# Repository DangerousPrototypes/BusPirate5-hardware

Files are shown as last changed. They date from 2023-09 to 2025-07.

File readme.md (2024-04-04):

# Bus Pirate 5

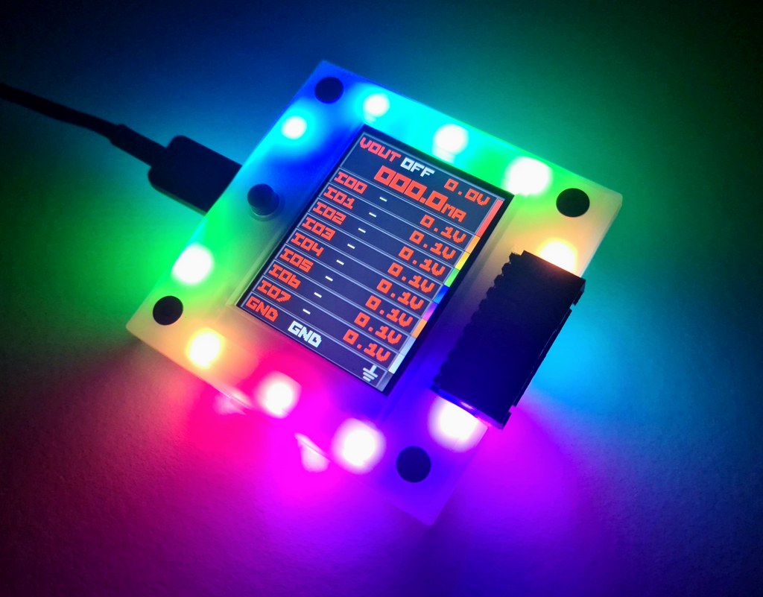
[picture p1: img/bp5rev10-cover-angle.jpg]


Bus Pirate 5 is the latest edition of the universal serial interface trusted by hackers since 2008.

Can't get a chip to work? Is it the circuit, code, bad part or a burned out pin? The Bus Pirate sends commands over common serial protocols (1-Wire, I2C, SPI, UART, MIDI, serial LEDs, etc) so you can get to know a chip before prototyping. Updated with tons of new features, talking to chips and probing interfaces is more fun than ever!

## Resources

- [Download the latest firmware build](https://forum.buspirate.com/t/bus-pirate-5-auto-build-main-branch/20/99999)
- [Get help and chat in the forum](https://forum.buspirate.com/)
- [Firmware documentation](https://firmware.buspirate.com/) ([source](https://github.com/DangerousPrototypes/BusPirate5-docs-firmware))
- [Hardware documentation](https://hardware.buspirate.com/) ([source](https://github.com/DangerousPrototypes/BusPirate5-docs-hardware))
- [Hardware repo](https://github.com/DangerousPrototypes/BusPirate5-hardware)
- [Firmware repo](https://github.com/DangerousPrototypes/BusPirate5-firmware)

## VT100 terminal interface

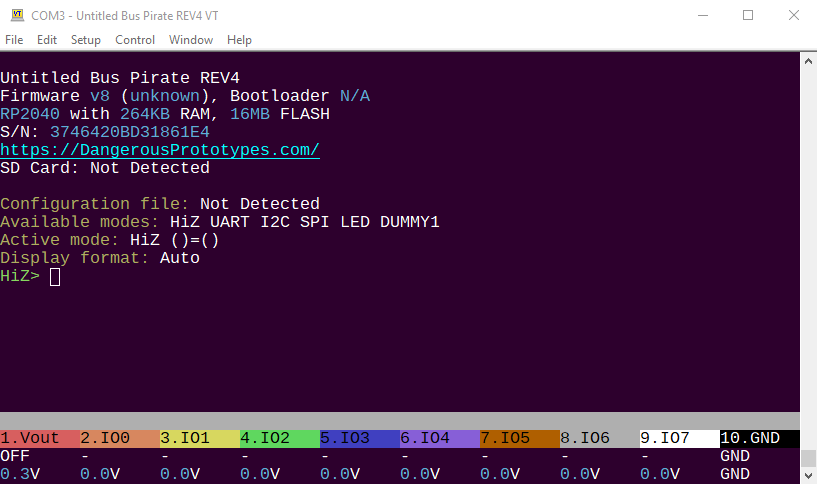
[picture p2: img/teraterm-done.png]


VT100 terminal emulation supports color and a live statusbar view of the voltage and functions on each pin. Type simple commands into the terminal, the Bus Pirate translates them into popular serial protocols and displays the response. Learn how a chip works without touching a line of code.

## Specifications

- Raspberry Pi RP2040 with 128Mbit program flash
- 8 powerful IO pins - Support multiple protocols from 1.2-5volts. Analog voltage measurement and optional 10K pull-ups on all pins
- 1-5volt output power supply - 0-500mA current limit, current sense, resettable fuse and protection circuit
- 1Gbit NAND flash - Store settings and files. Appears as a USB drive.
- LCD - A beautiful 240x320 pixel color IPS (all angle viewing) LCD acts as a pin label, while also showing the voltage on each pin and the current consumption of the programmable power supply unit
- 18 RGB LEDs - It's customary to have an indicator LED, so to check that box we added 16 SK6812 RGB LEDs.
- Just one button - 18 party LEDs but just one button!
- 1-Wire, I2C, SPI, UART, MIDI, serial LEDs supported, more to come!

Bus Pirate 5 is the universal serial interface tool designed by hackers, for hackers. It's crammed full of hardware and firmware features to make probing chips pleasant and easy.

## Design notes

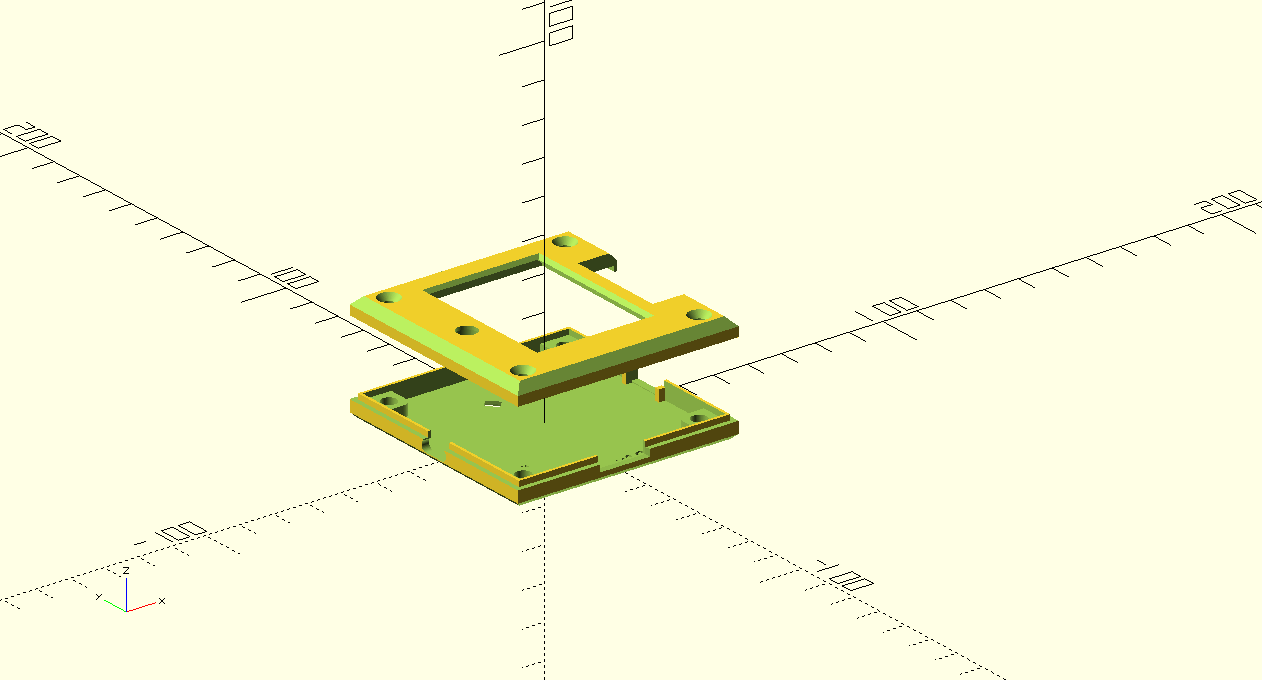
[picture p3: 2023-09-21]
enclosure/BusPirate5REV8-v10-fit.png

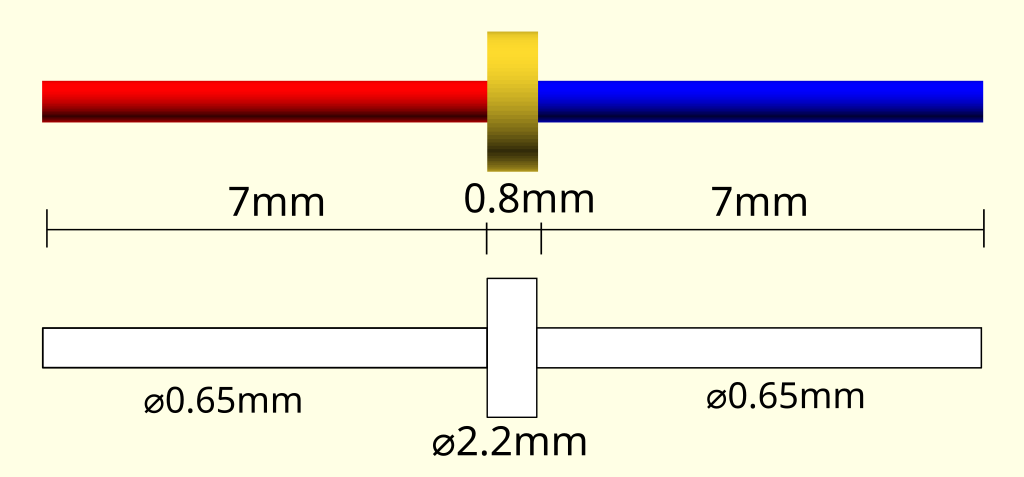
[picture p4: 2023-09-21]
milled-pins/pin-milled-rev2.png

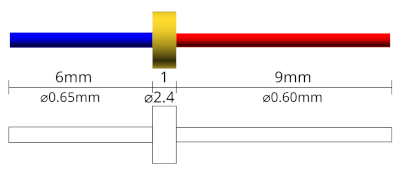
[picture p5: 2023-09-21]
milled-pins/pin-milled-rev1.png

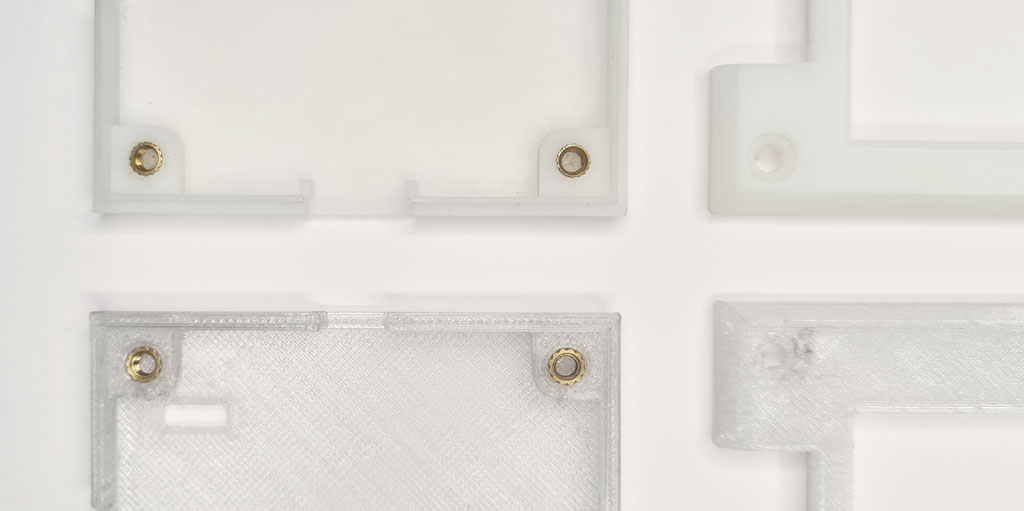
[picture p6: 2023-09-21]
enclosure/heat-set-inserts-bottom.jpg

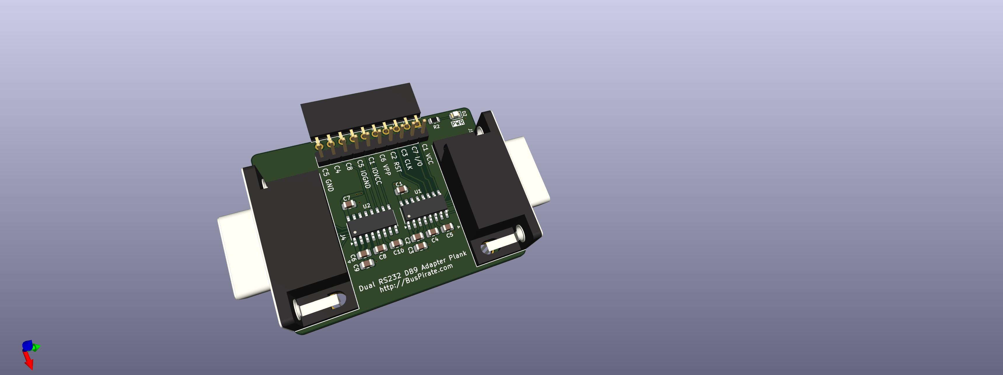
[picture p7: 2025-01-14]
development/adapter-kaybee-plank-1REV0/kaybee-plank.jpg

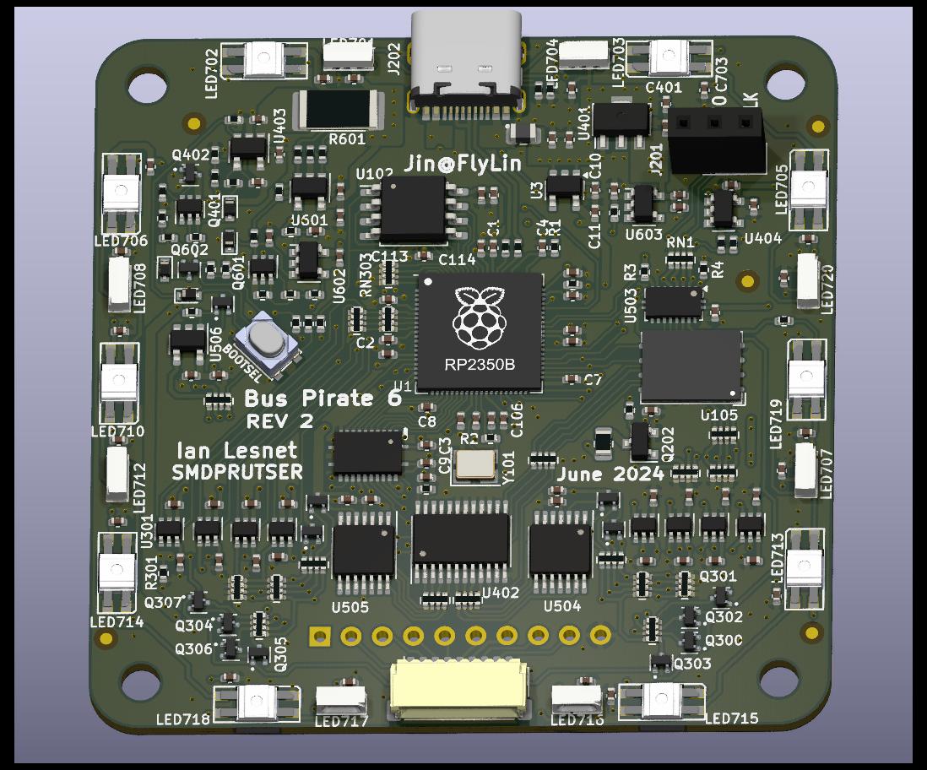
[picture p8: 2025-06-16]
bus_pirate_pcb/6-REV2B/6r2-pcb-top.jpg

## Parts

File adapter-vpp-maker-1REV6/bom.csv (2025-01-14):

Reference | Value | Datasheet | Footprint | Qty | DNP
C13 | 0.1uF | ~ | Capacitor_SMD:C_0805_2012Metric_Pad1.18x1.45mm_HandSolder | 1
C14 | 10uF/16V/CASE-A | ~ | Capacitor_Tantalum_SMD:CP_EIA-3216-18_Kemet-A | 1
C15 | 47uF/25V/CASE-D | ~ | Capacitor_Tantalum_SMD:CP_EIA-7343-31_Kemet-D | 1
D1 | LED | ~ | LED_SMD:LED_0805_2012Metric | 1
D2 | BAT54W | https://assets.nexperia.com/documents/data-sheet/BAT54W_SER.pdf | Package_TO_SOT_SMD:SOT-23 | 1
J1,J2 | Conn_01x10 | ~ | -- mixed values -- | 2
J4 | Conn_01x08 | ~ | Connector_PinHeader_2.54mm:PinHeader_1x08_P2.54mm_Horizontal | 1
L1 | 680uH | ~ | Library:IND-SMD_L5.8-W5.2 | 1
Q1 | MMBT3906 | https://www.onsemi.com/pub/Collateral/2N3906-D.PDF | Package_TO_SOT_SMD:SOT-23 | 1
Q2,Q3,Q4 | MMBT3904 | https://www.onsemi.com/pub/Collateral/2N3903-D.PDF | Package_TO_SOT_SMD:SOT-23 | 3
R1 | 2K | ~ | Resistor_SMD:R_0805_2012Metric | 1
R22 | 4.7K?? | ~ | Resistor_SMD:R_0805_2012Metric | 1
R23 | 100K | ~ | Resistor_SMD:R_0805_2012Metric | 1
R24 | 2.7K | ~ | Resistor_SMD:R_0805_2012Metric | 1
R25,R27,R29 | 10K | ~ | Resistor_SMD:R_0805_2012Metric | 3
R28 | 100R | ~ | Resistor_SMD:R_0805_2012Metric | 1

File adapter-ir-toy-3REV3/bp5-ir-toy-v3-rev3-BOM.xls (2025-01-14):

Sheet: bp5-ir-toy-revC
Source: | C:\buspirate5-hardware\dev\bp5-ir-toy-revC\bp5-ir-toy-revC.kicad_sch
Date: | 6/5/2024 1:26:14 PM
Tool: | Eeschema 7.0.7
Generator: | C:\Program Files\KiCad\7.0\bin\scripting\plugins/bom_csv_grouped_by_value.py
Component Count: | 31
Collated Components:
Item | Qty | Reference(s) | Value | LibPart | Footprint | Datasheet | DNP | Availability | Check_prices | Description | MF | MP | Package | Price | Purchase-URL | Sim.Device | Sim.Pins | Sim.Type | SnapEDA_Link
1 | 3 | C1, C2, C3 | 4.7uF | Device:C | Capacitor_SMD:C_0805_2012Metric | ~
2 | 2 | C4, C5 | 0.22uF | Device:C | Capacitor_SMD:C_0805_2012Metric | ~
3 | 1 | D1 | LED | Device:LED | LED_SMD:LED_0805_2012Metric | ~
4 | 3 | D2, D7, D10 | VSLB3940 | Device:LED | LED_THT:LED_D5.0mm_Horizontal_O1.27mm_Z3.0mm_IRBlack | ~
5 | 6 | D3, D4, D5, D6, D8, D9 | BAS16J/1N4148 | Diode:1N4148W | Diode_SMD:D_SOD-323F | https://www.vishay.com/docs/85748/1n4148w.pdf |  |  |  |  |  |  |  |  |  | D | 1=K 2=A
6 | 1 | J1 | Conn_01x10 | Connector_Generic:Conn_01x10 | Connector_PinSocket_2.54mm:PinSocket_1x10_P2.54mm_Horizontal | ~
7 | 1 | J2 | Conn_01x10 | Connector_Generic:Conn_01x10 | Connector_PinHeader_2.54mm:PinHeader_1x10_P2.54mm_Vertical | ~
8 | 3 | Q1, Q2, Q3 | BC818/S8050 | Simulation_SPICE:NPN | Library:SOT95P237X111-3N | ~ |  |  |  |  |  |  |  |  |  | NPN | 1=C 2=B 3=E | GUMMELPOON
9 | 1 | R1 | 2K | Device:R | Resistor_SMD:R_0805_2012Metric | ~
10 | 3 | R2, R7, R9 | 6R8 | Device:R | Resistor_SMD:R_1206_3216Metric | ~
11 | 3 | R3, R4, R8 | 3K6 | Device:R | Resistor_SMD:R_0805_2012Metric | ~
12 | 2 | R5, R6 | 390R | Device:R | Resistor_SMD:R_0805_2012Metric | ~
13 | 1 | U1 | TSOP4438/ IRM-3638J15 | TSOP4838:TSOP4838 | Library:TSOP18XX |  |  | In Stock | https://www.snapeda.com/parts/TSOP4838/Vishay+Semiconductor+Opto+Division/view-part/?ref=eda | DIODE, IR EMITTING, 38 KHZ, ANGLE OF HALF TRANSMISSION DISTANCE +/-45DEG/C | Vishay / Small Signal & Opto Products (SSP) TSOP4838 | Vishay | TSOP4838 | DIP-3 Vishay | None | https://www.snapeda.com/api/url_track_click_mouser/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 |  |  |  | https://www.snapeda.com/parts/TSOP4838/Vishay+Semiconductor+Opto+Division/view-part/?ref=snap
14 | 1 | U3 | QSE159 | Interface_Optical:QSE159 | OptoDevice:ONSemi_QSE15x | http://www.onsemi.com/pub/Collateral/QSE159-D.pdf
 |  |  | IRM-3638J15 | EVERLIGHT | 单价1.0
 |  |  | VSLB3940 | VISHAY | 单价2.1

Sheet: Sharp-appnote
I (Current) | 100 | 100 | 200 | 200 | 300 | 300 |  | TSAL6100 | 1N4148
VCC | 5 | 4.75 | 5 | 4.75 | 5 | 4.75
Vz | 1.4 | 1.4 | 2 | 2 | 2.2 | 2.2
Vbe | 0.9 | 0.9 | 0.95 | 0.95 | 1 | 1
Vce(sat) | 0.1 | 0.1 | 0.18 | 0.18 | 0.25 | 0.25
Vf | 1.35 | 1.35 | 1.5 | 1.5 | 1.6 | 1.6
N< | 3.259259259 | 3.074074074 | 2.513333333 | 2.346666667 | 2.21875 | 2.0625
 |  |  |  |  |  |  | hFE | Vbe | Vce(sat)

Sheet: sensors
 | Model | Frequency | Typical Application | Note | Everlight | Opti-fake |  |  |  |  | Barrier | C | R | Pullup
Vishay | TSSP4038 (3元) | 38kHz | Barrier | Widely Available | IRM-3638J7(1.6元) |  |  |  |  |  | TSSP4038 (3元) | 0.1uF | 100R | X
Vishay | TSMP58000 | 20 → 60kHz | Learner | Obsolete |  | OS1200MW-A1 (3元) (http://os-opto.com/wap/acp_view.asp?id=235) |  |  |  |  | IRM-3638J7(1.6元) | >2.2uF | 47-200R | >10K
Vishay |  | 20 → 60kHz | Learner | New TSMP58000 |  |  |  |  |  |  | Learner
Vishay | TSOP34436 (8元) | 36kHz | RC5/6 |  |  |  |  |  |  |  | TSMP98000 (7元) | 4.7uF | 100R | 4.7K
Vishay | TSOP34438 (8元) | 38kHz | NEC |  | IRM-3638T (0.78元) | OS-883YM-MS (1.2元) (http://os-opto.com/wap/acp_view.asp?id=195) |  |  |  |  | OS1200MW-A1 (3元) (http://os-opto.com/wap/acp_view.asp?id=235) | 0.1uF + 10-47uF | 47/10 (5V/3V) | ??? 10K?
Vishay | TSOP4840 (5元) | 40kHz | SONY |  |  |  |  |  |  |  | 38kHz
Vishay | TSOP2256 (5元) | 56kHz | RCA | EOL |  |  |  |  |  |  | TSOP34438 (8元) | Unk | Unk | X
 |  |  |  |  |  |  |  |  |  |  | OS-883YM-MS (1.2元) (http://os-opto.com/wap/acp_view.asp?id=195) | >47uF | 100R | >10K
 |  |  |  |  |  |  |  |  |  |  | IRM-3638T (0.78元) | >2.2uF | 47-200R | >10K
 |  |  |  |  |  |  |  |  |  |  | 56kHz
 |  |  |  |  |  |  |  |  |  |  | TSOP2256 (5元) | Unk | Unk | X
 |  |  |  | Sensor | Brand | Part | C | R | Pull-up | Cost
 |  |  |  | Barrier | Everlight | IRM-3638J7 | 4.7uF | 100R | 10K | 1.6
 |  |  |  | Learner | Os-opto | OS1200MW-A1 (http://os-opto.com/wap/acp_view.asp?id=235) | 4.7uF | 100R | 10K | 3
 |  |  |  | 38kHz (36-40kHz effective) | Everlight | IRM-3638T | 4.7uF | 100R | 10K | 0.78 | 9 learner with 10K
 |  |  |  | 56kHz | CHQ | CHQ0038L-56kHz | 4.7uF | 100R | >20K?? | 0.78

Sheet: TX current
 |  |  |  |  |  |  |  |  |  |  |  |  |  | Head room for dissipation, negative is bad :)
IR LED | IR LED Vf | IR LED Ie (mA) | Diode (D2/D3) | D2/D3 Vf | Transistor (T1) | T1 Vfp-n | T1 Dissipation (W) | Vb | Vbe | Ve | R4 (Ohms) | R4 P (Watts) | T1 P (Watts) | T1 P (spare) | R5 (K Ohms)
Generic | 1.35 | 100 | BAS16J | 0.7 | BC818 | 0.7 | 0.31 | 1.4 | 0.7 | 0.7 | 7 | 0.07 | 0.295 | 0.015 | 3.6
VSLB3940 | 1.35 | 100 | BAS16J (actual) | 0.715 | BC818 (actual) | 0.7 | 0.225 | 1.43 | 0.7 | 0.73 | 7.3 | 0.07 | 0.292 | -0.067 | 3.57
VSLB3940 | 2.7 | 300 | 1N4148 | 0.715 | S8050 | 0.7 | 0.3 | 1.43 | 0.7 | 0.73 | 2.433333333 | 0.21 | 0.471 | -0.171 | 3.57
2 * TASL6100 | 3.2 | 300 |  | 1.1 |  | 1 | 0.3 | 2.2 | 1 | 1.2 | 4 | 0.3 | 0.18 | 0.12 | 2.8
 | 3.2 | 200 |  | 1.1 |  | 1 | 0.3 | 2.2 | 1 | 1.2 | 6 | 0.2 | 0.12 | 0.18 | 2.8
Ie is emitter current (typically 100ma)
Vb is the combined Vf of diodes D2 and D3 (see datasheet), typically 0.7V. Vb = Vf_D2 + Vf_D3 = (0.7V + 0.7V) = 1.4V
Vbe is the Vf the transistor p-n union (see datasheet), typically 0.7V
Solving R4 for 100mA current with a BC818 transistor, and BAS16J diode:
R4 = Ve/Ie =(((Vf_D2 + Vf_D3)-Vbe)/Ie) = ((1.4V - 0.7V)/100mA) = 7ohms |  |  |  |  |  |  |  |  |  | 0.1748251748
Resistor power dissipation is well below the 0.125W max of the 1206 resistor used for R4:
P = Ie * Vbe = (100mA*0.7V) = 0.070W
For an IR LED with a forward voltage (Vf) of 1.35 volts the power dissipation is 0.295W, nearly the rated 0.310W of the BC818 transistor in an SOT-23 package. This is probably fine because we’re calculating the worst case scenario of a continues 100mA load, IR transmissions are likely to be short and at a 50% duty cycle.
P =((Vcc-Vf_IRDIODE) - Ve ) * Ie = ((5.0V-1.35V)-0.7V)*100mA = 0.295W
R5 puts the transistor in saturation and limits the current through diodes D2 and D3. For 1mA at 5volts:
R5 = (Vcc - Vb)/I_limit = ((5V-1.4V)/1mA) = 3600ohms

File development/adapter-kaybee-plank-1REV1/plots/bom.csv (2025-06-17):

Item | Qty | Reference(s) | Value | Footprint | szlcsc_partnum
1 | 3 | C1, C2, C3 | 47uF/CL21A226MAYNNNE | Capacitor_SMD:C_0805_2012Metric | C602037
2 | 1 | D2 | LED | LED_SMD:LED_0805_2012Metric
3 | 1 | D401 | 1N4148WT | Diode_SMD:D_SOD-523 | C2828426
4 | 2 | J1, J4 | Mini-DIN-6 | connector-mini-din-6:Connector_Mini-DIN_Female_6Pin_2rows | C77848
5 | 1 | J2 | Conn_01x10 | Connector_PinSocket_2.54mm:PinSocket_1x10_P2.54mm_Horizontal
6 | 1 | J5 | USB_A | Connector_USB:USB_A_CONNFLY_DS1095-WNR0 | C456018
7 | 1 | J7 | TYPE-C-31-M-12 | TYPE-C-31-M-12:HRO_TYPE-C-31-M-12 | C2858270
8 | 2 | J8, J9 | Conn_01x02_Pin | Connector_PinHeader_2.54mm:PinHeader_1x02_P2.54mm_Vertical | C2905434
9 | 4 | L1, L2, L4, L5 | CBW201209U300T | Inductor_SMD:L_0805_2012Metric | C139190
10 | 1 | Q401 | BCM857BS-7-F | Package_TO_SOT_SMD:SOT-363_SC-70-6 | C105896
11 | 1 | Q402 | BC2301T 2.8A | Package_TO_SOT_SMD:SOT-523 | C21714127
12 | 2 | R1, R5 | 5.1K | Resistor_SMD:R_0805_2012Metric | C27834
13 | 2 | R2, R3 | 2K | Resistor_SMD:R_0805_2012Metric | C2907315
14 | 1 | R408 | 68K | Resistor_SMD:R_0805_2012Metric | C17801
15 | 1 | R410 | 10K | Resistor_SMD:R_0805_2012Metric | C17414
16 | 1 | R412 | 100K | Resistor_SMD:R_0805_2012Metric | C149504
17 | 1 | SW1 | SW_SPDT | Button_Switch_SMD:SW_SPDT_PCM12 | C431540

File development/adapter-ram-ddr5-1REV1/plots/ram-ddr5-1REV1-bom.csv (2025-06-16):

Item | Qty | Reference(s) | Value | Footprint | szlcsc_partnum
1 | 2 | C4, C5 | 10uF/6.3V | Capacitor_SMD:C_0805_2012Metric | C307525
2 | 2 | D2, D3 | LED | LED_SMD:LED_0805_2012Metric
3 | 1 | J1 | DDR504111002KQ | footprints:AMPHENOL_DDR504111002KQ
4 | 1 | J2 | Conn_01x10 | Connector_PinSocket_2.54mm:PinSocket_1x10_P2.54mm_Horizontal
6 | 1 | J4 | 10160554-001SHLF | footprints:AMPHENOL_10160554-001SHLF
7 | 2 | Q1, Q2 | BSS138 | Package_TO_SOT_SMD:SOT-23 | C65189
8 | 1 | Q5 | BC807 | Package_TO_SOT_SMD:SOT-23 | C21714130
9 | 1 | Q6 | BC817 | Package_TO_SOT_SMD:SOT-23 | C39828
10 | 3 | R2, R12, R13 | 6.8K | Resistor_SMD:R_0805_2012Metric | C17772
11 | 4 | R3, R4, R6, R7 | 10K | Resistor_SMD:R_0805_2012Metric | C17604
12 | 1 | R8 | 1K | Resistor_SMD:R_0805_2012Metric | C17513
13 | 1 | R10 | 680R | Resistor_SMD:R_0805_2012Metric | C17798
14 | 1 | R11 | 330R | Resistor_SMD:R_0805_2012Metric | C17630
15 | 1 | U2 | ME6206A33XG | Package_TO_SOT_SMD:SOT-23 | C161345

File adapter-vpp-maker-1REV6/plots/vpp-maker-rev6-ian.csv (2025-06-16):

Source: | C:\buspirate5-hardware\vpp-maker-rev6-ian\vpp-maker-rev6-ian.kicad_sch
Date: | 2024-08-13T17:15:38+0200
Tool: | Eeschema 8.0.3
Generator: | C:\Program Files\KiCad\8.0\bin\scripting\plugins/bom_csv_grouped_by_value.py
Component Count: | 22
Collated Components:
Item | Qty | Reference(s) | Value | LibPart | Footprint | Datasheet | DNP | Datasheet | Description | Footprint | MPN
1 | 1 | C13 | 0.1uF | Device:C_Small | Capacitor_SMD:C_0805_2012Metric_Pad1.18x1.45mm_HandSolder | ~ |  | ~ | Unpolarized capacitor, small symbol | Capacitor_SMD:C_0805_2012Metric_Pad1.18x1.45mm_HandSolder
2 | 1 | C14 | 10uF/16V/CASE-A | Device:C_Polarized | Capacitor_Tantalum_SMD:CP_EIA-3216-18_Kemet-A | ~ |  | ~ | Polarized capacitor | Capacitor_Tantalum_SMD:CP_EIA-3216-18_Kemet-A
3 | 1 | C15 | 47uF/25V/CASE-D | Device:C_Polarized | Capacitor_Tantalum_SMD:CP_EIA-7343-31_Kemet-D | ~ |  | ~ | Polarized capacitor | Capacitor_Tantalum_SMD:CP_EIA-7343-31_Kemet-D
4 | 1 | D1 | LED | Device:LED | LED_SMD:LED_0805_2012Metric | ~ |  | ~ | Light emitting diode | LED_SMD:LED_0805_2012Metric
5 | 1 | D2 | BAT54W | Diode:BAT54W | Package_TO_SOT_SMD:SOT-23 | https://assets.nexperia.com/documents/data-sheet/BAT54W_SER.pdf |  | https://assets.nexperia.com/documents/data-sheet/BAT54W_SER.pdf | Schottky barrier diode, SOT-323 | Package_TO_SOT_SMD:SOT-23
6 | 1 | D3 | BZT52C18W (18V) | Device:D_Zener_Small | Diode_SMD:D_SOD-123 | ~ |  | ~ | Zener diode, small symbol | Diode_SMD:D_SOD-123
7 | 1 | D4 | BZT52C4V7W (4.7V) | Device:D_Zener_Small | Diode_SMD:D_SOD-123 | ~ |  | ~ | Zener diode, small symbol | Diode_SMD:D_SOD-123
8 | 1 | J1 | Conn_01x10 | Connector_Generic:Conn_01x10 | Connector_PinSocket_2.54mm:PinSocket_1x10_P2.54mm_Horizontal | ~ |  | ~ | Generic connector, single row, 01x10, script generated (kicad-library-utils/schlib/autogen/connector/) | Connector_PinSocket_2.54mm:PinSocket_1x10_P2.54mm_Horizontal
9 | 1 | J4 | Conn_01x08 | Connector_Generic:Conn_01x08 | Connector_PinHeader_2.54mm:PinHeader_1x08_P2.54mm_Horizontal | ~ |  | ~ | Generic connector, single row, 01x08, script generated (kicad-library-utils/schlib/autogen/connector/) | Connector_PinHeader_2.54mm:PinHeader_1x08_P2.54mm_Horizontal
10 | 1 | L1 | 680uH | Device:L | Library:L_YP0504 | ~ |  | ~ | Inductor | Library:L_YP0504 | YP0504-681M
11 | 1 | Q1 | MMBT3906 | :MMBT3906_1 | Package_TO_SOT_SMD:SOT-23 | https://www.onsemi.com/pub/Collateral/2N3906-D.PDF |  | https://www.onsemi.com/pub/Collateral/2N3906-D.PDF | -0.2A Ic, -40V Vce, Small Signal PNP Transistor, SOT-23 | Package_TO_SOT_SMD:SOT-23
12 | 3 | Q2, Q3, Q4 | MMBT3904 | :MMBT3904_1 | Package_TO_SOT_SMD:SOT-23 | https://www.onsemi.com/pub/Collateral/2N3903-D.PDF |  | https://www.onsemi.com/pub/Collateral/2N3903-D.PDF | 0.2A Ic, 40V Vce, Small Signal NPN Transistor, SOT-23 | Package_TO_SOT_SMD:SOT-23
13 | 1 | R1 | 2K | Device:R | Resistor_SMD:R_0805_2012Metric | ~ |  | ~ | Resistor | Resistor_SMD:R_0805_2012Metric
14 | 1 | R22 | 9K1 | Device:R | Resistor_SMD:R_0805_2012Metric | ~ |  | ~ | Resistor | Resistor_SMD:R_0805_2012Metric
15 | 1 | R23 | 100K | Device:R | Resistor_SMD:R_0805_2012Metric | ~ |  | ~ | Resistor | Resistor_SMD:R_0805_2012Metric
16 | 1 | R24 | 3K3 | Device:R | Resistor_SMD:R_0805_2012Metric | ~ |  | ~ | Resistor | Resistor_SMD:R_0805_2012Metric
17 | 3 | R25, R27, R29 | 10K | Device:R | Resistor_SMD:R_0805_2012Metric | ~ |  | ~ | Resistor | Resistor_SMD:R_0805_2012Metric
18 | 1 | R28 | 100R | Device:R | Resistor_SMD:R_0805_2012Metric | ~ |  | ~ | Resistor | Resistor_SMD:R_0805_2012Metric

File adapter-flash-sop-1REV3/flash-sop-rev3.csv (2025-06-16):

Source: | C:\buspirate5-hardware\adapters_wip\flash-tht-sockets\flash-sop.kicad_sch
Date: | 4/2/2024 5:03:58 PM
Tool: | Eeschema 7.0.7
Generator: | C:\Program Files\KiCad\7.0\bin\scripting\plugins/bom_csv_grouped_by_value.py
Component Count: | 10
Collated Components:
Item | Qty | Reference(s) | Value | LibPart | Footprint | Datasheet | DNP
1 | 2 | C1, C2 | 0.1uF | Device:C_Small | Capacitor_SMD:C_0805_2012Metric | ~
2 | 1 | D1 | LED | Device:LED | LED_SMD:LED_0805_2012Metric | ~
3 | 1 | J1 | Conn_01x10 | Connector_Generic:Conn_01x10 | Connector_PinSocket_2.54mm:PinSocket_1x10_P2.54mm_Horizontal | ~
4 | 1 | J2 | Conn_01x10 | Connector_Generic:Conn_01x10 | Connector_PinHeader_2.54mm:PinHeader_1x10_P2.54mm_Vertical | ~
5 | 1 | J3 | 16PIN | Connector_Generic:Conn_02x08_Counter_Clockwise | TEST_SOCKETS:16PIN_SCOKET | ~
6 | 1 | J5 | 20PIN | Connector_Generic:Conn_02x10_Counter_Clockwise | TEST_SOCKETS:20PIN_SCOKET | ~
7 | 1 | R1 | 2K | Device:R | Resistor_SMD:R_0805_2012Metric | ~
8 | 2 | SW1, SW2 | SW_SPDT | Switch:SW_SPDT | Button_Switch_SMD:SW_SPDT_PCM12 | ~

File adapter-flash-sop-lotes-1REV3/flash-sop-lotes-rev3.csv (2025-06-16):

Source: | C:\buspirate5-hardware\flash-sop-lotes-rev3\flash-sop-lotes-rev3.kicad_sch
Date: | 6/18/2024 2:34:58 PM
Tool: | Eeschema 7.0.7
Generator: | C:\Program Files\KiCad\7.0\bin\scripting\plugins/bom_csv_grouped_by_value.py
Component Count: | 10
Collated Components:
Item | Qty | Reference(s) | Value | LibPart | Footprint | Datasheet | DNP
1 | 2 | C1, C2 | 0.1uF | Device:C | Capacitor_SMD:C_0805_2012Metric | ~
2 | 1 | D1 | LED | Device:LED | LED_SMD:LED_0805_2012Metric | ~
3 | 1 | J1 | Conn_01x10 | Connector_Generic:Conn_01x10 | Connector_PinSocket_2.54mm:PinSocket_1x10_P2.54mm_Horizontal | ~
4 | 1 | J2 | Conn_01x10 | Connector_Generic:Conn_01x10 | Connector_PinHeader_2.54mm:PinHeader_1x10_P2.54mm_Vertical | ~
5 | 1 | R1 | 2K | Device:R | Resistor_SMD:R_0805_2012Metric | ~
6 | 2 | SW1, SW2 | SW_SPDT | Switch:SW_SPDT | Button_Switch_SMD:SW_SPDT_PCM12 | ~
7 | 1 | U1 | 25LCxxx | Memory_EEPROM:25LCxxx | TEST_SOCKETS:ASPI0001-P001A | http://ww1.microchip.com/downloads/en/DeviceDoc/21832H.pdf
8 | 1 | U2 | 25LCxxx | Memory_EEPROM:25LCxxx | TEST_SOCKETS:ACA-SPI-004-K01 | http://ww1.microchip.com/downloads/en/DeviceDoc/21832H.pdf

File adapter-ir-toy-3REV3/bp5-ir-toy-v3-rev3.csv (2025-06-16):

Source: | C:\buspirate5-hardware\bp5-ir-toy-v3-rev3\bp5-ir-toy-v3-rev3.kicad_sch
Date: | 2024-08-13T16:58:07+0200
Tool: | Eeschema 8.0.3
Generator: | C:\Program Files\KiCad\8.0\bin\scripting\plugins/bom_csv_grouped_by_value.py
Component Count: | 34
Collated Components:
Item | Qty | Reference(s) | Value | Footprint
1 | 5 | C1, C2, C3, C4, C5 | 4.7uF | Capacitor_SMD:C_0805_2012Metric
2 | 1 | C6 | 100uF | Capacitor_Tantalum_SMD:CP_EIA-3528-21_Kemet-B_Pad1.50x2.35mm_HandSolder
3 | 2 | C7, C8 | 0.1uF | Capacitor_SMD:C_0805_2012Metric
4 | 1 | D1 | LED | LED_SMD:LED_0805_2012Metric
5 | 1 | D3 | TSAL6100 | LED_THT:LED_D5.0mm_Horizontal_O1.27mm_Z3.0mm_IRGrey
6 | 1 | D4 | TSAL6200 | LED_THT:LED_D5.0mm_Horizontal_O1.27mm_Z3.0mm_IRGrey
7 | 2 | D9, D10 | 1N4148WS | Diode_SMD:D_SOD-323F
8 | 1 | J1 | Conn_01x10 | Connector_PinSocket_2.54mm:PinSocket_1x10_P2.54mm_Horizontal
9 | 1 | J3 | Conn_02x03_1.27mm | Connector_PinHeader_1.27mm:PinHeader_2x03_P1.27mm_Vertical
10 | 1 | Q3 | MMBT4401LT1G | Package_TO_SOT_SMD:SOT-23
11 | 4 | R1, R4, R7, R8 | 100R | Resistor_SMD:R_0805_2012Metric
12 | 3 | R2, R5, R9 | 10K | Resistor_SMD:R_0805_2012Metric
13 | 1 | R3 | 330R | Resistor_SMD:R_0805_2012Metric
14 | 1 | R6 | 1R2 | Resistor_SMD:R_1206_3216Metric
15 | 1 | R10 | 2K | Resistor_SMD:R_0805_2012Metric
16 | 1 | R11 | 3R0 | Resistor_SMD:R_1206_3216Metric
17 | 1 | R12 | 20K | Resistor_SMD:R_0805_2012Metric
18 | 1 | R13 | 6R8 | Resistor_SMD:R_1206_3216Metric
19 | 1 | U1 | OS1200MW-A1 | Library:TSOP18XX
20 | 1 | U2 | IRM-3638J7 | Library:TSOP18XX
21 | 1 | U3 | IRM-3638T | Library:TSOP18XX
22 | 1 | U4 | CHQ0038L-56kHz | Library:TSOP18XX
23 | 1 | U5 | AiP74LVC1T45GC363.TR | Package_TO_SOT_SMD:SOT-363_SC-70-6

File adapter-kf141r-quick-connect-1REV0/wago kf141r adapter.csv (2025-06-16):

Source: | C:\buspirate5-hardware\kf141r-adapter\wago kf141r adapter.kicad_sch
Date: | 12/27/2023 11:54:16 AM
Tool: | Eeschema 7.0.7
Generator: | C:\Program Files\KiCad\7.0\bin\scripting\plugins/bom_csv_grouped_by_value.py
Component Count: | 2
Collated Components:
Item | Qty | Reference(s) | Value | LibPart | Footprint | Datasheet | DNP
1 | 1 | J1 | Conn_01x10 | Connector_Generic:Conn_01x10 | Connector_PinSocket_2.54mm:PinSocket_1x10_P2.54mm_Horizontal | ~
2 | 1 | J2 | Conn_01x10 | Connector_Generic:Conn_01x10 | dp_connector:wago_kf141r_2.54 | ~

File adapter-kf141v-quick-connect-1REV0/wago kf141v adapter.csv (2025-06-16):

Source: | C:\buspirate5-hardware\kf141v-adapter\wago kf141v adapter.kicad_sch
Date: | 12/27/2023 4:02:54 PM
Tool: | Eeschema 7.0.7
Generator: | C:\Program Files\KiCad\7.0\bin\scripting\plugins/bom_csv_grouped_by_value.py
Component Count: | 2
Collated Components:
Item | Qty | Reference(s) | Value | LibPart | Footprint | Datasheet | DNP
1 | 1 | J1 | Conn_01x10 | Connector_Generic:Conn_01x10 | Connector_PinSocket_2.54mm:PinSocket_1x10_P2.54mm_Horizontal | ~
2 | 1 | J2 | Conn_01x10 | Connector_Generic:Conn_01x10 | dp_connector:wago_kf141v_2.54 | ~

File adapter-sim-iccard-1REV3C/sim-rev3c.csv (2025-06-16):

Source: | C:\buspirate5-hardware\adapters_wip\rev3\sim-rev3c\sim-rev3c.kicad_sch
Date: | 4/19/2024 4:16:38 PM
Tool: | Eeschema 7.0.7
Generator: | C:\Program Files\KiCad\7.0\bin\scripting\plugins/bom_csv_grouped_by_value.py
Component Count: | 12
Collated Components:
Item | Qty | Reference(s) | Value | LibPart | Footprint | Datasheet | DNP | Availability | Check_prices | Comment | Description | EU_RoHS_Compliance | MANUFACTURER | MF | MP | PARTREV | Package | Price | Purchase-URL | STANDARD | SnapEDA_Link
1 | 2 | D1, D2 | LED | Device:LED | LED_SMD:LED_0805_2012Metric | ~
2 | 1 | J1 | 5145300-3 | 5145300-3:5145300-3 | footprints:TE_5145300-3 |  |  | In Stock | https://www.snapeda.com/parts/5145300-3/TE+Connectivity+AMP+Connectors/view-part/?ref=eda | 5145300-3 | Conn Smart Card RCP 8 POS 2.54mm Solder ST SMD Tray | Compliant | TE Connectivity | TE Connectivity | 5145300-3 | C3 | None | None | https://www.snapeda.com/api/url_track_click_mouser/?unipart_id=543619&manufacturer=TE Connectivity&part_name=5145300-3&search_term=smart card connector | Manufacturer recommendations | https://www.snapeda.com/parts/5145300-3/TE+Connectivity+AMP+Connectors/view-part/?ref=snap
3 | 1 | J2 | Conn_01x10 | Connector_Generic:Conn_01x10 | Connector_PinSocket_2.54mm:PinSocket_1x10_P2.54mm_Horizontal | ~
4 | 1 | J3 | Conn_01x10 | Connector_Generic:Conn_01x10 | Connector_PinHeader_2.54mm:PinHeader_1x10_P2.54mm_Vertical | ~
5 | 2 | R1, R2 | 2K | Device:R | Resistor_SMD:R_0805_2012Metric | ~
6 | 2 | SW1, SW2 | SW_SPDT | Switch:SW_SPDT | Button_Switch_SMD:SW_SPDT_PCM12 | ~
7 | 1 | U1 | SIM 6P | sim card:SIM 6P | footprints2:DGLZ-SIM-0004
8 | 1 | U2 | SIM 8P | sim card:SIM 8P | SIM_CARDS:SIM-0030
9 | 1 | U3 | SIM 6P | sim card:SIM 6P | SIM_CARDS:SIM-0036

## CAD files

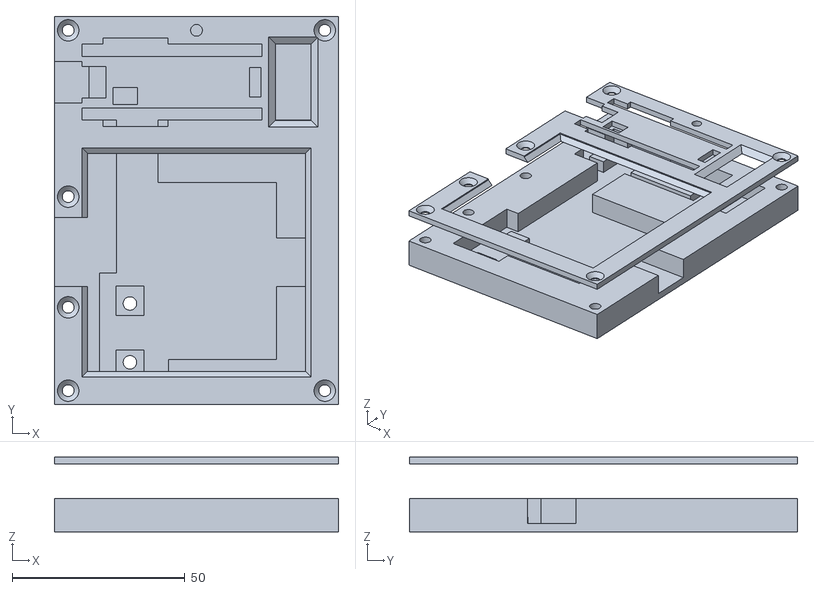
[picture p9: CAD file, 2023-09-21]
debug-station/debug-station-v3.stl
82.2 x 112.2 x 21.6

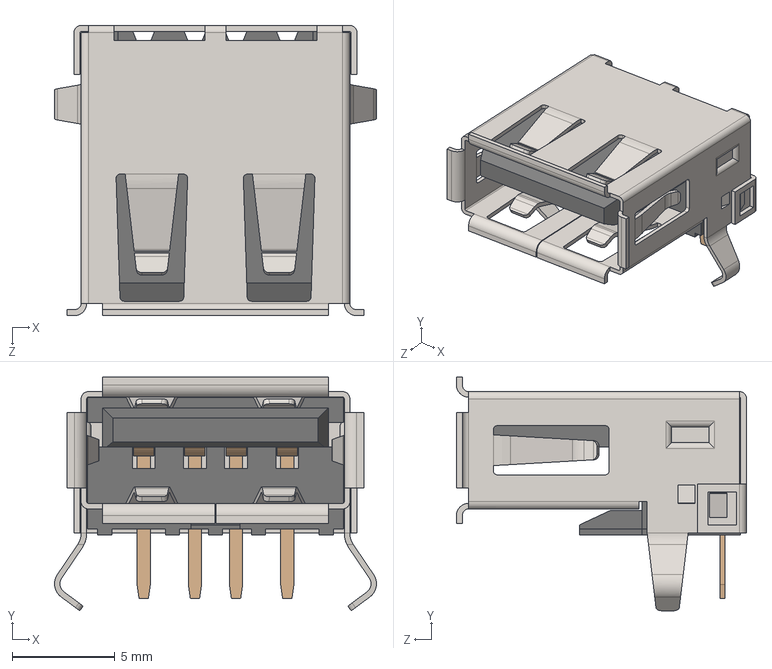
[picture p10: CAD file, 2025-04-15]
development/adapter-kaybee-plank-1REV0/footprints/USB Connector Type A female.STEP
15.7 x 11.4 x 14.1 mm

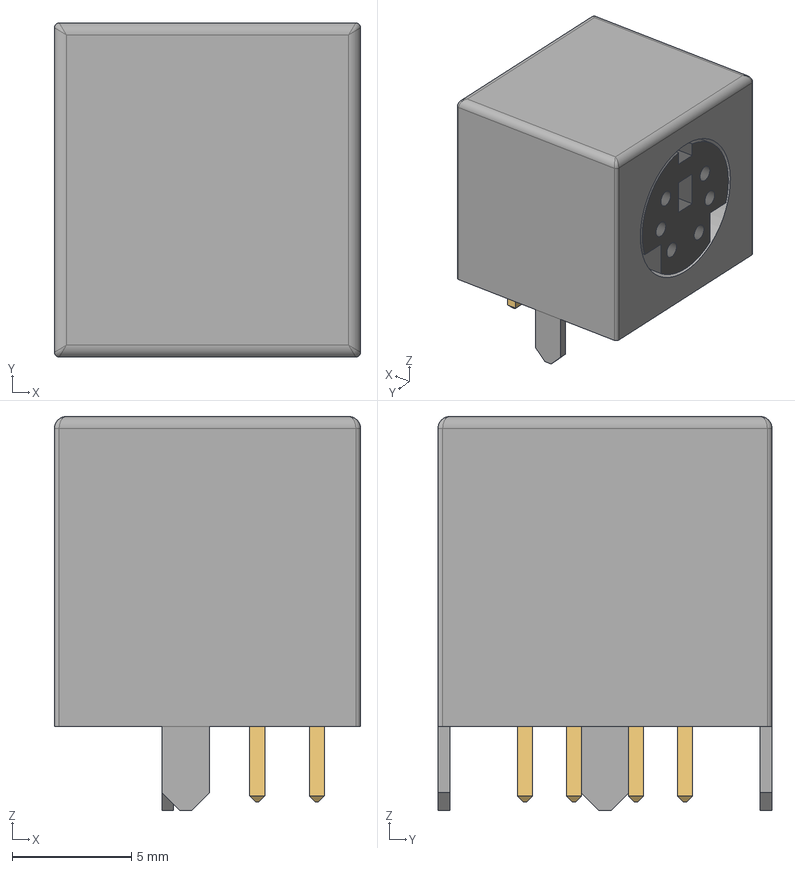
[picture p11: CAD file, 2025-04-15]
development/adapter-kaybee-plank-1REV1/footprints/Mini-DIN-6P.step
12.8 x 14.0 x 16.5 mm

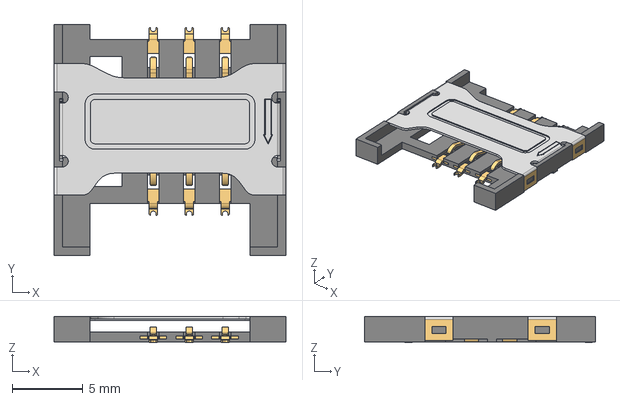
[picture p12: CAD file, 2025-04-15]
development/adapter-sim-iccard-1REV4/footprints/DGLZ-SIM-0004.step
16.4 x 16.3 x 1.85 mm

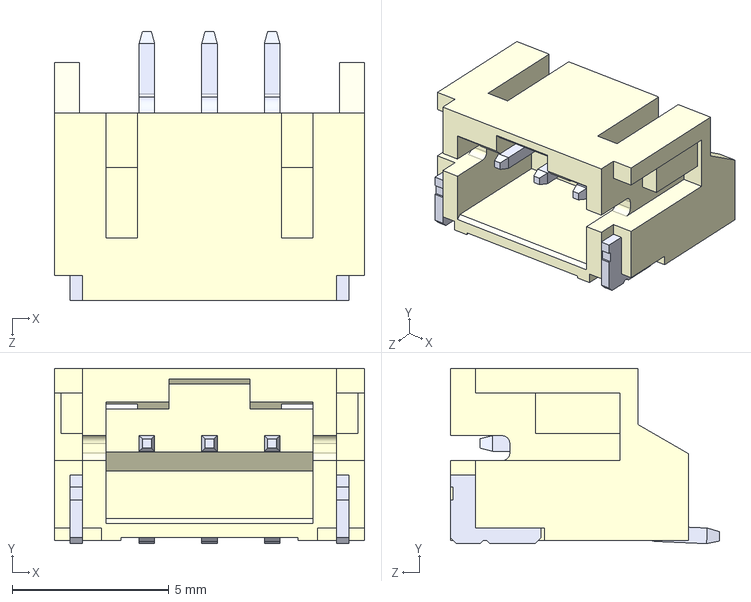
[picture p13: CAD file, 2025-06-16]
development/adapter-stemma-qwiic-grove-gravity-bog-plank-1REV1/footprints/S3B-PH-SM4-TB(LF)(SN)--3DModel-STEP-56544.STEP
9.90 x 5.60 x 8.60 mm

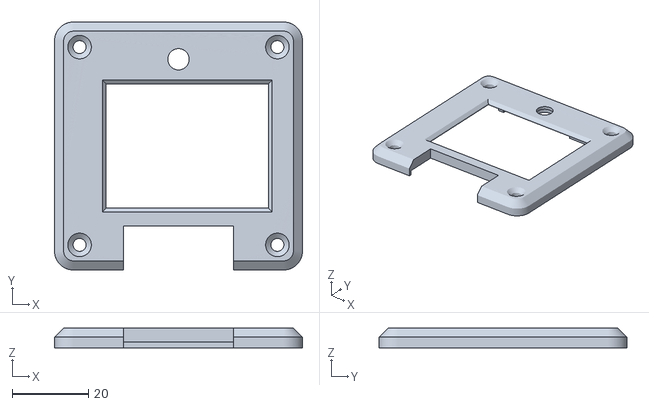
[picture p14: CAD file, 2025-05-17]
enclosure/BusPirate-enclosure-v2-a.stl
65.2 x 65.2 x 5.20

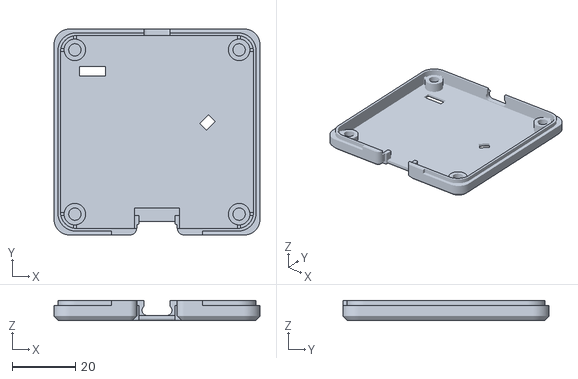
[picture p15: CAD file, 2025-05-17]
enclosure/BusPirate-enclosure-v2-b.stl
65.2 x 65.2 x 6.40

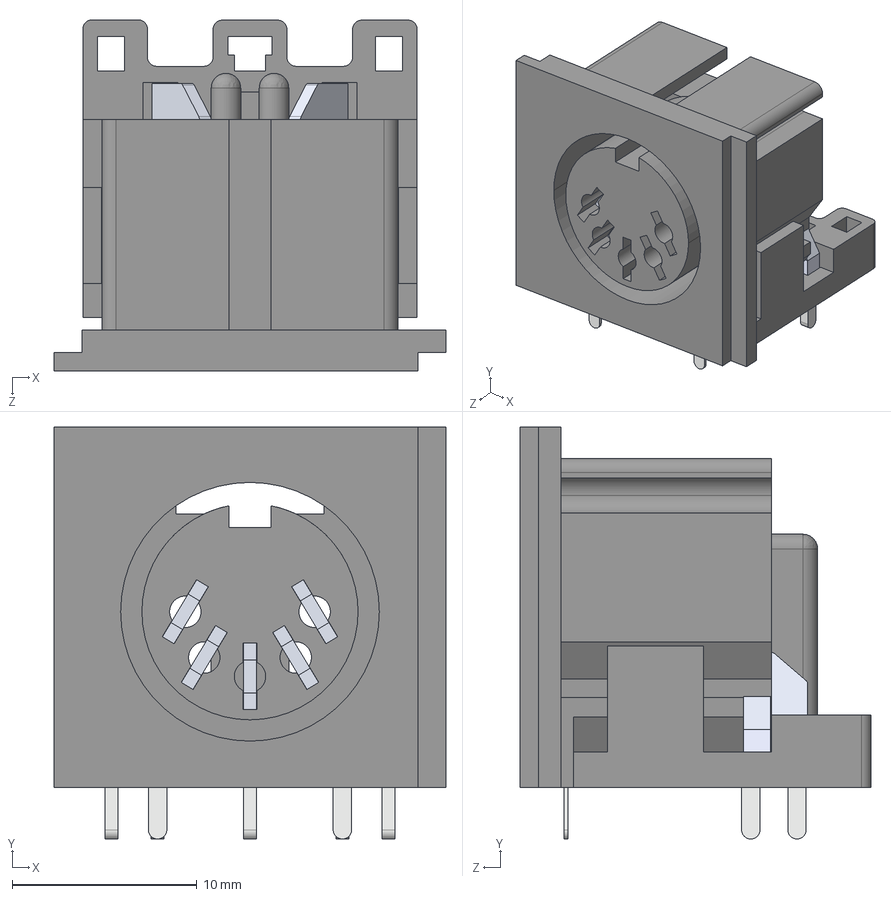
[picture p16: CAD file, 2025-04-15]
development/adapter-kaybee-plank-1REV0/footprints/User Library-DIN-5.STEP
21.2 x 22.3 x 19.0 mm
DIN5 A
DIN5 B
DIN5 C
DIN D x 2
DIN E x 2
DIN EE x 2
DIN G
DIN DD x 2

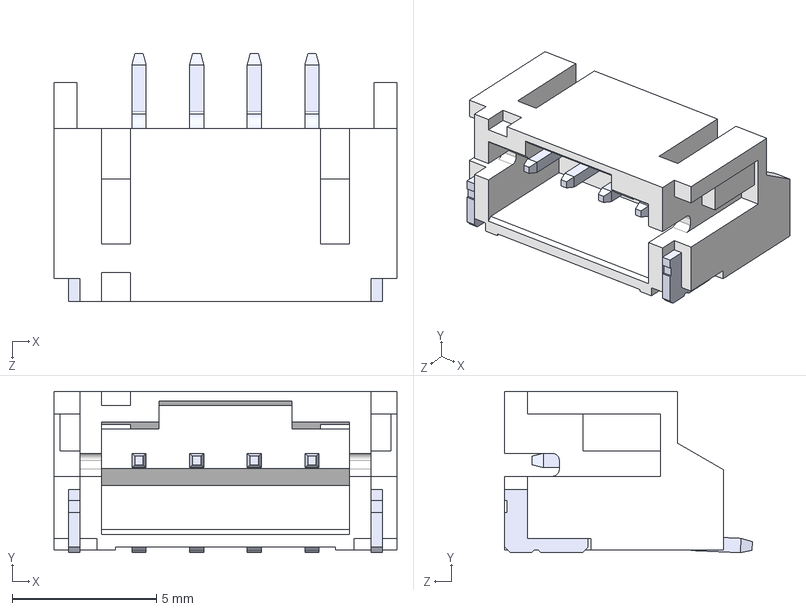
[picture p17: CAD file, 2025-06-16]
development/adapter-stemma-qwiic-grove-gravity-bog-1REV0/footprints/S4B-PH-SM4-TB(LF)(SN)--3DModel-STEP-56544.STEP
11.9 x 5.60 x 8.60 mm

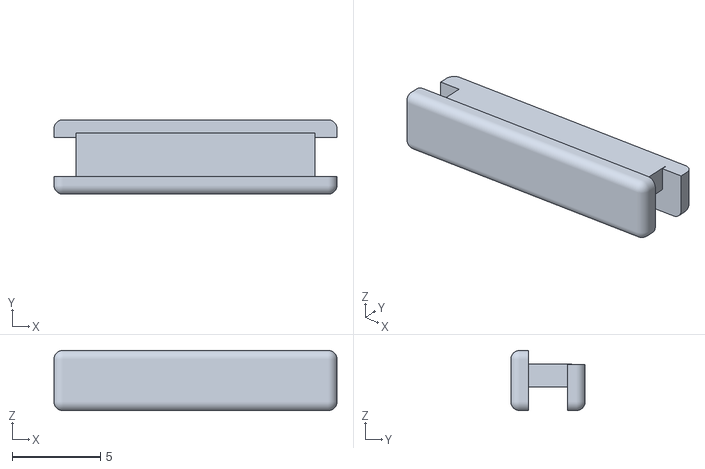
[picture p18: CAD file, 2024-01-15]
enclosure/BusPirate5REV8-v10-plug.stl
16.0 x 4.20 x 3.40

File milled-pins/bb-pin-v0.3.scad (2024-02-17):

include <BOSL2/std.scad>
include <BOSL2/rounding.scad>

//epsilon value
eps=0.01;
center_d=2.2;
center_l=0.8;
pin_d=0.65;
pin_l=7;
dupontp_d=0.65;
dupontp_l=7;
dupontp_square_w=0.6;
  
module bbpin(dupont_pin_square){
    union(){
        translate([0,0,0]) cyl(l=center_l,d=center_d, chamfer1=0.2, chamfang1=30, from_end=true, $fn=100, anchor=CENTER);
        translate([0,0,-center_l/2]) color("Red") cylinder(l=pin_l,d=pin_d, $fn=100, anchor=TOP);
        if(dupont_pin_square==true){
            translate([0,0,center_l/2]) color("Blue") cube(size=[dupontp_square_w,dupontp_square_w,dupontp_l], $fn=100, anchor=BOTTOM);
        }else{
            translate([0,0,center_l/2]) color("Blue") cylinder(l=dupontp_l,d=dupontp_d, $fn=100, anchor=BOTTOM);
        }
    }
}

 translate([0,0,5]){
    //rotate([0,-90,0]) bbpin(true);
}

 translate([0,0,0]){
    rotate([0,-90,0]) bbpin(false);
}

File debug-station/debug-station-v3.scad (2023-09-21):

include <BOSL2/std.scad>
eps=0.01;

bp_xy=65.2;
cradle_gap=1;
cradle_xy=bp_xy+cradle_gap;
cradle_h=7.2;

side_xy=8;

pico_x=52;
pico_y=22;

body_x=(side_xy*2)+cradle_xy;
body_y=(side_xy*3)+pico_y+cradle_xy;
body_h=9.6;

top_h=2;

bp_chamfer_bottom_h=1.6;

screw_d=3.4;
screw_offset_xy=4;
screw_head_h=1.7;
screw_head_d1=screw_d;
screw_head_d2=6.2;
heatset_nut_d=3.9;

echo(body_x=body_x, body_y=body_y);

dish_x=body_x-((side_xy*2)+pico_x+4); //4 is the gap between pico and dish...
dish_y=pico_y;

//quick repetitive cube cuts
module qc(x,y,size_x, size_y){
    translate([x,y,-eps]){
        cube(size=[size_x,size_y,top_h+eps+eps], anchor=BOTTOM+FRONT+LEFT);
    }
}

module top(){

    difference(){

        cube(size=[body_x, body_y, top_h], anchor=BOTTOM);

        translate([-(body_x/2)-eps,-12,-(eps*2)]) cube(size=[11,20,top_h+eps+eps+eps], anchor=BOTTOM+LEFT);

        //pico cut
        translate([-((body_x/2)-side_xy),((body_y/2)-side_xy),(body_h-cradle_h)-eps]){
            difference(){
                union(){
                    //pico
                    cube(size=[pico_x, pico_y, cradle_h+eps+eps], anchor=BOTTOM+BACK+LEFT);
                    //usb cut
                    translate([-side_xy-eps,-5,0])
                    cube(size=[side_xy+eps+eps,12,cradle_h+eps+eps], anchor=BOTTOM+BACK+LEFT);
                }
                //support 1
                translate([2, -6,-eps])
                    cube(size=[6,10,4.2+eps], anchor=BOTTOM+BACK+LEFT);
                
                //support 2
                translate([20, -6,-eps])
                    cube(size=[26,10,4.2+eps], anchor=BOTTOM+BACK+LEFT);            
            }
        } 

        //bus pirate
        bp_eps_h=bp_chamfer_bottom_h+eps+eps;
        translate([0,-(((body_y/2)-side_xy)-(cradle_xy/2)),-eps]){
            union(){
            prismoid(size1=[cradle_xy-(bp_eps_h*2), cradle_xy-(bp_eps_h*2)], size2=[cradle_xy, cradle_xy], h=bp_eps_h, anchor=BOTTOM);
            translate([0, 0, bp_chamfer_bottom_h]) {
                cube(size=[cradle_xy, cradle_xy, top_h+eps+eps], anchor=BOTTOM);
            }
            }
            
        }   

        //dish
        translate([((body_x/2)-side_xy),((body_y/2)-side_xy),-eps]){
            //cube(size=[dish_x, dish_y, top_h+eps+eps], anchor=BOTTOM+BACK+RIGHT);
            prismoid(size1=[dish_x, dish_y], size2=[dish_x+((top_h+eps+eps)*2), dish_y+((top_h+eps+eps)*2)], h=(top_h+eps+eps), anchor=BOTTOM+BACK+RIGHT);

        }

        //screw holes
        for(a=[1:-2:-1]){
            for(b=[1:-2:-1]){
                translate([a*((body_x/2)-screw_offset_xy),b*((body_y/2)-screw_offset_xy),0]){
                    union(){
                        //shaft
                        translate([0,0,-eps]){
                            cylinder(h=(top_h-screw_head_h)+eps, d=screw_d, anchor=BOTTOM, $fn=100);
                        }
                        //countersink
                        translate([0,0,top_h-screw_head_h-eps]){
                            cylinder(h = screw_head_h+eps+eps, d1 = screw_head_d1, d2 = screw_head_d2, anchor=BOTTOM, $fn=100);
                        }
                    }
                }
            }
        }

        #translate([-((body_x/2)-screw_offset_xy),4,0]){
            union(){
                //shaft
                translate([0,0,-eps]){
                    cylinder(h=(top_h-screw_head_h)+eps, d=screw_d, anchor=BOTTOM, $fn=100);
                }
                //countersink
                translate([0,0,top_h-screw_head_h-eps]){
                    cylinder(h = screw_head_h+eps+eps, d1 = screw_head_d1, d2 = screw_head_d2, anchor=BOTTOM, $fn=100);
                }
            }
        }    

        #translate([-((body_x/2)-screw_offset_xy),-28,0]){
            union(){
                //shaft
                translate([0,0,-eps]){
                    cylinder(h=(top_h-screw_head_h)+eps, d=screw_d, anchor=BOTTOM, $fn=100);
                }
                //countersink
                translate([0,0,top_h-screw_head_h-eps]){
                    cylinder(h = screw_head_h+eps+eps, d1 = screw_head_d1, d2 = screw_head_d2, anchor=BOTTOM, $fn=100);
                }
            }
        }               

        translate([-body_x/2,(body_y/2)-31.75,0]){
            //usb
            qc(0-eps,6.75,8+eps+eps,12);
            //usb2 
            qc(8,8.25,7,9);
            //button
            qc(17,6.25,7,5);
            //end pins
            qc(56.46,8.45,3.35,8.6);
            //bottom pins
            qc(14,0,18.8,1.75+eps);
            qc(8,1.75,52,3.54);
            //top pins
            qc(14,20.21+3.54-eps,18.8,1.75);
            qc(8,20.21,52,3.54);
        }
    
        //tool hole
        translate([0,(body_y/2)-screw_offset_xy,-eps]){
            cylinder(h=(top_h)+eps+eps, d=screw_d, anchor=BOTTOM, $fn=100);
        }

    }
}

module bottom(){
        
    difference(){
        cube(size=[body_x, body_y, body_h], anchor=BOTTOM);




        /*bp_eps_h=bp_chamfer_bottom_h+eps+eps;
        translate([0,-(((body_y/2)-side_xy)-(cradle_xy/2)),-eps]){
            union(){
            prismoid(size1=[cradle_xy-(bp_eps_h*2), cradle_xy-(bp_eps_h*2)], size2=[cradle_xy, cradle_xy], h=bp_eps_h, anchor=BOTTOM);
            translate([0, 0, bp_chamfer_bottom_h]) {
                cube(size=[cradle_xy, cradle_xy, top_h+eps+eps], anchor=BOTTOM);
            }
            }
            
        } */  




        //pico cut
        translate([-((body_x/2)-side_xy),((body_y/2)-side_xy),(body_h-cradle_h)-eps]){
            difference(){
                union(){
                    //pico
                    cube(size=[pico_x, pico_y, cradle_h+eps+eps], anchor=BOTTOM+BACK+LEFT);
                    //usb cut
                    translate([-side_xy-eps,-5,0]){
                        cube(size=[side_xy+eps+eps,12,cradle_h+eps+eps], anchor=BOTTOM+BACK+LEFT);
                    }
                    //wire bend cut
                    translate([6, 2.5, 0]){
                        cube(size=[18.8, 2.5+eps, cradle_h+eps+eps], anchor=BOTTOM+BACK+LEFT);
                    }

                }
                //support 1
                translate([2, -6,-eps])
                    cube(size=[6,10,4.2+eps], anchor=BOTTOM+BACK+LEFT);
                
                //support 2
                translate([20, -6,-eps])
                    cube(size=[26,10,4.2+eps], anchor=BOTTOM+BACK+LEFT);            
            }
        } 

        //dish
        translate([((body_x/2)-side_xy),((body_y/2)-side_xy),(body_h-cradle_h)-eps]){
            cube(size=[dish_x, dish_y, cradle_h+eps+eps], anchor=BOTTOM+BACK+RIGHT);
        }

        //work area polygon
        shape = [[-5,-10], [-5, 20], [0,20], [0,64.2+eps], [12,64.2+eps], [12,64.2-18],[12+34.2,64.2-18], [12+34.2,64.2-18-16.1], [12+34.2+18+eps,64.2-18-16.1],
                [12+34.2+18+eps,64.2-18-16.1-14], [12+34.2,64.2-18-16.1-14], [12+34.2,64.2-18-16.1-14-16.1-5], [15,-5],[15, -10], [0,-10]]; 
        translate([-((body_x/2)-side_xy-10),-((body_y/2)-18),(body_h-cradle_h)-eps]){
            linear_extrude(height=cradle_h+eps+eps){
                polygon(shape);
            }
        }
        
        //screw holes
        screw_offset_xy=4;
        heatset_nut_d=3.9;
        for(a=[1:-2:-1]){
            for(b=[1:-2:-1]){
                translate([a*((body_x/2)-screw_offset_xy),b*((body_y/2)-screw_offset_xy),-eps]){
                    cylinder(h=body_h+eps+eps, d=heatset_nut_d, anchor=BOTTOM, $fn=100);
                }
            }
        }  

        translate([-((body_x/2)-screw_offset_xy),4,-eps]){
            cylinder(h=body_h+eps+eps, d=heatset_nut_d, anchor=BOTTOM, $fn=100);
        }
        translate([-((body_x/2)-screw_offset_xy),-28,-eps]){
            cylinder(h=body_h+eps+eps, d=heatset_nut_d, anchor=BOTTOM, $fn=100);
        }        


        //guide pins
        /*guidepin_d=2;
        translate([((body_x/2)-side_xy-7.1),-((body_y/2)-side_xy-7.1),-eps]){
            cylinder(h=body_h+eps+eps, d=guidepin_d, anchor=BOTTOM, $fn=100);
        }
        translate([-((body_x/2)-side_xy-7.1),-((body_y/2)-side_xy-7.1),-eps]){
            cylinder(h=body_h+eps+eps, d=guidepin_d, anchor=BOTTOM, $fn=100);
        }   
        translate([((body_x/2)-side_xy-7.1),-((body_y/2)-side_xy-7.1-52),-eps]){
            cylinder(h=body_h+eps+eps, d=guidepin_d, anchor=BOTTOM, $fn=100);
        }
        translate([-((body_x/2)-side_xy-7.1),-((body_y/2)-side_xy-7.1-52),-eps]){
            cylinder(h=body_h+eps+eps, d=guidepin_d, anchor=BOTTOM, $fn=100);
        }   */    

        //tool cup
        translate([0,(body_y/2)-screw_offset_xy,1.4]){
            cylinder(h=(body_h)+eps+eps, d=screw_d, anchor=BOTTOM, $fn=100);
        } 


    }



}

translate([0,0,body_h+10]){
    top();
}
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

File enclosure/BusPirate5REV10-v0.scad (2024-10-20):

include <BOSL2/std.scad>
include <BOSL2/rounding.scad>
include <BOSL2/screws.scad>


vf=360;
//version number
version="10"; //version number
version_h=1; //depth of version number pocket

//epsilon value
eps=0.01;

//CASE BODY
//case stackup
echo("----------CASE----------");
face_h = 1.4;
lcd_h = 2.2;
pcb_h = 1.6;
standoff_h = 3.4;
floor_h = 1.4; //was 1.6... //was 2.4

top_h = face_h+lcd_h+pcb_h;
bottom_h = pcb_h+standoff_h+floor_h;
case_h=face_h+lcd_h+pcb_h+standoff_h+floor_h;
echo(top_h=top_h, bottom_h=bottom_h, case_h=case_h);

standoff_cut = 8.4; //length of the standoff arm excluding the rounded bit
standoff_d = 3; //diameter of standoff rounded bit

//mating walls
wall_inner_xy = 0.8; //inner wall thickness EACH side
wall_gap_xy=0.6; //was 0.6, but changed to one extruder width //gap between walls EACH side
wall_outer_xy=0.8; //outer wall thickness
wall_width=wall_inner_xy+wall_gap_xy+wall_outer_xy;
echo(wall_width=wall_width);

//pcb dimentions and tolerance
pcb_xy = 60;
pcb_tolerance_xy = 0.4; //spacing on EACH side
pcb_cavity_xy=(pcb_tolerance_xy*2)+pcb_xy; //bottom half PCB cavity
top_cavity_xy=pcb_cavity_xy+(wall_gap_xy*2)+(wall_inner_xy*2); //pcb+innerwall cavity in top
echo(pcb_cavity_xy=pcb_cavity_xy, top_cavity_xy=top_cavity_xy);

//full outer case dimentions
body_xy=(wall_outer_xy*2)+(wall_gap_xy*2)+(wall_inner_xy*2)+pcb_cavity_xy;
echo(body_xy=body_xy);

//edge chamfers, top and bottom
chamfer_top_h=2.4;
chamfer_bottom_h=1.4;

//TOP CASE FEATURES
//LCD body
lcd_x=34.6 + 2; //36.8;
lcd_y=47.8 + 2; //52.2;
//LCD viewable area
lcd_va_x=33.6 - 1; //32.4; 
lcd_va_y=43.6 - 1; //42.8;
lcd_va_base_h = 0.4; //two layers of material without chamfer on top of lcd
lcd_va_chamfer_h = face_h - lcd_va_base_h; //the chamfered "view port"
lcd_va_offset_y = 1.8 + (1/2); //from top of LCD body to top of viewable area

//10P header
head_10p_x = 11.6;
head_10p_y = 29.00;
head_10p_offset=4;

echo("------PROGRAMMING HEADER-------");
//cut in bottom of top half to accomidate the ends/solder of the programming header on the bottom layer
head_prog_x = 2.54+.4;
head_prog_y=(2.54*3)+0.55;
head_prog_bottom_h=lcd_h;  //bottom of header (top of PCB, top of case)
head_prog_top_h=floor_h;
head_prog_offset_x=10.75;
head_prog_offset_y=9.6;//9.6
head_prog_connector_max_h=floor_h+standoff_h;
echo(head_prog_connector_max_h=head_prog_connector_max_h);

//from datasheet for milled, low profile pin header
head_prog_connector_total_h=7.43;
head_prog_connector_pin_h=2.7;
head_prog_connector_body_h= head_prog_connector_total_h-head_prog_connector_pin_h;
head_prog_connector_clearance_h=head_prog_connector_max_h-head_prog_connector_body_h;
echo(head_prog_connector_body_h=head_prog_connector_body_h, head_prog_connector_clearance_h=head_prog_connector_clearance_h );

//mounting screws
echo("----------SCREWS----------");
screw_d=3.4;
screw_offset_xy=4;
screw_head_h=1.7;
screw_head_d1=screw_d;
screw_head_d2=6.2;
heatset_nut_d=4.4; //4.3/3.9;
heatset_nut_max_h=floor_h+standoff_h;
screw_distance_to_nut_h=top_h;
echo(screw_distance_to_nut_h=screw_distance_to_nut_h);

screw_h=8;
screw_depth_nut_h=screw_h-screw_distance_to_nut_h;
echo(screw_h=screw_h, screw_depth_nut_h=screw_depth_nut_h);

echo("----------NUTS----------");
heatset_nut_h=3;
heatset_nut_bottom_clearance_h=.8; //how much deeper should the hole be than the nut? effects minimum floor thickness
heatset_nut_unused_h=heatset_nut_h-screw_depth_nut_h;
echo(heatset_nut_max_h=heatset_nut_max_h);
echo(heatset_nut_h=heatset_nut_h,heatset_nut_unused_h=heatset_nut_unused_h);

//push buttons (with countersink)  
//assumes center button is at Y=0 (centered)  
echo("--------USER BUTTONS--------");
button_distance_to_top=face_h+lcd_h;
echo(button_distance_to_top=button_distance_to_top);

//button body cutout
butt_body_x=9.2;
butt_body_y=28; 
butt_body_h=1.5;
butt_body_cavity_h=0.8; 
echo(butt_body_cavity_h=butt_body_cavity_h);

//This is stack up for short buttons with button caps
butt_cap_h=4;
butt_cap_d=5+.4;
butt_cap_rim_h=1; 
butt_cap_rim_d=6.8+.4;
butt_cap_center_extra_space_d=0.2; //for some reason our printer makes the center hole slightly too tight, so we add some space
//This is the 1mm cap rim + 0.7 of the button body height +0.1 (even layer height)
//(to keep cap rim being stuck under the case)
butt_cap_rim_cavity_h=butt_cap_rim_h+(butt_body_h-butt_body_cavity_h)+.1;
echo(butt_cap_rim_cavity_h=butt_cap_rim_cavity_h);
butt_cap_shaft_h=button_distance_to_top-butt_body_cavity_h-butt_cap_rim_cavity_h;
echo(butt_cap_shaft_h=butt_cap_shaft_h);

//This is stack up with long shaft button
//counter sink 
butt_sink_h=1.7; 
butt_sink_d1=3.2;
butt_sink_d2=6.2;
//button hole
butt_offset_x=7.2; //edge of pcb to center of button
butt_spread_y=10; //center of center button to center of top and bottom buttons
butt_hole_d=3.2;
butt_hole_h=top_h-(pcb_h+butt_body_h+butt_sink_h);





//BOTTOM CASE FEATURES
//retaining lip for the case
bottom_lip_width=wall_gap_xy+wall_outer_xy;
bottom_lip_h=pcb_h;

//sd card hole
sd_x=14;
sd_y=wall_width;
sd_offset_x=22;
sd_h=3.4;

//9p aux la header hole
head_aux_x=wall_width;
head_aux_y=12.8;
head_aux_h=4.8;

//USB C hole (currently blown out)
usb_x=wall_width;
usb_y=14; //blow out
usb_h=5.6; //blow out, 3.2;
print_layer_h=0.2;
usb_cut_layers=2;

//bootloader button hole
bootload_x=3;
bootload_y=4;
bootload_h=floor_h;
bootload_offset_x=27; //from top of flipped PCB
bootload_offset_y=14;    //from right of flipped PCB
bootload_spin=45;
echo("----------END----------");

//
// CASE TOP MODULES
//
module body_top(){
    //case body
    diff(){
        cube(size=[body_xy, body_xy,top_h], anchor=BOTTOM){
            //top chamfer
            chamfer_list=[RIGHT, LEFT, BACK, FRONT];
            for( i = chamfer_list){
            edge_mask(TOP+i)
                chamfer_edge_mask(l=body_xy, chamfer=chamfer_top_h);
            }                        
        }    
    }
}

module cavity_top(){    
    //PCB area in top
    translate([0,0,-eps]){
        cube(size=[top_cavity_xy, top_cavity_xy, pcb_h+eps], anchor=BOTTOM);
    }
}

module lcd(){
    //LCD
    lcd_va_chamfer_eps_h=lcd_va_chamfer_h+eps+eps;
    translate([0,0,pcb_h]){
        union(){
            //body
            translate([0,0,-eps]){
                cube(size=[lcd_x, lcd_y, lcd_h+eps], anchor=BOTTOM);
            }
            //view area base (0.4=2 layers)
             translate([0, lcd_va_offset_y, lcd_h-eps]){
                 cube(size=[lcd_va_x, lcd_va_y, lcd_va_base_h+eps], anchor=BOTTOM);
            }           
            //view area chamfer, 45 degrees
            translate([0, lcd_va_offset_y, (lcd_h+lcd_va_base_h)-eps]){
                prismoid(size1=[lcd_va_x, lcd_va_y], size2=[lcd_va_x+(lcd_va_chamfer_eps_h*2), lcd_va_y+(lcd_va_chamfer_eps_h*2)], h=lcd_va_chamfer_eps_h);
            }
        }
    }
}

module screws(){
    //screw holes
    for(a=[1:-2:-1]){
        for(b=[1:-2:-1]){
             translate([a*((pcb_xy/2)-screw_offset_xy),b*((pcb_xy/2)-screw_offset_xy),0]){
                union(){
                    //shaft
                    translate([0,0,-eps]){
                        cylinder(h=(top_h-screw_head_h)+eps, d=screw_d, anchor=BOTTOM, $fn=100);
                    }
                    //countersink
                    translate([0,0,top_h-screw_head_h-eps]){
                        cylinder(h = screw_head_h+eps+eps, d1 = screw_head_d1, d2 = screw_head_d2, anchor=BOTTOM, $fn=100);
                    }
                }
            }
        }
    }
}

module buttons(){
     //buttons
    translate([-((pcb_xy/2)-butt_offset_x), 0,pcb_h]){
        union(){
            //button body
            translate([0,0,-eps]){
                cube(size=[butt_body_x, butt_body_y, butt_body_cavity_h+eps], anchor=BOTTOM);
            }
            //button holes
            if(0){
            //for(a=[-1:1:1]){
                translate([ 0, butt_spread_y*a, butt_body_cavity_h]){
                    union(){
                        translate([0,0,-eps]){
                            cylinder(h=butt_hole_h+eps , d=butt_hole_d, anchor=BOTTOM, $fn=100);  
                        }
                        translate([0,0,butt_hole_h-eps]){
                            cylinder(h = butt_sink_h+eps+eps, d1 = butt_sink_d1, d2 = butt_sink_d2, anchor=BOTTOM, $fn=100);
                        }                         
                    }
                }
            //}
            }
        }
    }
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

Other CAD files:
milled-pins/tp-pin-rev0.scad
development/adapter-kaybee-plank-1REV0/footprints/5145300-3.step
development/adapter-kaybee-plank-1REV0/footprints/HRO_TYPE-C-31-M-12.step
development/adapter-kaybee-plank-1REV1/footprints/5145300-3.step
development/adapter-kaybee-plank-1REV1/footprints/HRO_TYPE-C-31-M-12.step
development/adapter-ram-ddr5-1REV0/footprints/5145300-3.step
development/adapter-ram-ddr5-1REV0/footprints/DDR504111002KQ.STEP
development/adapter-ram-ddr5-1REV0/footprints/HRO_TYPE-C-31-M-12.step
development/adapter-ram-ddr5-1REV1/footprints/5145300-3.step
development/adapter-ram-ddr5-1REV1/footprints/DDR504111002KQ.STEP
development/adapter-ram-ddr5-1REV1/footprints/HRO_TYPE-C-31-M-12.step
development/adapter-sim-iccard-1REV4/footprints/5145300-3.step
development/adapter-stemma-qwiic-grove-gravity-bog-1REV0/footprints/3D_PCB1_2025-05-14(1).STEP
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

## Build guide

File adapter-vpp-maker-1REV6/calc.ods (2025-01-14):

 | Output | Zener | Feedback | Output | Zener
 | 16V | 18V (16.8...19.1) | 5.6/2 | 4.211 | 4V7 (4.4...5)
 | 5.5V |  |  | 1.447
 | 7V |  |  | 1.842
 | 16V |  | 6.2/2.2 | 4.19 |  | 16 | 9.1 | 3.3 | 4.25806451612903 | 0.266129032258065 | 3.75757575757576 | 2.64258064516129
 |  |  | 9.1/3.3 | 4.258 |  | 15 | 9.1 | 3.3 | 3.99193548387097 | 0.266129032258065 | 3.75757575757576 | 2.47741935483871
 |  |  | 2.75757575757576 | 4.25806451612903 |  | 14 | 9.1 | 3.3 | 3.7258064516129 | 0.266129032258065 | 3.75757575757576 | 2.31225806451613
 |  |  |  |  |  | 13 | 9.1 | 3.3 | 3.45967741935484 | 0.266129032258065 | 3.75757575757576 | 2.14709677419355
 |  |  |  |  |  | 12 | 9.1 | 3.3 | 3.19354838709677 | 0.266129032258064 | 3.75757575757576 | 1.98193548387097
 |  |  |  |  |  | 11 | 9.1 | 3.3 | 2.92741935483871 | 0.266129032258065 | 3.75757575757576 | 1.81677419354839
 |  |  |  |  |  | 10 | 9.1 | 3.3 | 2.66129032258065 | 0.266129032258065 | 3.75757575757576 | 1.65161290322581
 |  |  |  |  |  | 9 | 9.1 | 3.3 | 2.39516129032258 | 0.266129032258065 | 3.75757575757576 | 1.48645161290323
 |  |  |  |  |  | 8 | 9.1 | 3.3 | 2.12903225806452 | 0.266129032258065 | 3.75757575757576 | 1.32129032258065
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

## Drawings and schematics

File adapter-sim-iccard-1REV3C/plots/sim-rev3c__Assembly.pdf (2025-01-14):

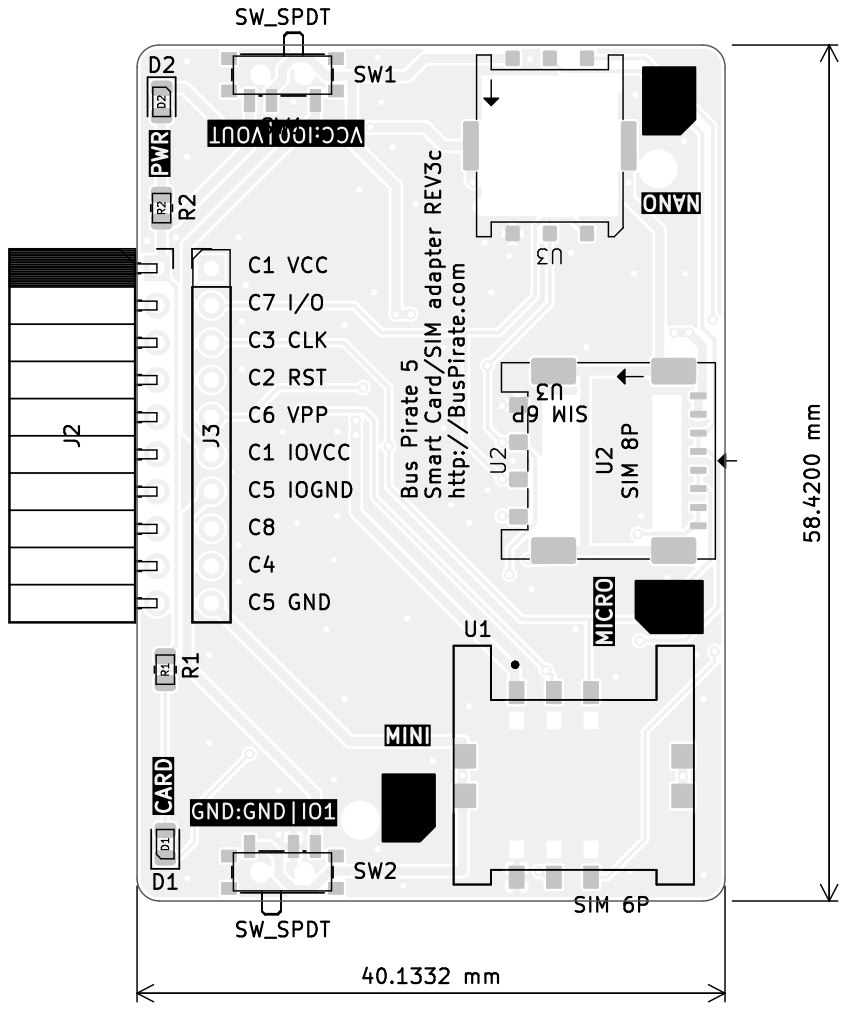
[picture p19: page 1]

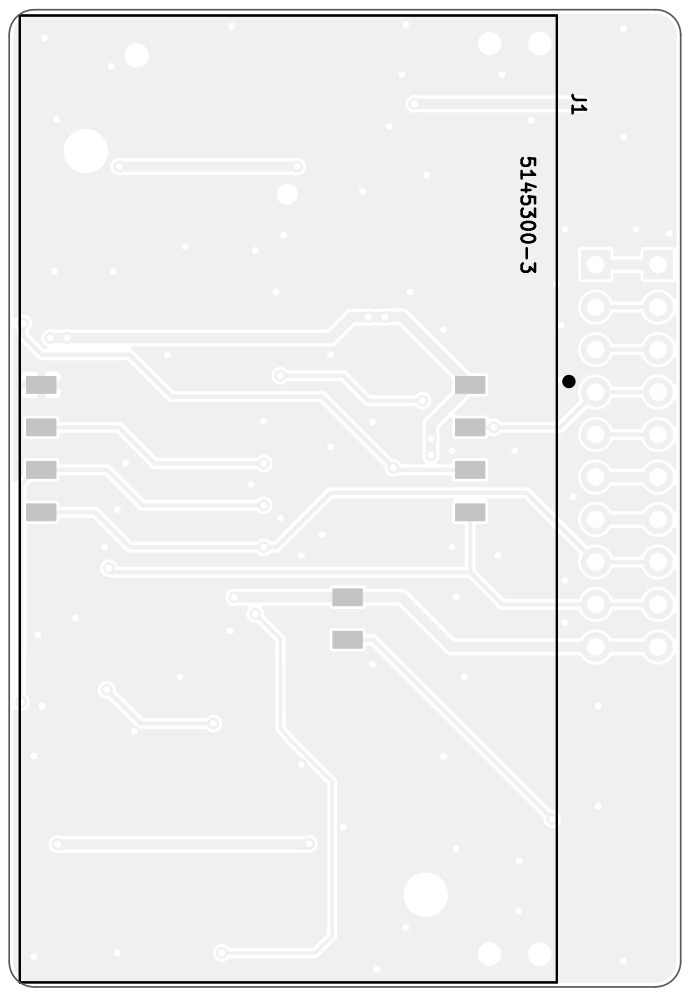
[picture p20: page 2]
D Date: KiCad; kicad; 7.0.7 Size: A4; Rev:

Id: 1/1 Title: File: sim-rev3c.kicad_pcb Sheet: 5145300⁻3

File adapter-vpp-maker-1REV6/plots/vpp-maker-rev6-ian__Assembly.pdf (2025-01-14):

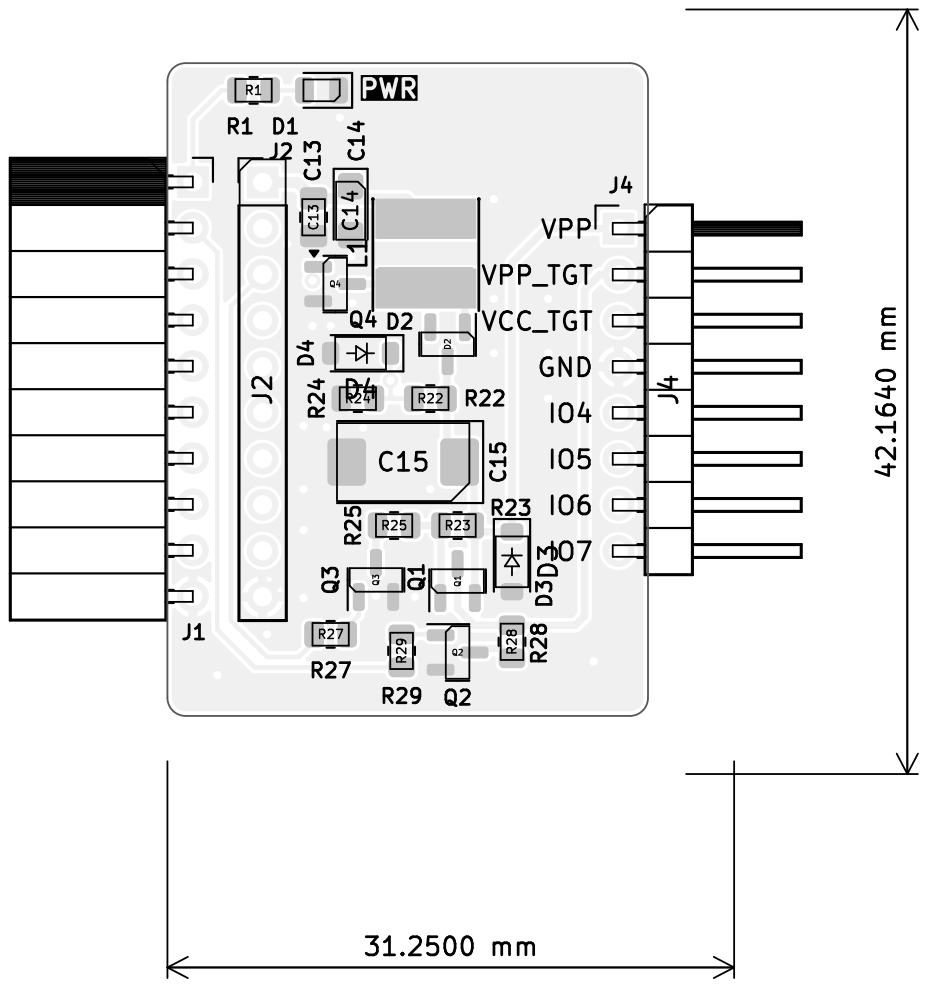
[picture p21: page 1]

Id: 1/1 Title: File: vpp-maker-rev6-ian.kicad_pcb Sheet:

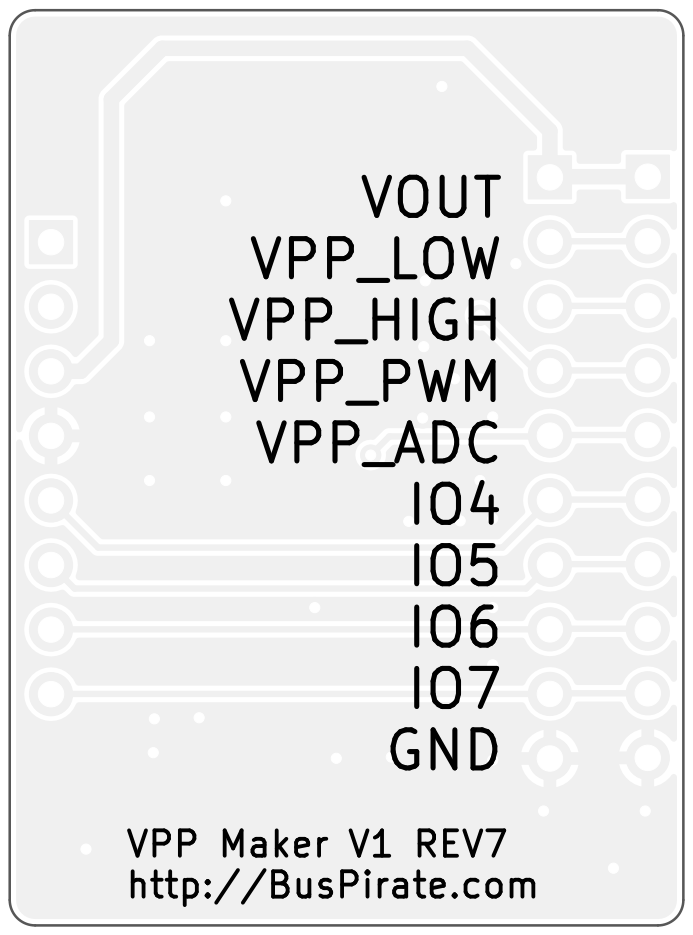
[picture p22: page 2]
VPP Maker V1 REV7; VPP_HIGH VPP_PWM VPP_ADC IO4 IO5 IO6 IO7 GND; D Date: KiCad; E.D.A. 8.0.3 Size: A4; Rev:

http://BusPirate.com VOUT VPP_LOW

Id: 1/1 Title: File: vpp-maker-rev6-ian.kicad_pcb Sheet:

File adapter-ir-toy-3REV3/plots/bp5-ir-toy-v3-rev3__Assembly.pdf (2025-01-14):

J3 U5 | D1 R11 | C2 C1 | U² D4 R6 | C5 D¹⁰ | Q³ D⁹ | U³ C⁶ | D3 R7R² C8 | R⁵ R13 | U¹ U⁴ R⁹ C3 C7 | R4 R³ R¹⁰ | R12R⁸ | R1 1 | 2 | 3 | 4 | 5 | 6 1 | 2 | 3 | 4 | 5 | 6 ABCD | ABCD Date: KiCad | E.D.A. 8.0.3 Size: A4 | Rev:

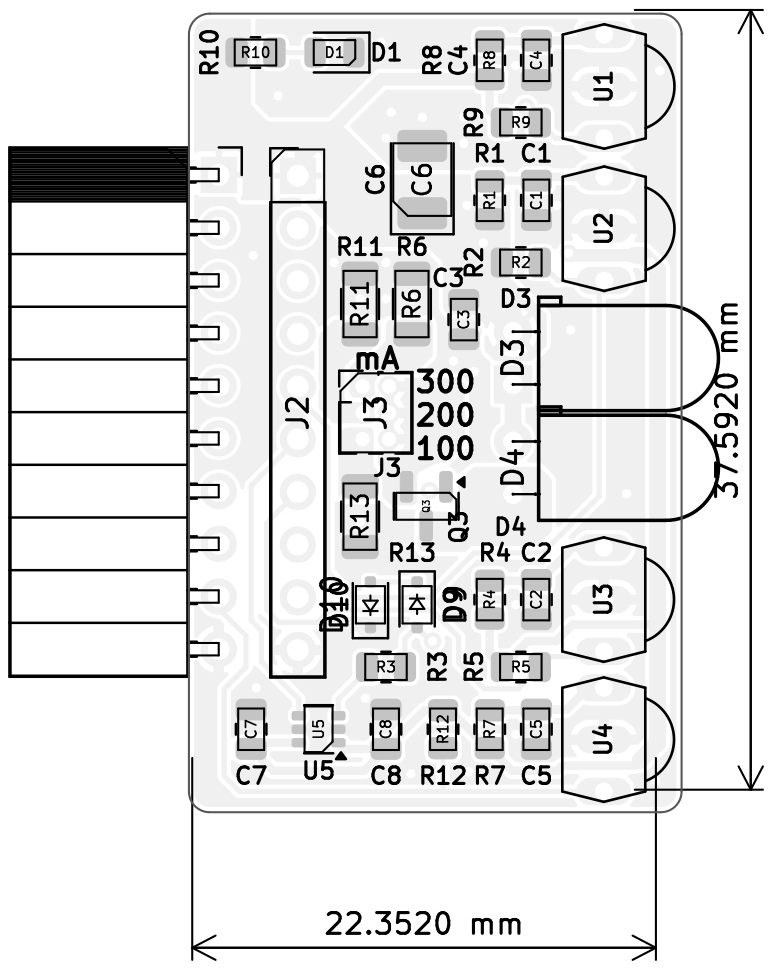
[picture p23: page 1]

Id: 1/1 Title: File: bp5-ir-toy-v3-rev3.kicad_pcb Sheet:

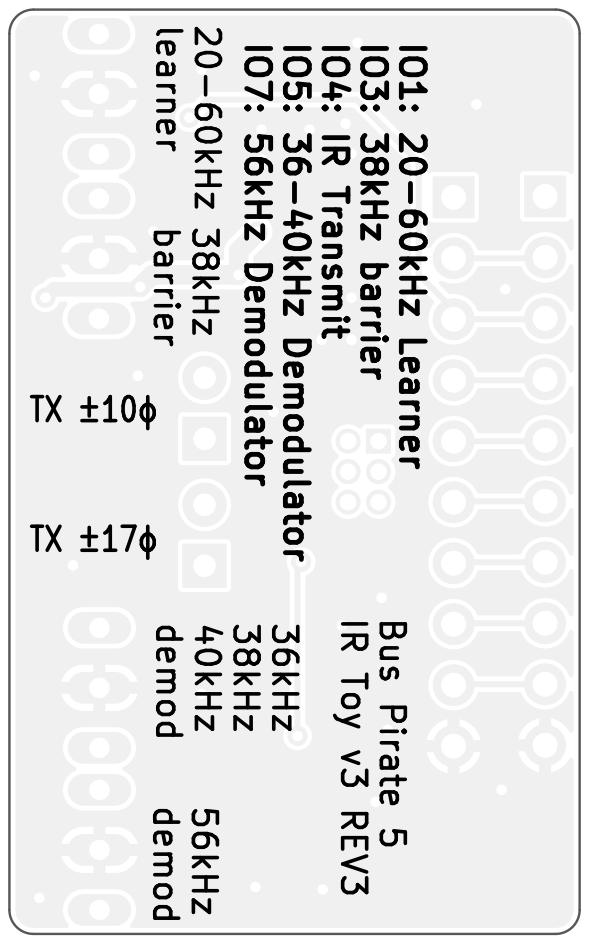
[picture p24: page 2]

demod 56kHz barrier 38kHz Bus Pirate 5 IR Toy v3 REV3 learner 20-60kHz TX þÿ±17Õ IO1: 20-60kHz Learner IO3: 38kHz barrier IO4: IR Transmit IO5: 36-40kHz Demodulator IO7: 56kHz Demodulator TX þÿ±10Õ demod 40kHz 38kHz 36kHz 1 2 3 4 5 6 1 2 3 4 5 6 ABCD ABCD Date: KiCad E.D.A. 8.0.3 Size: A4 Rev:

Id: 1/1 Title: File: bp5-ir-toy-v3-rev3.kicad_pcb Sheet:

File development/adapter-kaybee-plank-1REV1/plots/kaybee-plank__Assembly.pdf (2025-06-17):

A

A

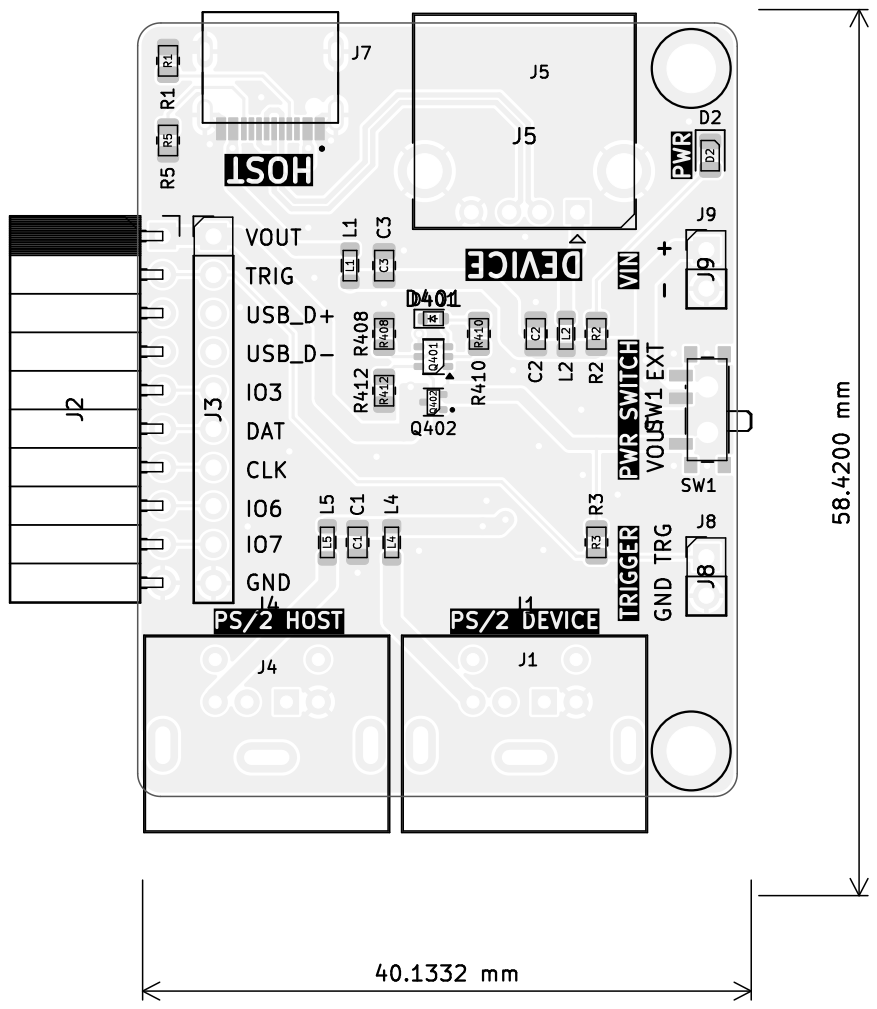
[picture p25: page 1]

Id: /1 Title: File: kaybee-plank.kicad_pcb Sheet: Black-And-White-TOP

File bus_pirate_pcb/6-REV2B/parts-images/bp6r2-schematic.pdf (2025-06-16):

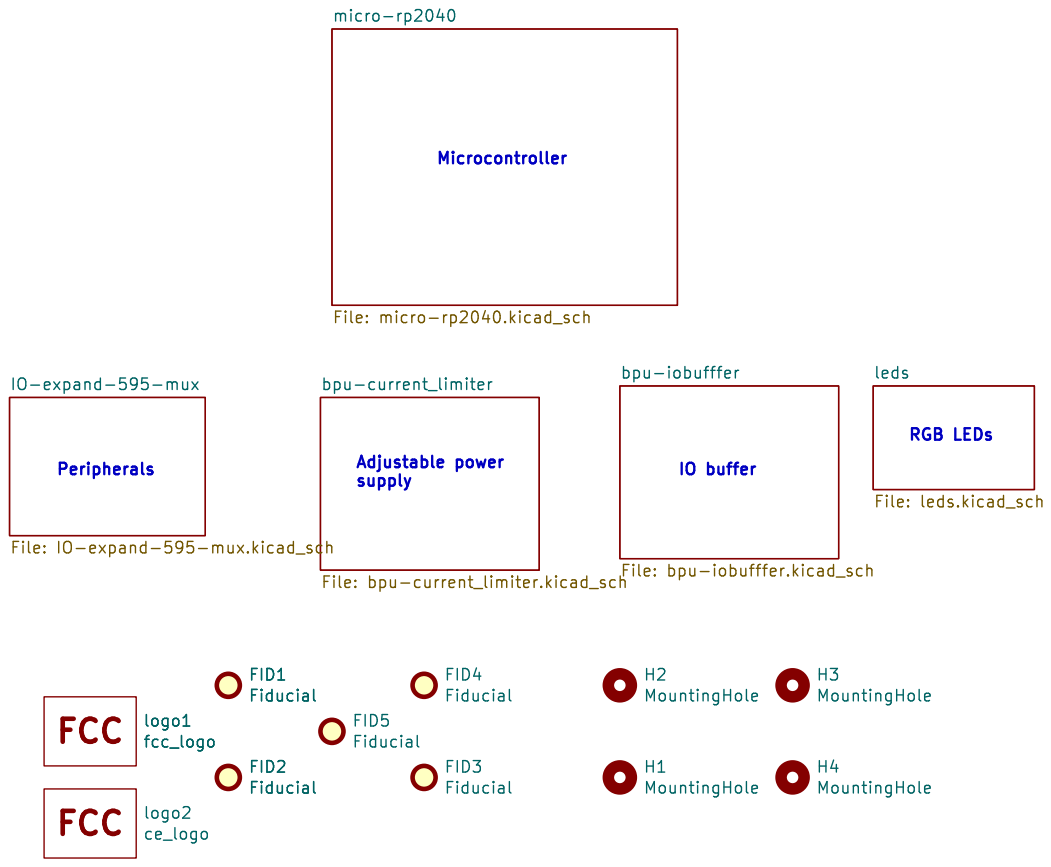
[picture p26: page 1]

IO-expand-595-mux File: IO-expand-595-mux.kicad_sch

Id: 1/6 Title: File: 6-REV2b.kicad_sch Sheet: /

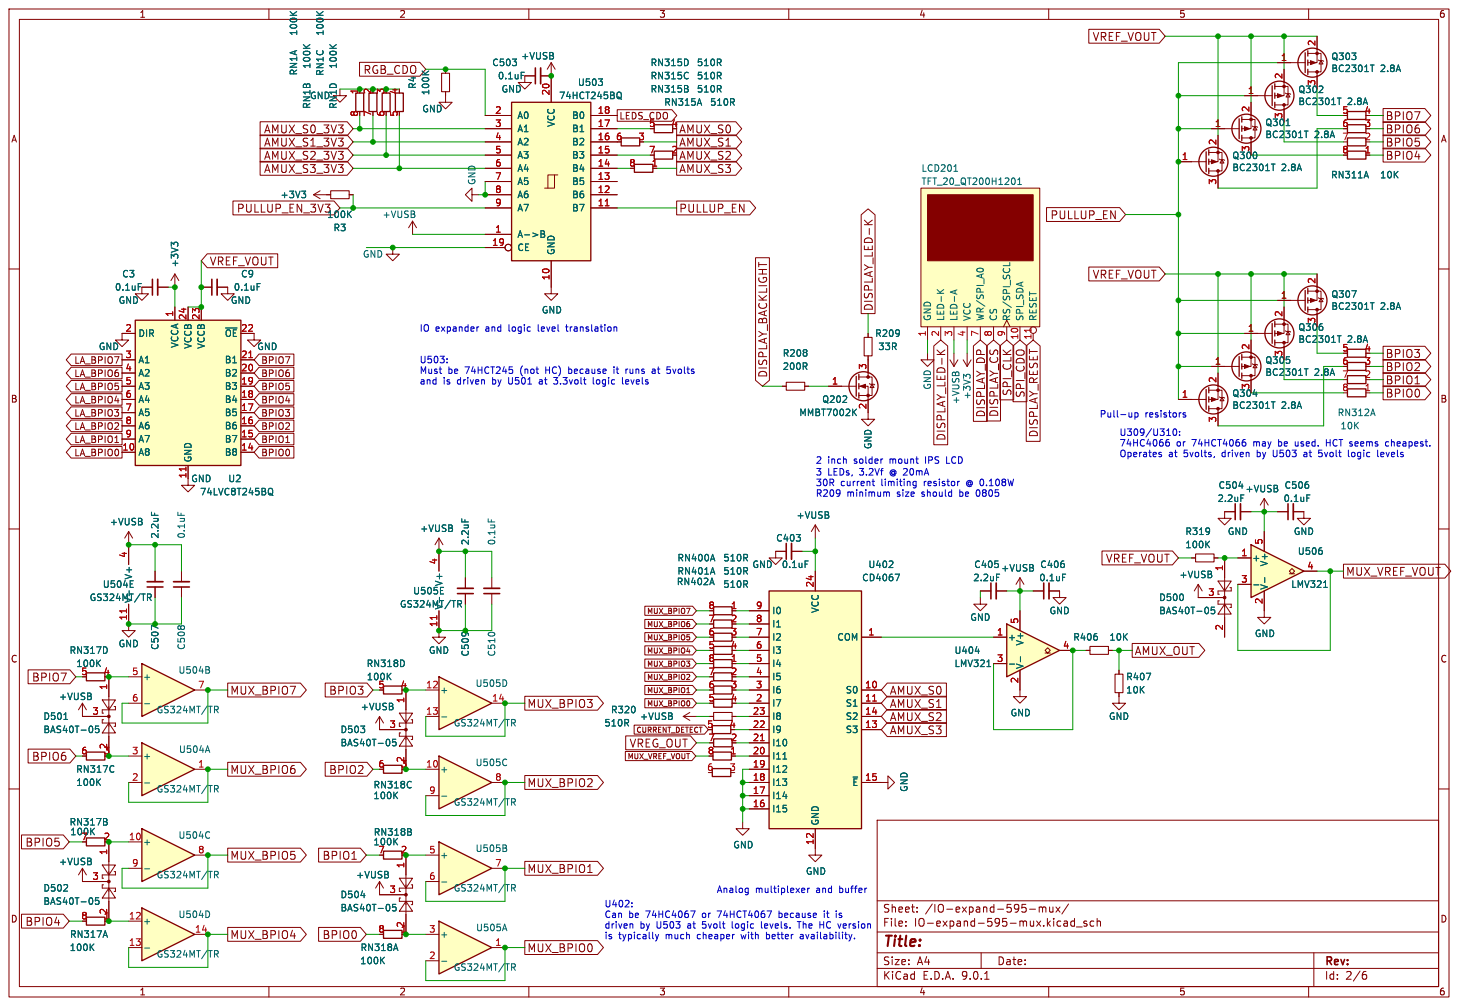
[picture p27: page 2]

2 inch solder mount IPS LCD
3 LEDs, 3.2Vf @ 20mA

GND GND

Id: 2/6 Title: File: IO-expand-595-mux.kicad_sch Sheet: /IO-expand-595-mux/

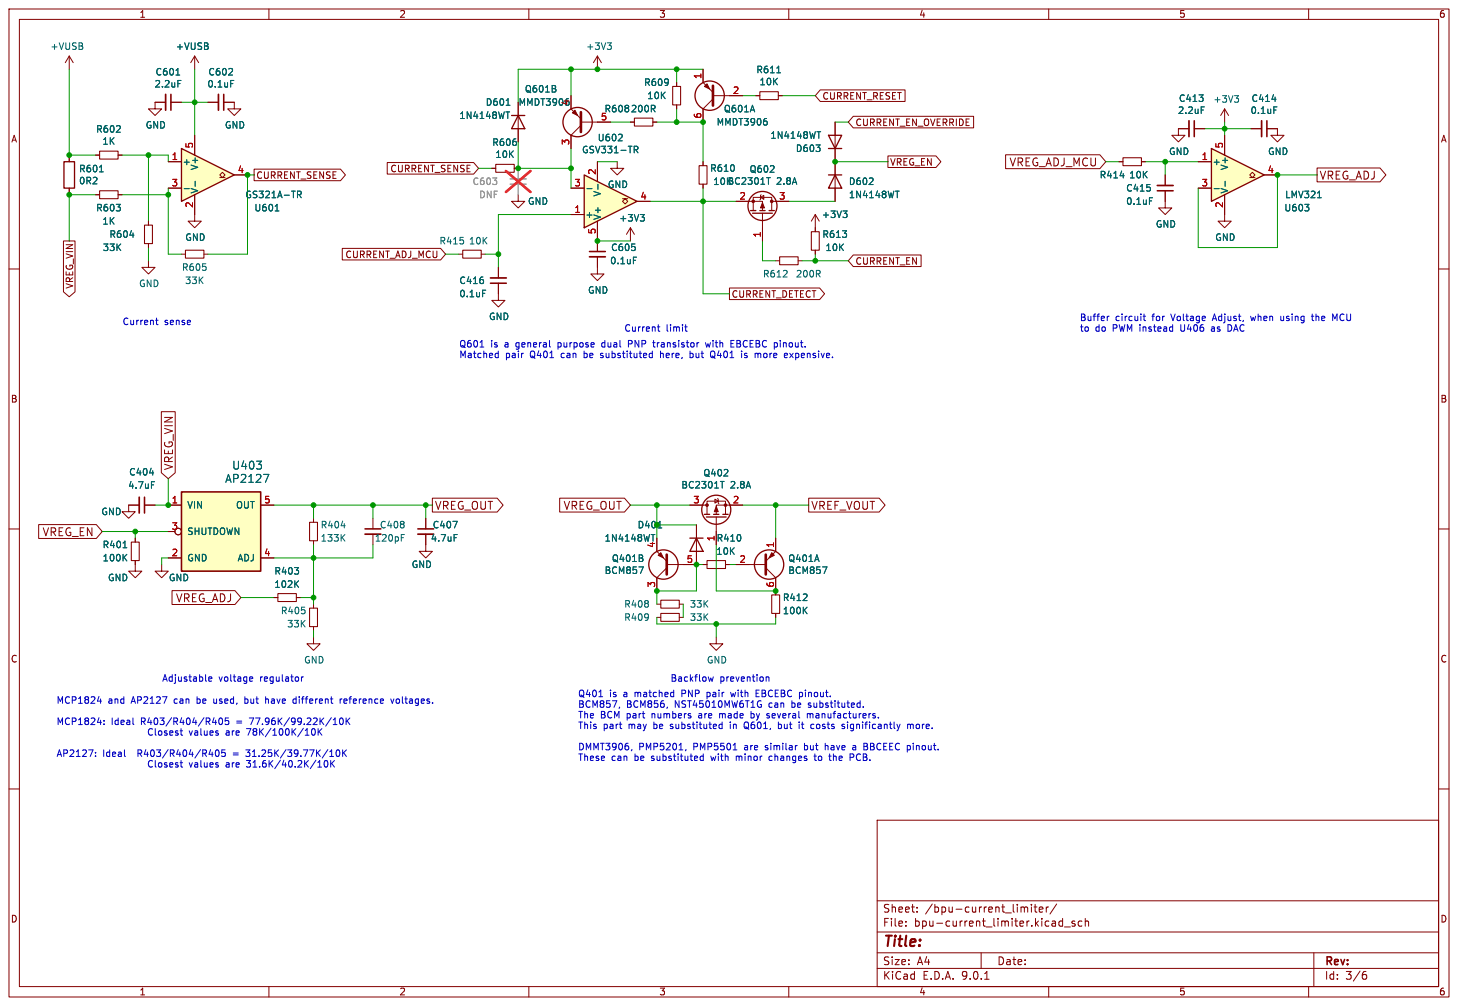
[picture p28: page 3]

3 4 Q601B MMDT3906 +3V3 GND VIN 1 SHUTDOWN 3 GND 2 OUT 5 ADJ 4 U403 AP2127 R403

to do PWM instead U406 as DAC

BCM857 R410
Id: 3/6 Title: File: bpu-current_limiter.kicad_sch Sheet: /bpu-current_limiter/ 2

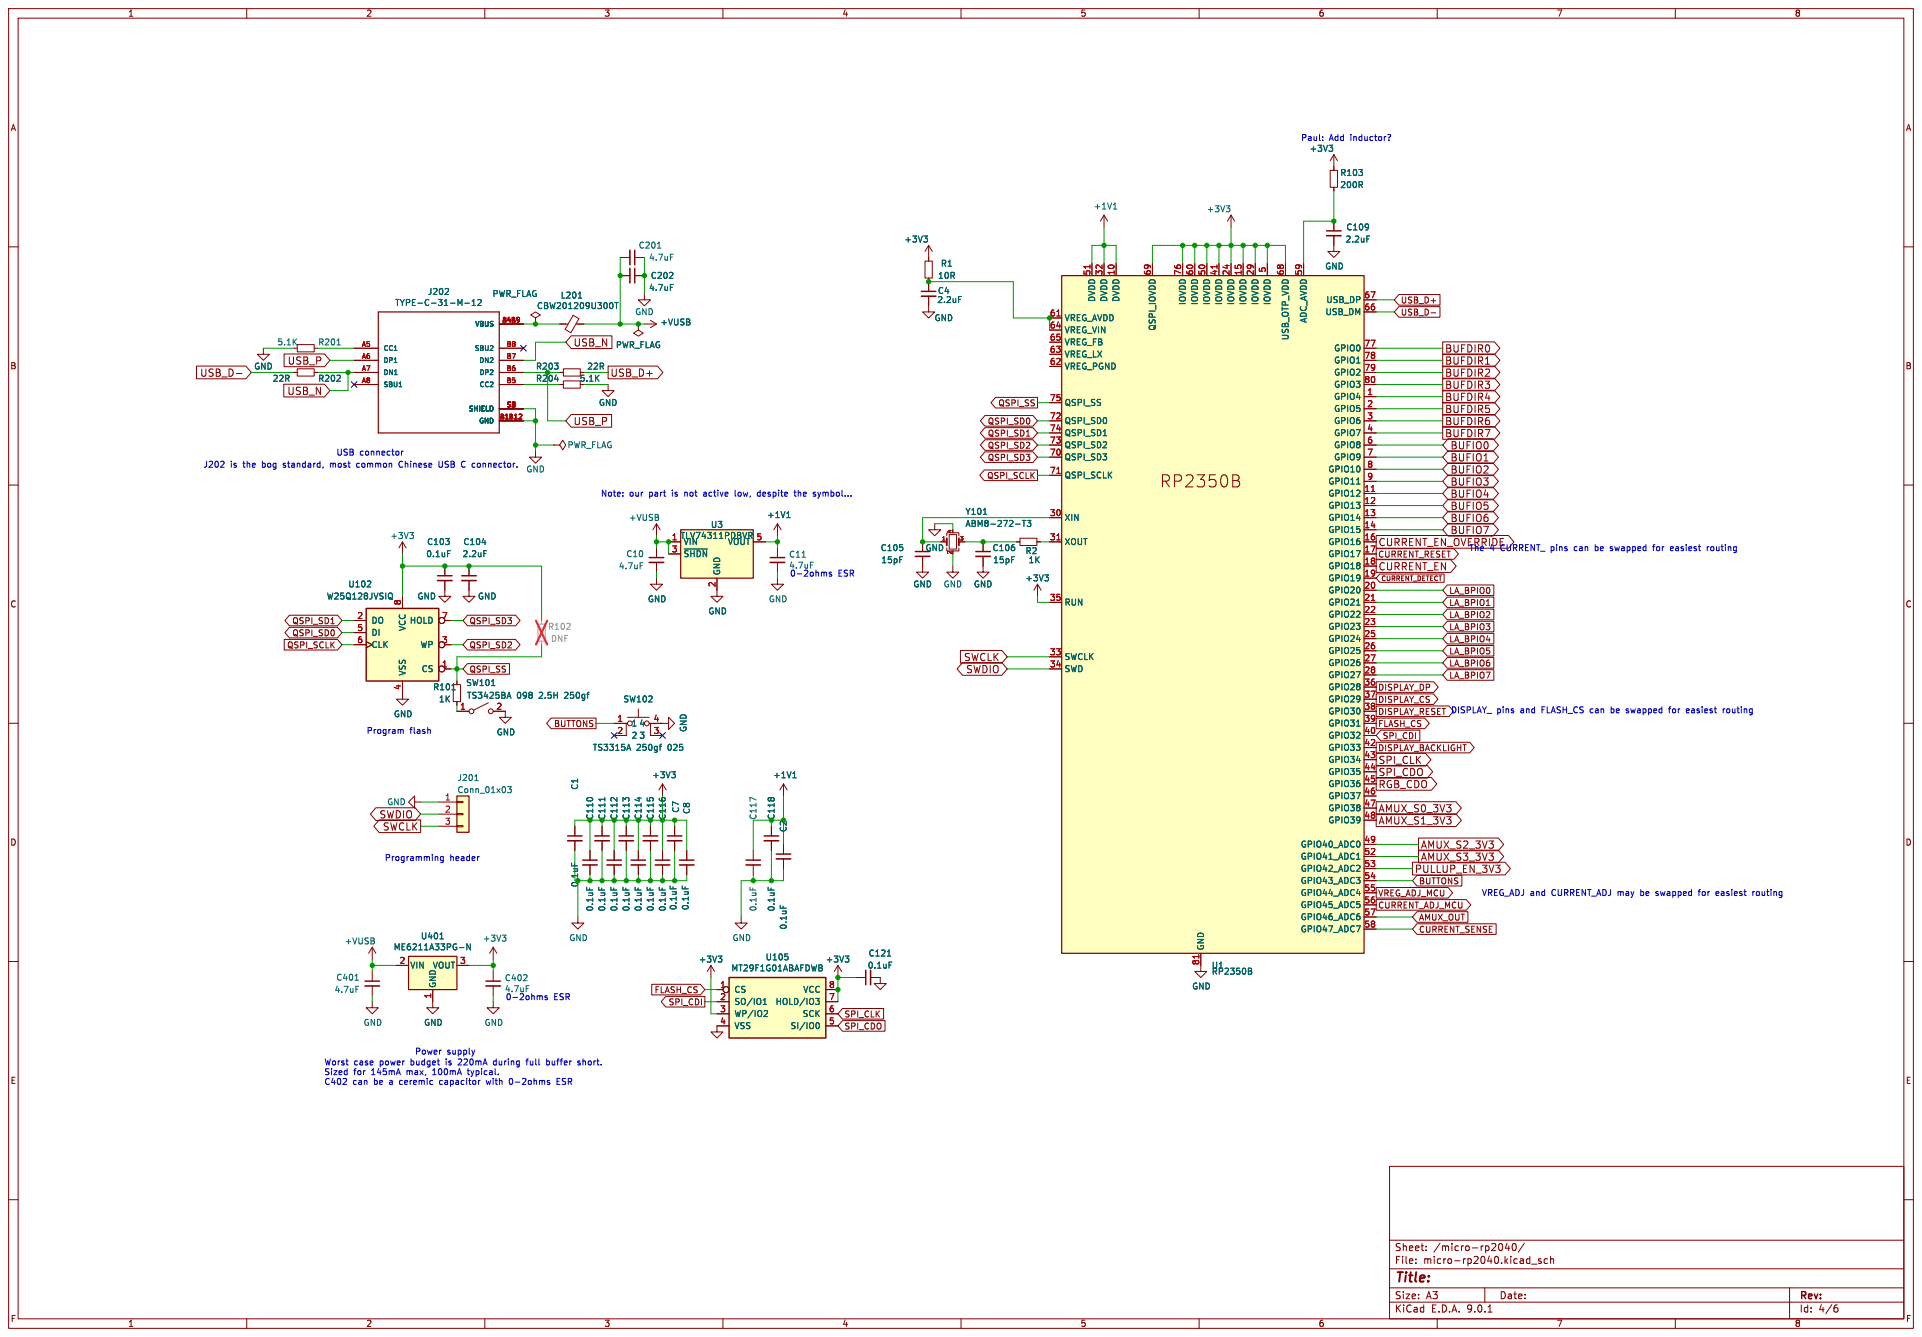
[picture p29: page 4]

Id: 4/6 Title: File: micro-rp2040.kicad_sch Sheet: /micro-rp2040/

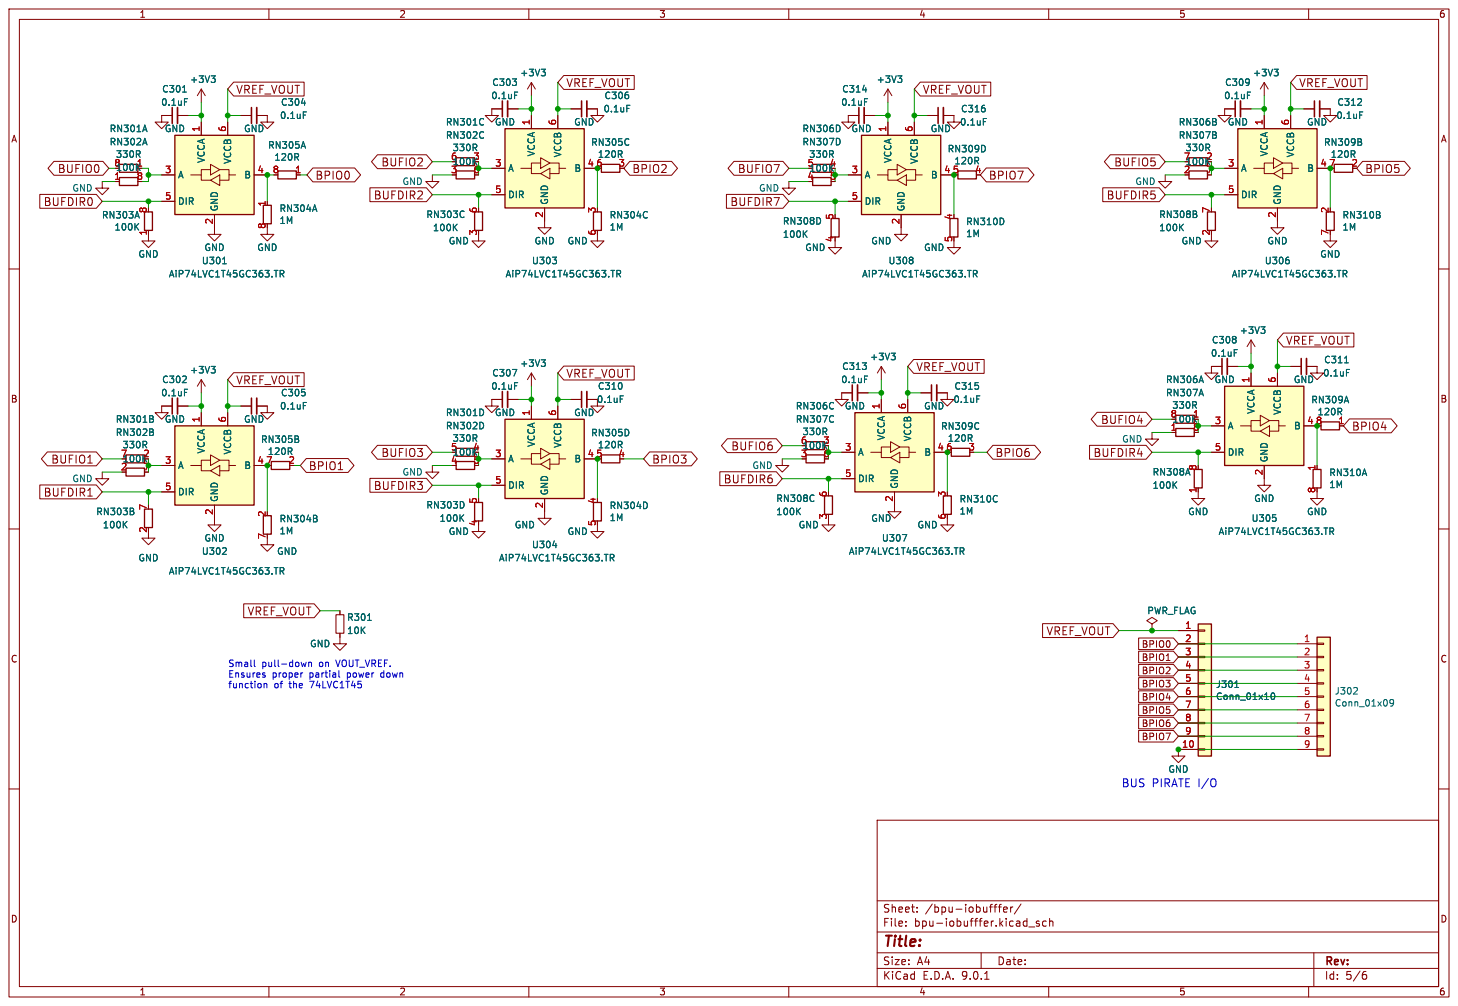
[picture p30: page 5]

Id: 5/6 Title: File: bpu-iobufffer.kicad_sch Sheet: /bpu-iobufffer/


Id: 6/6 Title: File: leds.kicad_sch Sheet: /leds/

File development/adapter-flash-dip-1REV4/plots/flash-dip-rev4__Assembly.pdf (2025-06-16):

DIP8 IC; HLD WP; VCC PIN MISO MOSI; DIP⁸ IC; CLK; VOUT GND; PIN; 1 GND; D1 SW¹; C¹ SW²; D Date: KiCad; E.D.A. 9.0.1 Size: A4; Rev:; Board2Pdf:; Black-And-White-TOP; Page; LED; D1 SW_SPDT SW1; ZIF SOCKET J3; 0.1uF C¹ J2J2 SW_SPDT SW2

Id: /1 Title: File: flash-dip-rev4.kicad_pcb Sheet: Black-And-White-TOP

D Date: KiCad; E.D.A. 9.0.1 Size: A4; Rev:; Id: /1 Title: File: flash-dip-rev4.kicad_pcb Sheet: Black-And-White-BOT Board2Pdf:; Black-And-White-BOT; Page 2/2

Bus Pirate SPI Flash Adapter REV4 U1: DIP8 http://BusPirate.com

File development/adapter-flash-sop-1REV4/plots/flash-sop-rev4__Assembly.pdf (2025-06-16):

HLD WP; VCC_PIN MISO MOSI1 CLK; VOUT GND_PIN GND; C² SW¹; C¹ SW²; D Date: KiCad; E.D.A. 9.0.1 Size: A4; Rev:; Board2Pdf:; Black-And-White-TOP; Page; mm LEDD¹; C² SW_SPDT SW1; 16PIN J3; 20PIN; 0.1uF C¹ J2J2 SW_SPDT SW2

Id: /1 Title: File: flash-sop-rev4.kicad_pcb Sheet: Black-And-White-TOP

D Date: KiCad; E.D.A. 9.0.1 Size: A4; Rev:; Id: /1 Title: File: flash-sop-rev4.kicad_pcb Sheet: Black-And-White-BOT Board2Pdf:; Black-And-White-BOT; Page 2/2

Bus Pirate SPI Serial Flash Adapter REV4 U1: SOP8 208mil U2: SOP8 150mil http://BusPirate.com

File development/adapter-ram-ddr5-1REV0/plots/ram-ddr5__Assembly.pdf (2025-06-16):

# IO7 PGOOD

### SCL GND


Id: /1 Title: File: ram-ddr5.kicad_pcb Sheet: Black-And-White-TOP

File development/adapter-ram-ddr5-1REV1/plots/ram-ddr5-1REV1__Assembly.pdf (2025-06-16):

# IO7 PGOOD

### SCL GND


Id: /1 Title: File: ram-ddr5-1REV1.kicad_pcb Sheet: Black-And-White-TOP

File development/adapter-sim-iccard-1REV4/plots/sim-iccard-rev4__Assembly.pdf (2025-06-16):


Id: /1 Title: File: sim-iccard-rev4.kicad_pcb Sheet: Black-And-White-TOP

D Date: KiCad; E.D.A. 9.0.1 Size: A4; Rev:; Id: /1 Title: File: sim-iccard-rev4.kicad_pcb Sheet: Black-And-White-BOT Board2Pdf:; Black-And-White-BOT; Page 2/2 ⁵¹⁴⁵³⁰⁰⁻³


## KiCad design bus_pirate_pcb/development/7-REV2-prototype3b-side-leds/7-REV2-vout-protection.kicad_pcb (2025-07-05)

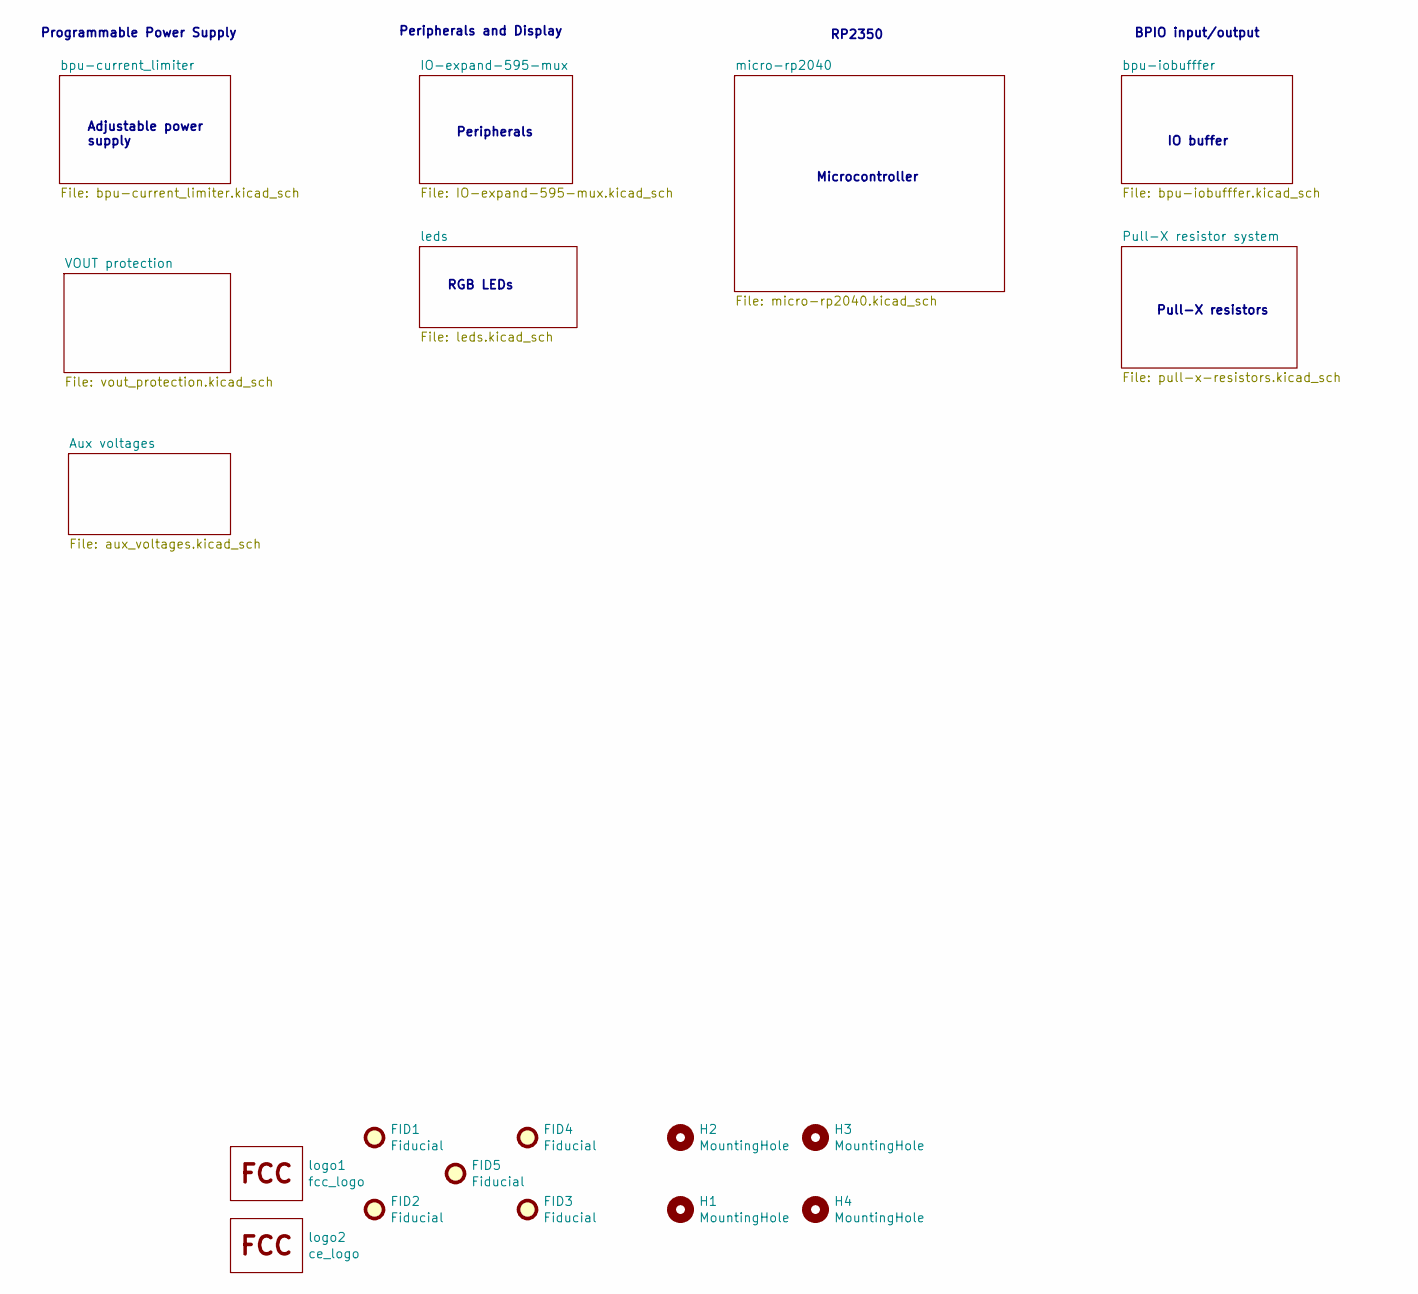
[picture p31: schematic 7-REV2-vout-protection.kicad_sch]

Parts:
FID1, FID2, FID3, FID4, FID5: Fiducial; Fiducial_1mm_Mask2mm
H1, H2, H3, H4: MountingHole; MountingHole_3.2mm_M3
logo1: fcc_logo; logo_fcc
logo2: ce_logo; CE-Logo_11.2x8mm_SilkScreen

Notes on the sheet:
Microcontroller
Programmable Power Supply
BPIO input/output
Adjustable power supply
Peripherals and Display
IO buffer
Peripherals
RGB LEDs
Pull-X resistors
RP2350

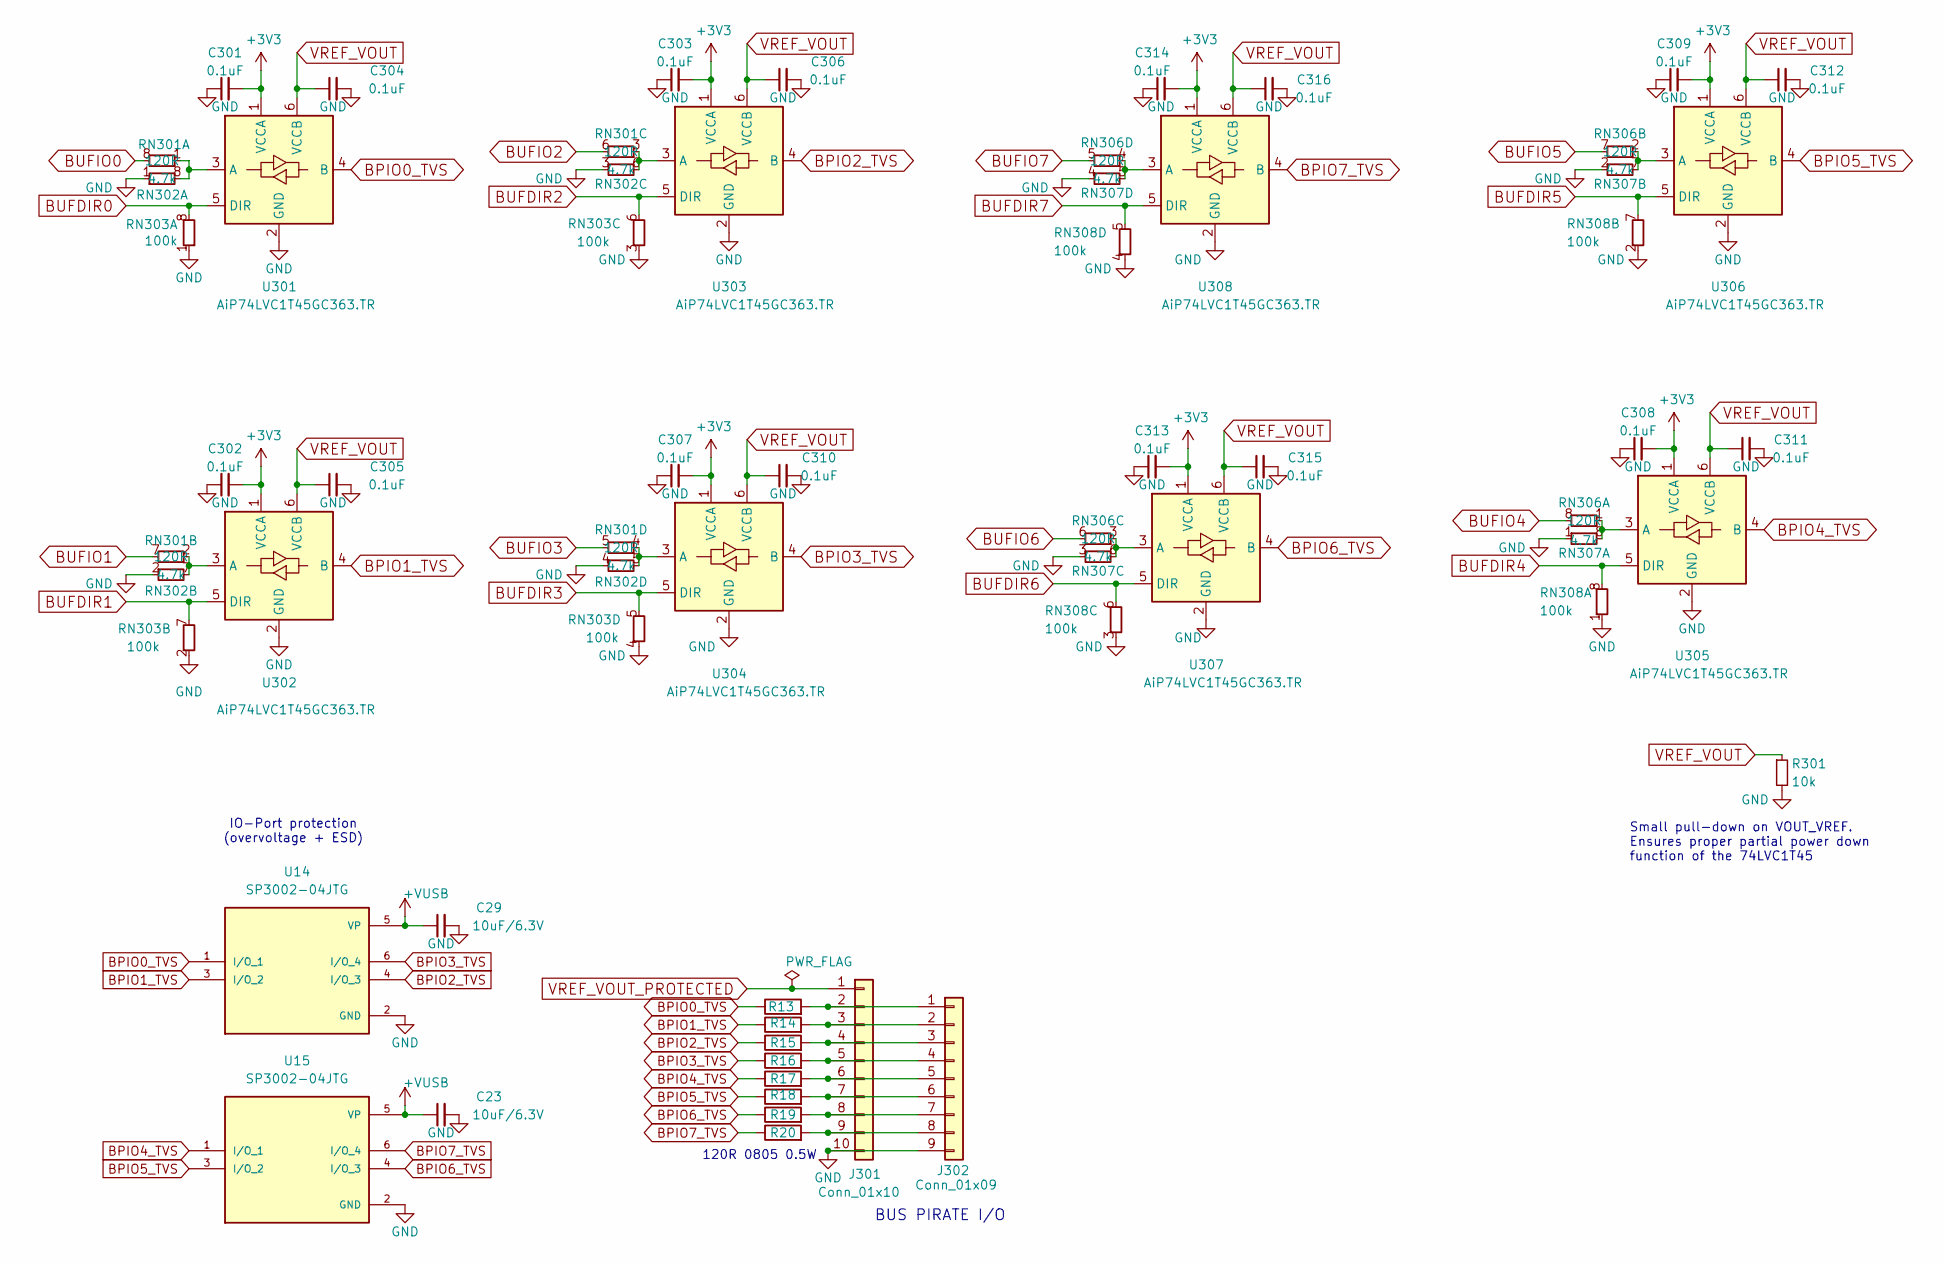
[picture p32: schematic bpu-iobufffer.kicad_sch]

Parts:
C23, C29: 10uF/6.3V; C_0402_1005Metric
C301, C302, C303, C304, C305, C306, C307, C308, C309, C310, C311, C312, C313, C314, C315, C316: 0.1uF; C_0402_1005Metric
J301: Conn_01x10; PinHeader_1x10_P2.54mm_Vertical
J302: Conn_01x09; JST_SH_SM09B-SRSS-TB_1x09-1MP_P1.00mm_Horizontal
R13, R14, R15, R16, R17, R18, R19, R20: 120R 0.5W; R_0805_2012Metric_Pad1.20x1.40mm_HandSolder
R301: 10k; R_0402_1005Metric
RN301, RN306: 120R; R_Array_Convex_4x0402
RN302, RN307: 4.7k; R_Array_Convex_4x0402
RN303, RN308: 100k; R_Array_Convex_4x0402
U14, U15: SP3002-04JTG; SOT-363_SC-70-6
U301, U302, U303, U304, U305, U306, U307, U308: AiP74LVC1T45GC363.TR; SOT-363_SC-70-6

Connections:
+3V3: C301.2, C302.2, C303.2, C307.2, C308.2, C309.2, C313.2, C314.2, U301.1 (VCCA), U302.1 (VCCA), U303.1 (VCCA), U304.1 (VCCA), U305.1 (VCCA), U306.1 (VCCA), U307.1 (VCCA), U308.1 (VCCA); also elsewhere on the board
+VUSB: C23.1, C29.1, U14.5 (VP), U15.5 (VP); also elsewhere on the board
BPIO0_TVS: R13.1, U14.1 (I/O_1), U301.4 (B); also elsewhere on the board
BPIO1_TVS: R14.1, U14.3 (I/O_2), U302.4 (B); also elsewhere on the board
BPIO2_TVS: R15.1, U14.4 (I/O_3), U303.4 (B); also elsewhere on the board
BPIO3_TVS: R16.1, U14.6 (I/O_4), U304.4 (B); also elsewhere on the board
BPIO4_TVS: R17.1, U15.1 (I/O_1), U305.4 (B); also elsewhere on the board
BPIO5_TVS: R18.1, U15.3 (I/O_2), U306.4 (B); also elsewhere on the board
BPIO6_TVS: R19.1, U15.4 (I/O_3), U307.4 (B); also elsewhere on the board
BPIO7_TVS: R20.1, U15.6 (I/O_4), U308.4 (B); also elsewhere on the board
BUFDIR0: RN303.8 (R1.8), U301.5 (DIR); also elsewhere on the board
BUFDIR1: RN303.7 (R1.8), U302.5 (DIR); also elsewhere on the board
BUFDIR2: RN303.6 (R1.8), U303.5 (DIR); also elsewhere on the board
BUFDIR3: RN303.5 (R1.8), U304.5 (DIR); also elsewhere on the board
BUFDIR4: RN308.8 (R1.8), U305.5 (DIR); also elsewhere on the board
BUFDIR5: RN308.7 (R1.8), U306.5 (DIR); also elsewhere on the board
BUFDIR6: RN308.6 (R1.8), U307.5 (DIR); also elsewhere on the board
BUFDIR7: RN308.5 (R1.8), U308.5 (DIR); also elsewhere on the board
BUFIO0: RN301.8 (R1.8); also elsewhere on the board
BUFIO1: RN301.7 (R1.8); also elsewhere on the board
BUFIO2: RN301.6 (R1.8); also elsewhere on the board
BUFIO3: RN301.5 (R1.8); also elsewhere on the board
BUFIO4: RN306.8 (R1.8); also elsewhere on the board
BUFIO5: RN306.7 (R1.8); also elsewhere on the board
BUFIO6: RN306.6 (R1.8); also elsewhere on the board
BUFIO7: RN306.5 (R1.8); also elsewhere on the board
GND: C23.2, C29.2, C301.1, C302.1, C303.1, C304.2, C305.2, C306.2, C307.1, C308.1, C309.1, C310.2, C311.2, C312.2, C313.1, C314.1, C315.2, C316.2, J301.10, J302.9, R301.2, RN302.1 (R1.1), RN302.2 (R1.1), RN302.3 (R1.1), RN302.4 (R1.1), RN303.1 (R1.1), RN303.2 (R1.1), RN303.3 (R1.1), RN303.4 (R1.1), RN307.1 (R1.1), RN307.2 (R1.1), RN307.3 (R1.1), RN307.4 (R1.1), RN308.1 (R1.1), RN308.2 (R1.1), RN308.3 (R1.1), RN308.4 (R1.1), U14.2 (GND), U15.2 (GND), U301.2 (GND), U302.2 (GND), U303.2 (GND), U304.2 (GND), U305.2 (GND), U306.2 (GND), U307.2 (GND), U308.2 (GND); also elsewhere on the board
unnamed: J301.2, J302.1, R13.2
unnamed: J301.3, J302.2, R14.2
unnamed: J301.4, J302.3, R15.2
unnamed: J301.5, J302.4, R16.2
unnamed: J301.6, J302.5, R17.2
unnamed: J301.7, J302.6, R18.2
unnamed: J301.8, J302.7, R19.2
unnamed: J301.9, J302.8, R20.2
unnamed: RN301.1 (R1.1), RN302.8 (R1.8), U301.3 (A)
unnamed: RN301.2 (R1.1), RN302.7 (R1.8), U302.3 (A)
unnamed: RN301.3 (R1.1), RN302.6 (R1.8), U303.3 (A)
unnamed: RN301.4 (R1.1), RN302.5 (R1.8), U304.3 (A)
unnamed: RN306.1 (R1.1), RN307.8 (R1.8), U305.3 (A)
unnamed: RN306.2 (R1.1), RN307.7 (R1.8), U306.3 (A)
unnamed: RN306.3 (R1.1), RN307.6 (R1.8), U307.3 (A)
unnamed: RN306.4 (R1.1), RN307.5 (R1.8), U308.3 (A)
VREF_VOUT: C304.1, C305.1, C306.1, C310.1, C311.1, C312.1, C315.1, C316.1, R301.1, U301.6 (VCCB), U302.6 (VCCB), U303.6 (VCCB), U304.6 (VCCB), U305.6 (VCCB), U306.6 (VCCB), U307.6 (VCCB), U308.6 (VCCB); also elsewhere on the board
VREF_VOUT_PROTECTED: J301.1; also elsewhere on the board

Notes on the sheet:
120R 0805 0.5W
Small pull-down on VOUT_VREF. Ensures proper partial power down function of the 74LVC1T45
BUS PIRATE I/O
IO-Port protection (overvoltage + ESD)

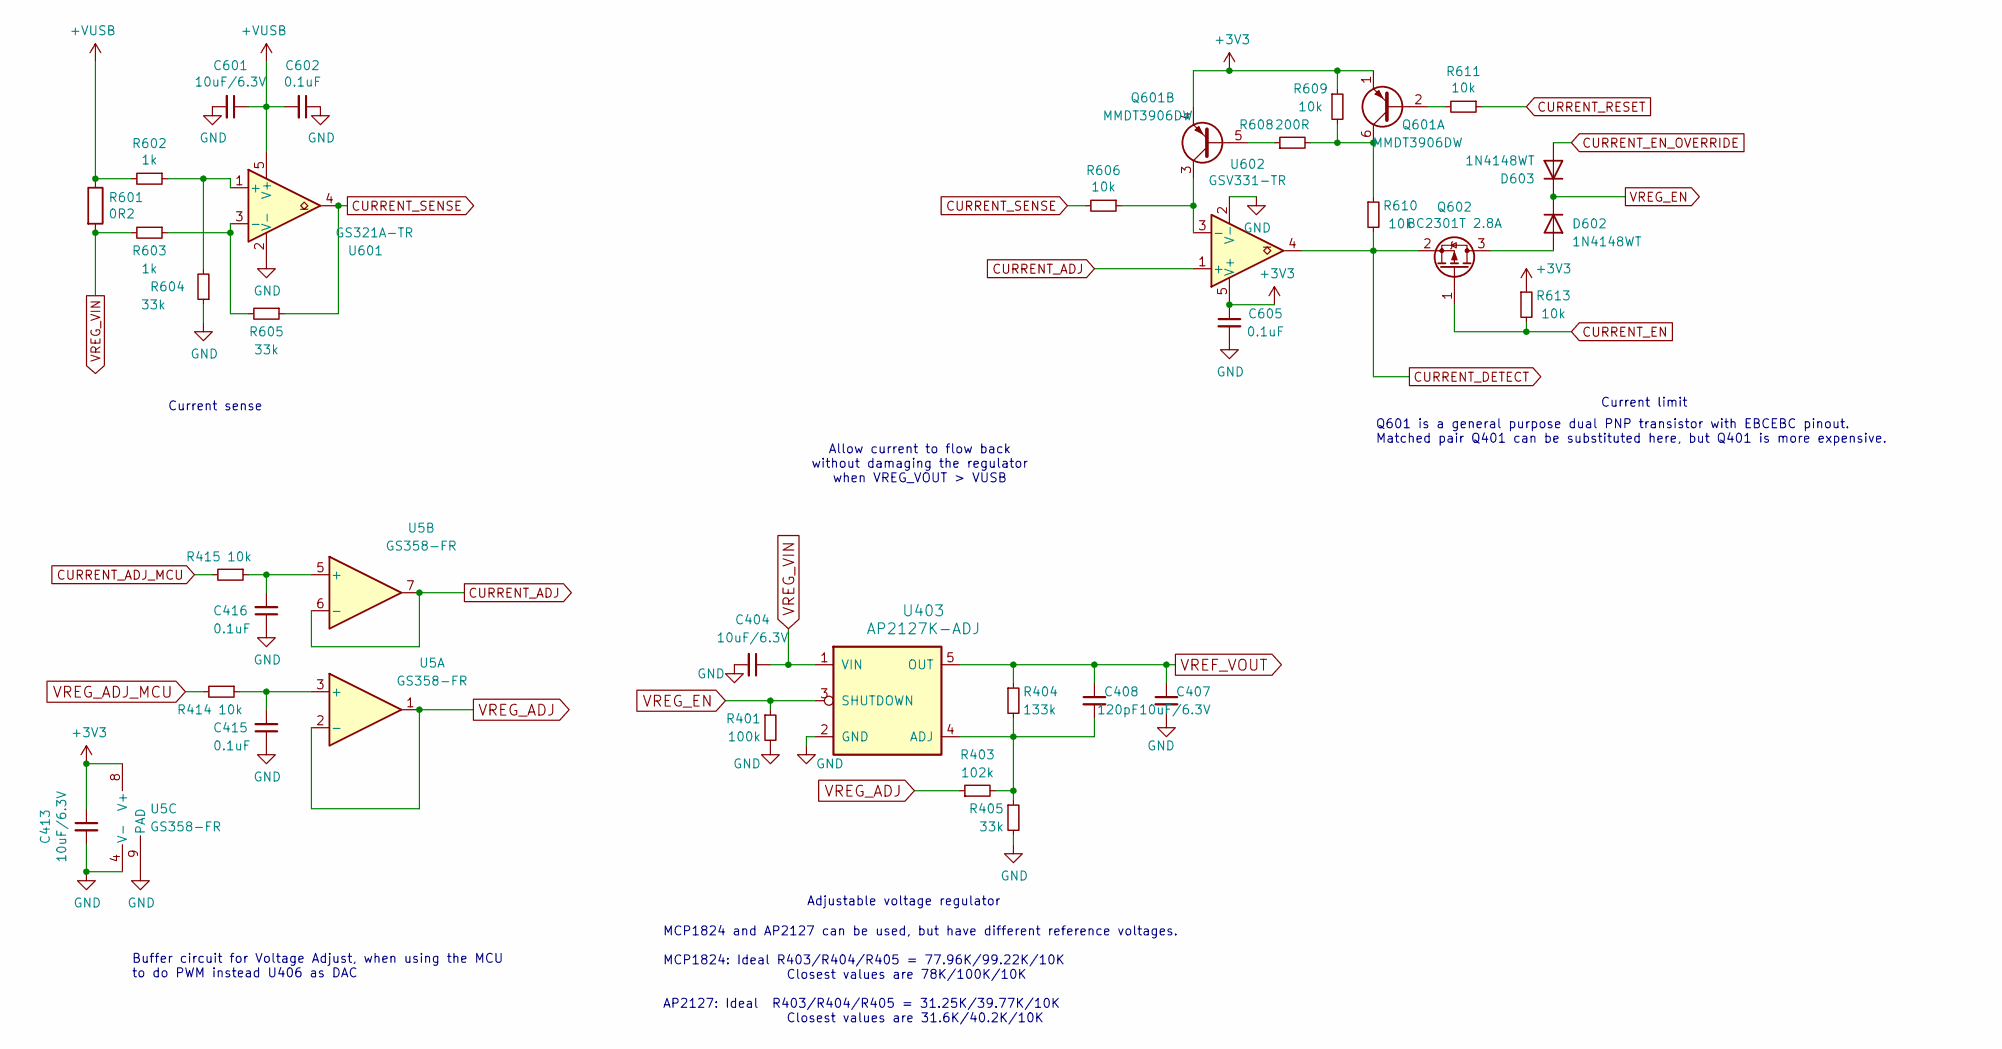
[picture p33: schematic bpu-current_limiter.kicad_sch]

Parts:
C404, C407, C413, C601: 10uF/6.3V; C_0402_1005Metric
C408: 120pF; C_0402_1005Metric
C415, C416, C602, C605: 0.1uF; C_0402_1005Metric
D602, D603: 1N4148WT; D_SOD-523
Q601: MMDT3906DW; SOT-363_SC-70-6
Q602: BC2301T 2.8A; SOT-523
R401: 100k; R_0402_1005Metric
R403: 102k; R_0402_1005Metric
R404: 133k; R_0402_1005Metric
R405, R604, R605: 33k; R_0402_1005Metric
R414, R415, R606, R609, R610, R611, R613: 10k; R_0402_1005Metric
R601: 0R2; R_2512_6332Metric_Pad1.40x3.35mm_HandSolder
R602, R603: 1k; R_0402_1005Metric
R608: 200R; R_0402_1005Metric
U5: GS358-FR; DFN-8-1EP_2x2mm_P0.5mm_EP1.05x1.75mm
U403: AP2127K-ADJ; SOT-23-5
U601: GS321A-TR; SOT-23-5
U602: GSV331-TR; SOT-23-5

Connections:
+3V3: C413.1, C605.1, Q601.1 (E1), Q601.4 (E2), R609.1, R613.1, U5.8 (V+), U602.5 (V+); also elsewhere on the board
+VUSB: C601.1, C602.2, R601.1, R602.2, U601.5 (V+); also elsewhere on the board
CURRENT_ADJ: U5.6 (-), U5.7, U602.1 (+)
CURRENT_ADJ_MCU: R415.2; also elsewhere on the board
CURRENT_DETECT: Q602.2 (S), R610.2, U602.4; also elsewhere on the board
CURRENT_EN: Q602.1 (G), R613.2; also elsewhere on the board
CURRENT_EN_OVERRIDE: D603.2 (A); also elsewhere on the board
CURRENT_RESET: R611.1; also elsewhere on the board
CURRENT_SENSE: R605.1, R606.2, U601.4; also elsewhere on the board
GND: C404.2, C407.2, C413.2, C415.1, C416.1, C601.2, C602.1, C605.2, R401.2, R405.2, R604.1, U5.4 (V-), U5.9 (PAD), U403.2 (GND), U601.2 (V-), U602.2 (V-); also elsewhere on the board
unnamed: D602.2 (A), Q602.3 (D)
unnamed: Q601.2 (B1), R611.2
unnamed: Q601.6 (C1), R608.2, R609.2, R610.1
unnamed: Q601.5 (B2), R608.1
unnamed: Q601.3 (C2), R606.1, U602.3 (-)
unnamed: C415.2, R414.1, U5.3 (+)
unnamed: C416.2, R415.1, U5.5 (+)
unnamed: C408.2, R403.2, R404.2, R405.1, U403.4 (ADJ)
unnamed: R602.1, R604.2, U601.1 (+)
unnamed: R603.1, R605.2, U601.3 (-)
VREF_VOUT: C407.1, C408.1, R404.1, U403.5 (OUT); also elsewhere on the board
VREG_ADJ: R403.1, U5.1, U5.2 (-)
VREG_ADJ_MCU: R414.2; also elsewhere on the board
VREG_EN: D602.1 (K), D603.1 (K), R401.1, U403.3 (SHUTDOWN)
VREG_VIN: C404.1, R601.2, R603.2, U403.1 (VIN)

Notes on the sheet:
Adjustable voltage regulator
Current sense
Allow current to flow back without damaging the regulator when VREG_VOUT > VUSB
MCP1824 and AP2127 can be used, but have different reference voltages. MCP1824: Ideal R403/R404/R405 = 77.96K/99.22K/10K Closest values are 78K/100K/10K AP2127: Ideal R403/R404/R405 = 31.25K/39.77K/10K Closest values are 31.6K/40.2K/10K
Current limit
Buffer circuit for Voltage Adjust, when using the MCU to do PWM instead U406 as DAC
Q601 is a general purpose dual PNP transistor with EBCEBC pinout. Matched pair Q401 can be substituted here, but Q401 is more expensive.

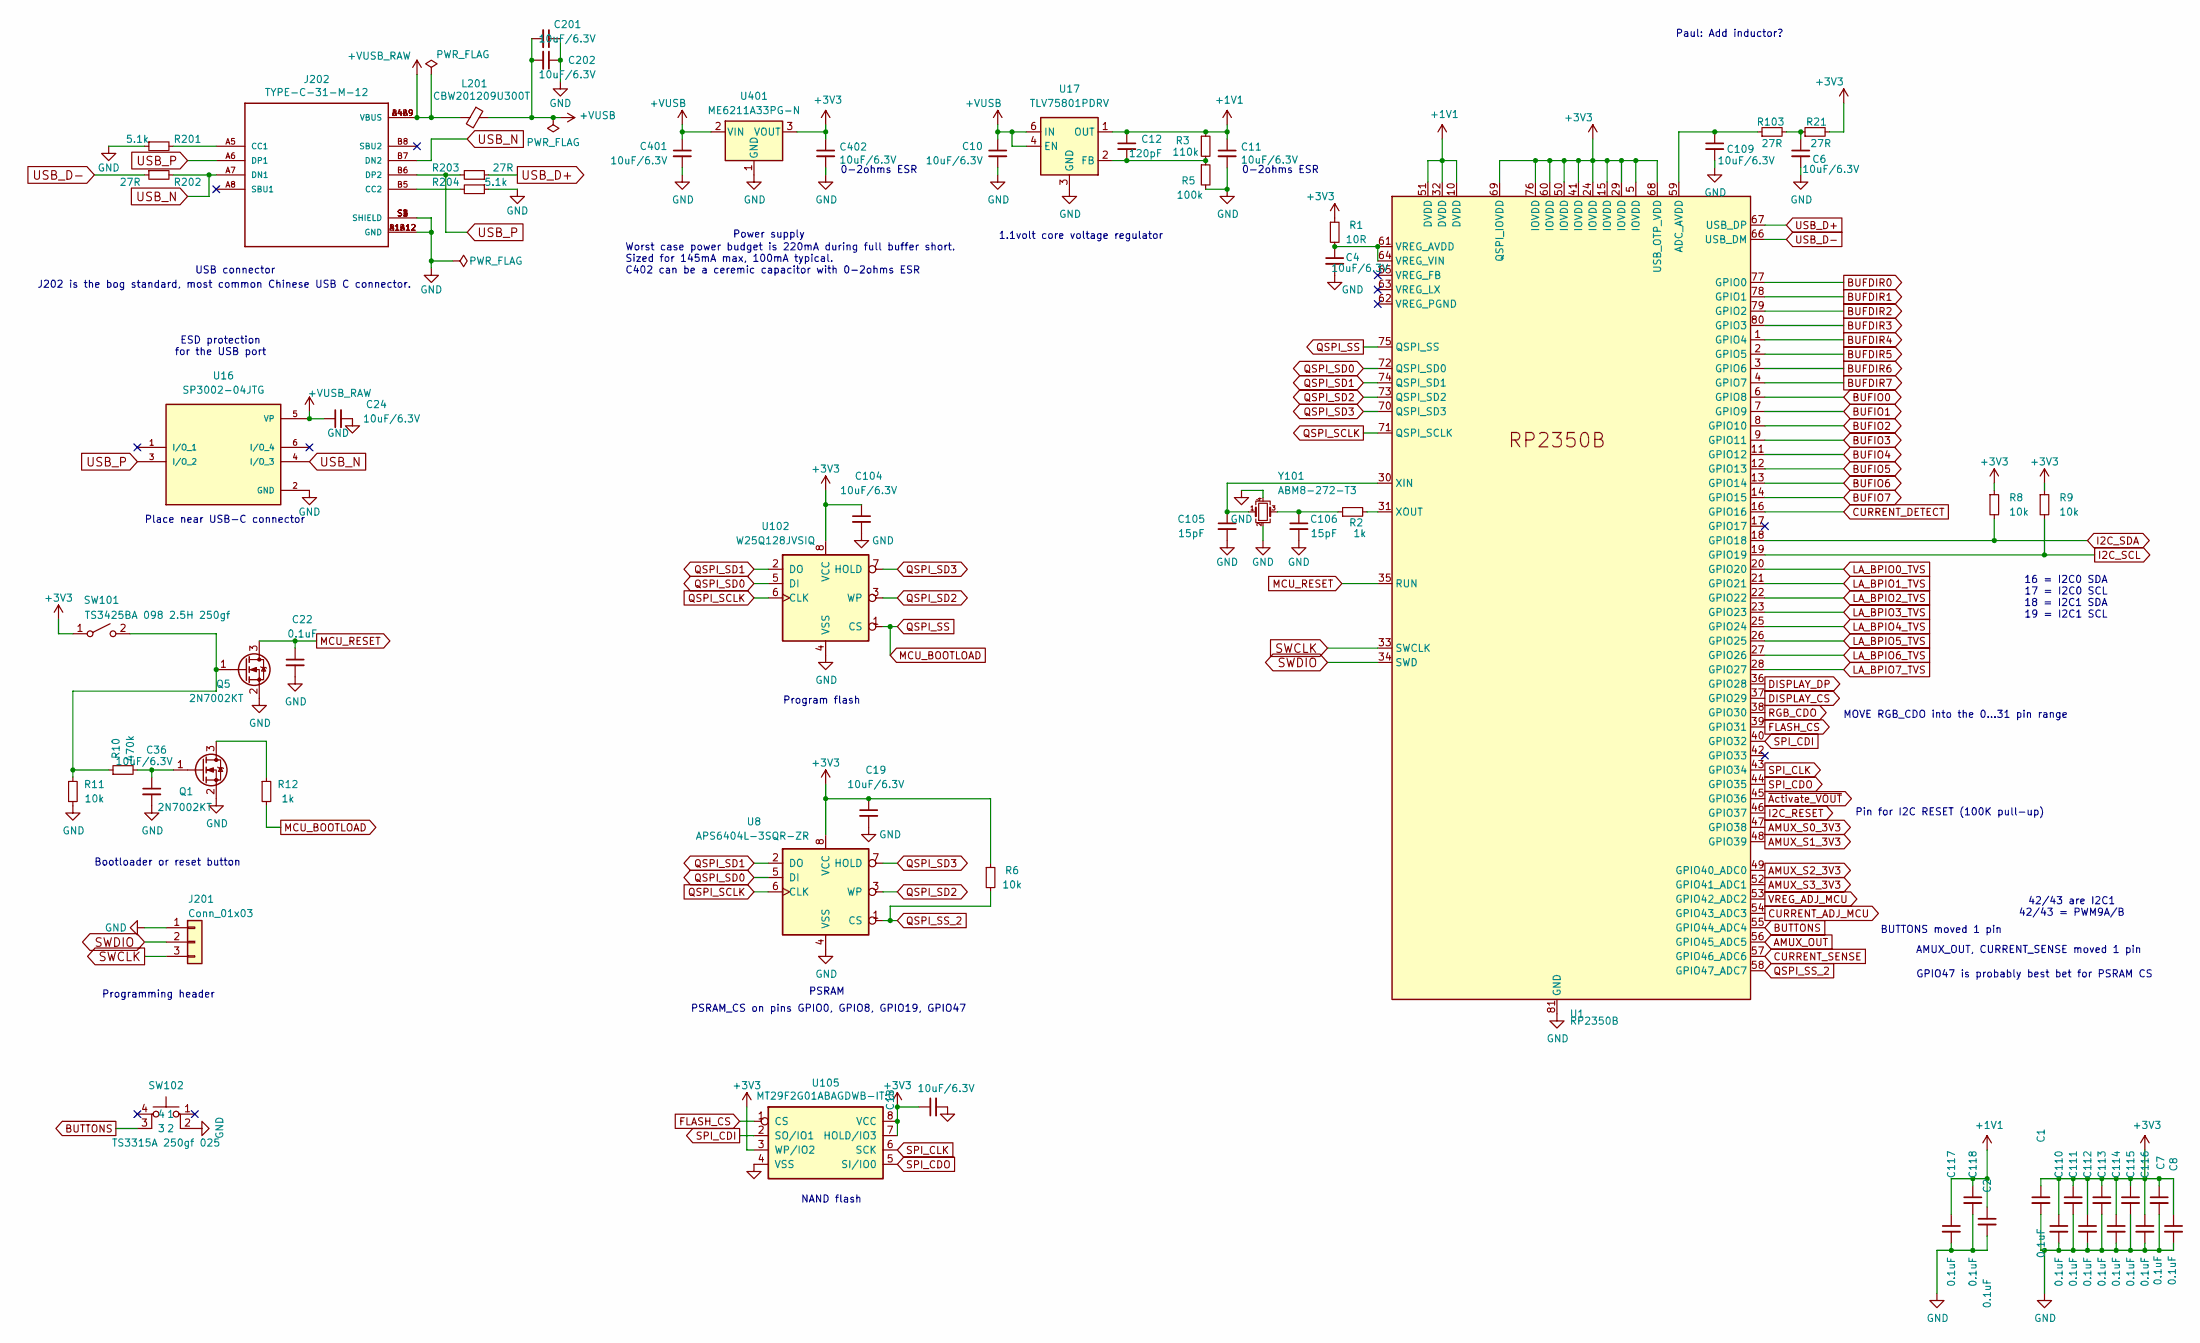
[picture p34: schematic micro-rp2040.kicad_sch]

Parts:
C1, C2, C7, C8, C22, C110, C111, C112, C113, C114, C115, C116, C117, C118: 0.1uF; C_0402_1005Metric
C4, C6, C10, C11, C18, C19, C24, C36, C104, C109, C201, C202, C401, C402: 10uF/6.3V; C_0402_1005Metric
C12: 120pF; C_0402_1005Metric
C105, C106: 15pF; C_0402_1005Metric
J201: Conn_01x03; PinSocket_1x03_P2.54mm_Vertical
J202: TYPE-C-31-M-12; HRO_TYPE-C-31-M-12
L201: CBW201209U300T; L_0805_2012Metric
Q1, Q5: 2N7002KT; SOT-523
R1: 10R; R_0402_1005Metric
R2, R12: 1k; R_0402_1005Metric
R3: 110k; R_0402_1005Metric
R5: 100k; R_0402_1005Metric
R6, R8, R9, R11: 10k; R_0402_1005Metric
R10: 470k; R_0402_1005Metric
R21, R103, R202, R203: 27R; R_0402_1005Metric
R201, R204: 5.1k; R_0402_1005Metric
SW101: TS3425BA 098 2.5H 250gf; SW_SPST_PTS810
SW102: TS3315A 250gf 025; GT-TC026X-HXXX-LX
U1: RP2350B; qfn80
U8: APS6404L-3SQR-ZR; USON-8-3x2mm_P0.5mm_EPthin
U16: SP3002-04JTG; SOT-363_SC-70-6
U17: TLV75801PDRV; WSON-6-1EP_2x2mm_P0.65mm_EP1x1.6mm
U102: W25Q128JVSIQ; SOP-8_5.28x5.23mm_P1.27mm
U105: MT29F2G01ABAGDWB-IT:G; U-PDFN-8
U401: ME6211A33PG-N; SOT-89-3
Y101: ABM8-272-T3; Crystal_SMD_3225-4Pin_3.2x2.5mm

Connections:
+1V1: C2.1, C11.1, C12.1, C117.1, C118.1, R3.1, U1.10 (DVDD), U1.32 (DVDD), U1.51 (DVDD), U17.1 (OUT)
+3V3: C1.1, C7.1, C8.1, C18.1, C19.1, C104.1, C110.1, C111.1, C112.1, C113.1, C114.1, C115.1, C116.1, C402.1, R1.1, R6.1, R8.1, R9.1, R21.2, SW101.1 (A), U1.5 (IOVDD), U1.15 (IOVDD), U1.24 (IOVDD), U1.29 (IOVDD), U1.41 (IOVDD), U1.50 (IOVDD), U1.60 (IOVDD), U1.68 (USB_OTP_VDD), U1.69 (QSPI_IOVDD), U1.76 (IOVDD), U8.8 (VCC), U102.8 (VCC), U105.3 (WP/IO2), U105.7 (HOLD/IO3), U105.8 (VCC), U401.3 (VOUT); also elsewhere on the board
+VUSB: C10.1, C201.2, C202.2, C401.1, L201.1, U17.4 (EN), U17.6 (IN), U401.2 (VIN); also elsewhere on the board
+VUSB_RAW: C24.1, J202.A4B9 (VBUS), J202.B4A9 (VBUS), L201.2, U16.5 (VP)
AMUX_OUT: U1.56 (GPIO45_ADC5); also elsewhere on the board
AMUX_S0_3V3: U1.47 (GPIO38); also elsewhere on the board
AMUX_S1_3V3: U1.48 (GPIO39); also elsewhere on the board
AMUX_S2_3V3: U1.49 (GPIO40_ADC0); also elsewhere on the board
AMUX_S3_3V3: U1.52 (GPIO41_ADC1); also elsewhere on the board
BUFDIR0: U1.77 (GPIO0); also elsewhere on the board
BUFDIR1: U1.78 (GPIO1); also elsewhere on the board
BUFDIR2: U1.79 (GPIO2); also elsewhere on the board
BUFDIR3: U1.80 (GPIO3); also elsewhere on the board
BUFDIR4: U1.1 (GPIO4); also elsewhere on the board
BUFDIR5: U1.2 (GPIO5); also elsewhere on the board
BUFDIR6: U1.3 (GPIO6); also elsewhere on the board
BUFDIR7: U1.4 (GPIO7); also elsewhere on the board
BUFIO0: U1.6 (GPIO8); also elsewhere on the board
BUFIO1: U1.7 (GPIO9); also elsewhere on the board
BUFIO2: U1.8 (GPIO10); also elsewhere on the board
BUFIO3: U1.9 (GPIO11); also elsewhere on the board
BUFIO4: U1.11 (GPIO12); also elsewhere on the board
BUFIO5: U1.12 (GPIO13); also elsewhere on the board
BUFIO6: U1.13 (GPIO14); also elsewhere on the board
BUFIO7: U1.14 (GPIO15); also elsewhere on the board
BUTTONS: SW102.3, U1.55 (GPIO44_ADC4)
CURRENT_ADJ_MCU: U1.54 (GPIO43_ADC3); also elsewhere on the board
CURRENT_DETECT: U1.16 (GPIO16); also elsewhere on the board
CURRENT_SENSE: U1.57 (GPIO46_ADC6); also elsewhere on the board
DISPLAY_CS: U1.37 (GPIO29); also elsewhere on the board
DISPLAY_DP: U1.36 (GPIO28); also elsewhere on the board
FLASH_CS: U1.39 (GPIO31), U105.1 (CS)
GND: C1.2, C2.2, C4.2, C6.2, C7.2, C8.2, C10.2, C11.2, C18.2, C19.2, C22.2, C24.2, C36.2, C104.2, C105.2, C106.2, C109.2, C110.2, C111.2, C112.2, C113.2, C114.2, C115.2, C116.2, C117.2, C118.2, C201.1, C202.1, C401.2, C402.2, J201.1, J202.A1B12 (GND), J202.B1A12 (GND), J202.S1 (SHIELD), J202.S2 (SHIELD), J202.S3 (SHIELD), J202.S4 (SHIELD), Q1.2 (S), Q5.2 (S), R5.2, R11.2, R201.1, R204.1, SW102.2, U1.81 (GND), U8.4 (VSS), U16.2 (GND), U17.3 (GND), U17.7 (GND), U102.4 (VSS), U105.4 (VSS), U401.1 (GND), Y101.2, Y101.4; also elsewhere on the board
I2C_RESET: U1.46 (GPIO37); also elsewhere on the board
I2C_SCL: R9.2, U1.19 (GPIO19); also elsewhere on the board
I2C_SDA: R8.2, U1.18 (GPIO18); also elsewhere on the board
LA_BPIO0_TVS: U1.20 (GPIO20); also elsewhere on the board
LA_BPIO1_TVS: U1.21 (GPIO21); also elsewhere on the board
LA_BPIO2_TVS: U1.22 (GPIO22); also elsewhere on the board
LA_BPIO3_TVS: U1.23 (GPIO23); also elsewhere on the board
LA_BPIO4_TVS: U1.25 (GPIO24); also elsewhere on the board
LA_BPIO5_TVS: U1.26 (GPIO25); also elsewhere on the board
LA_BPIO6_TVS: U1.27 (GPIO26); also elsewhere on the board
LA_BPIO7_TVS: U1.28 (GPIO27); also elsewhere on the board
MCU_BOOTLOAD: R12.2, U1.75 (QSPI_SS), U102.1 (CS)
MCU_RESET: C22.1, Q5.3 (D), U1.35 (RUN)
unnamed: C6.1, R21.1, R103.2
unnamed: C106.1, R2.1, Y101.3
unnamed: J202.A5 (CC1), R201.2
unnamed: J202.B5 (CC2), R204.2
unnamed: Q1.3 (D), R12.1
unnamed: C36.1, Q1.1 (G), R10.2
unnamed: Q5.1 (G), R10.1, R11.1, SW101.2 (B)
unnamed: C109.1, R103.1, U1.59 (ADC_AVDD)
unnamed: C4.1, R1.2, U1.61 (VREG_AVDD), U1.64 (VREG_VIN)
unnamed: C105.1, U1.30 (XIN), Y101.1
unnamed: R2.2, U1.31 (XOUT)
unnamed: C12.2, R3.2, R5.1, U17.2 (FB)
QSPI_SCLK: U1.71 (QSPI_SCLK), U8.6 (CLK), U102.6 (CLK)
QSPI_SD0: U1.72 (QSPI_SD0), U8.5 (DI), U102.5 (DI)
QSPI_SD1: U1.74 (QSPI_SD1), U8.2 (DO), U102.2 (DO)
QSPI_SD2: U1.73 (QSPI_SD2), U8.3 (WP), U102.3 (WP)
QSPI_SD3: U1.70 (QSPI_SD3), U8.7 (HOLD), U102.7 (HOLD)
QSPI_SS_2: R6.2, U1.58 (GPIO47_ADC7), U8.1 (CS)
RGB_CDO: U1.38 (GPIO30); also elsewhere on the board
SPI_CDI: U1.40 (GPIO32), U105.2 (SO/IO1)
SPI_CDO: U1.44 (GPIO35), U105.5 (SI/IO0); also elsewhere on the board
SPI_CLK: U1.43 (GPIO34), U105.6 (SCK); also elsewhere on the board
SWCLK: J201.3, U1.33 (SWCLK)
SWDIO: J201.2, U1.34 (SWD)
USB_D+: R203.1, U1.67 (USB_DP)
USB_D-: R202.1, U1.66 (USB_DM)
USB_N: J202.A7 (DN1), J202.B7 (DN2), R202.2, U16.4 (I/O_3)
USB_P: J202.A6 (DP1), J202.B6 (DP2), R203.2, U16.3 (I/O_2)
VREG_ADJ_MCU: U1.53 (GPIO42_ADC2); also elsewhere on the board
~Activate_VOUT: U1.45 (GPIO36); also elsewhere on the board

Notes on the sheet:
42/43 are I2C1 42/43 = PWM9A/B
PSRAM
GPIO47 is probably best bet for PSRAM CS
USB connector
NAND flash
Pin for I2C RESET (100K pull-up)
Bootloader or reset button
Place near USB-C connector
16 = I2C0 SDA 17 = I2C0 SCL 18 = I2C1 SDA 19 = I2C1 SCL
Power supply
ESD protection for the USB port
AMUX_OUT, CURRENT_SENSE moved 1 pin
MOVE RGB_CDO into the 0...31 pin range
J202 is the bog standard, most common Chinese USB C connector.
Program flash
Worst case power budget is 220mA during full buffer short. Sized for 145mA max, 100mA typical. C402 can be a ceremic capacitor with 0-2ohms ESR
Paul: Add inductor?
1.1volt core voltage regulator
PSRAM_CS on pins GPIO0, GPIO8, GPIO19, GPIO47
Programming header
0-2ohms ESR
BUTTONS moved 1 pin

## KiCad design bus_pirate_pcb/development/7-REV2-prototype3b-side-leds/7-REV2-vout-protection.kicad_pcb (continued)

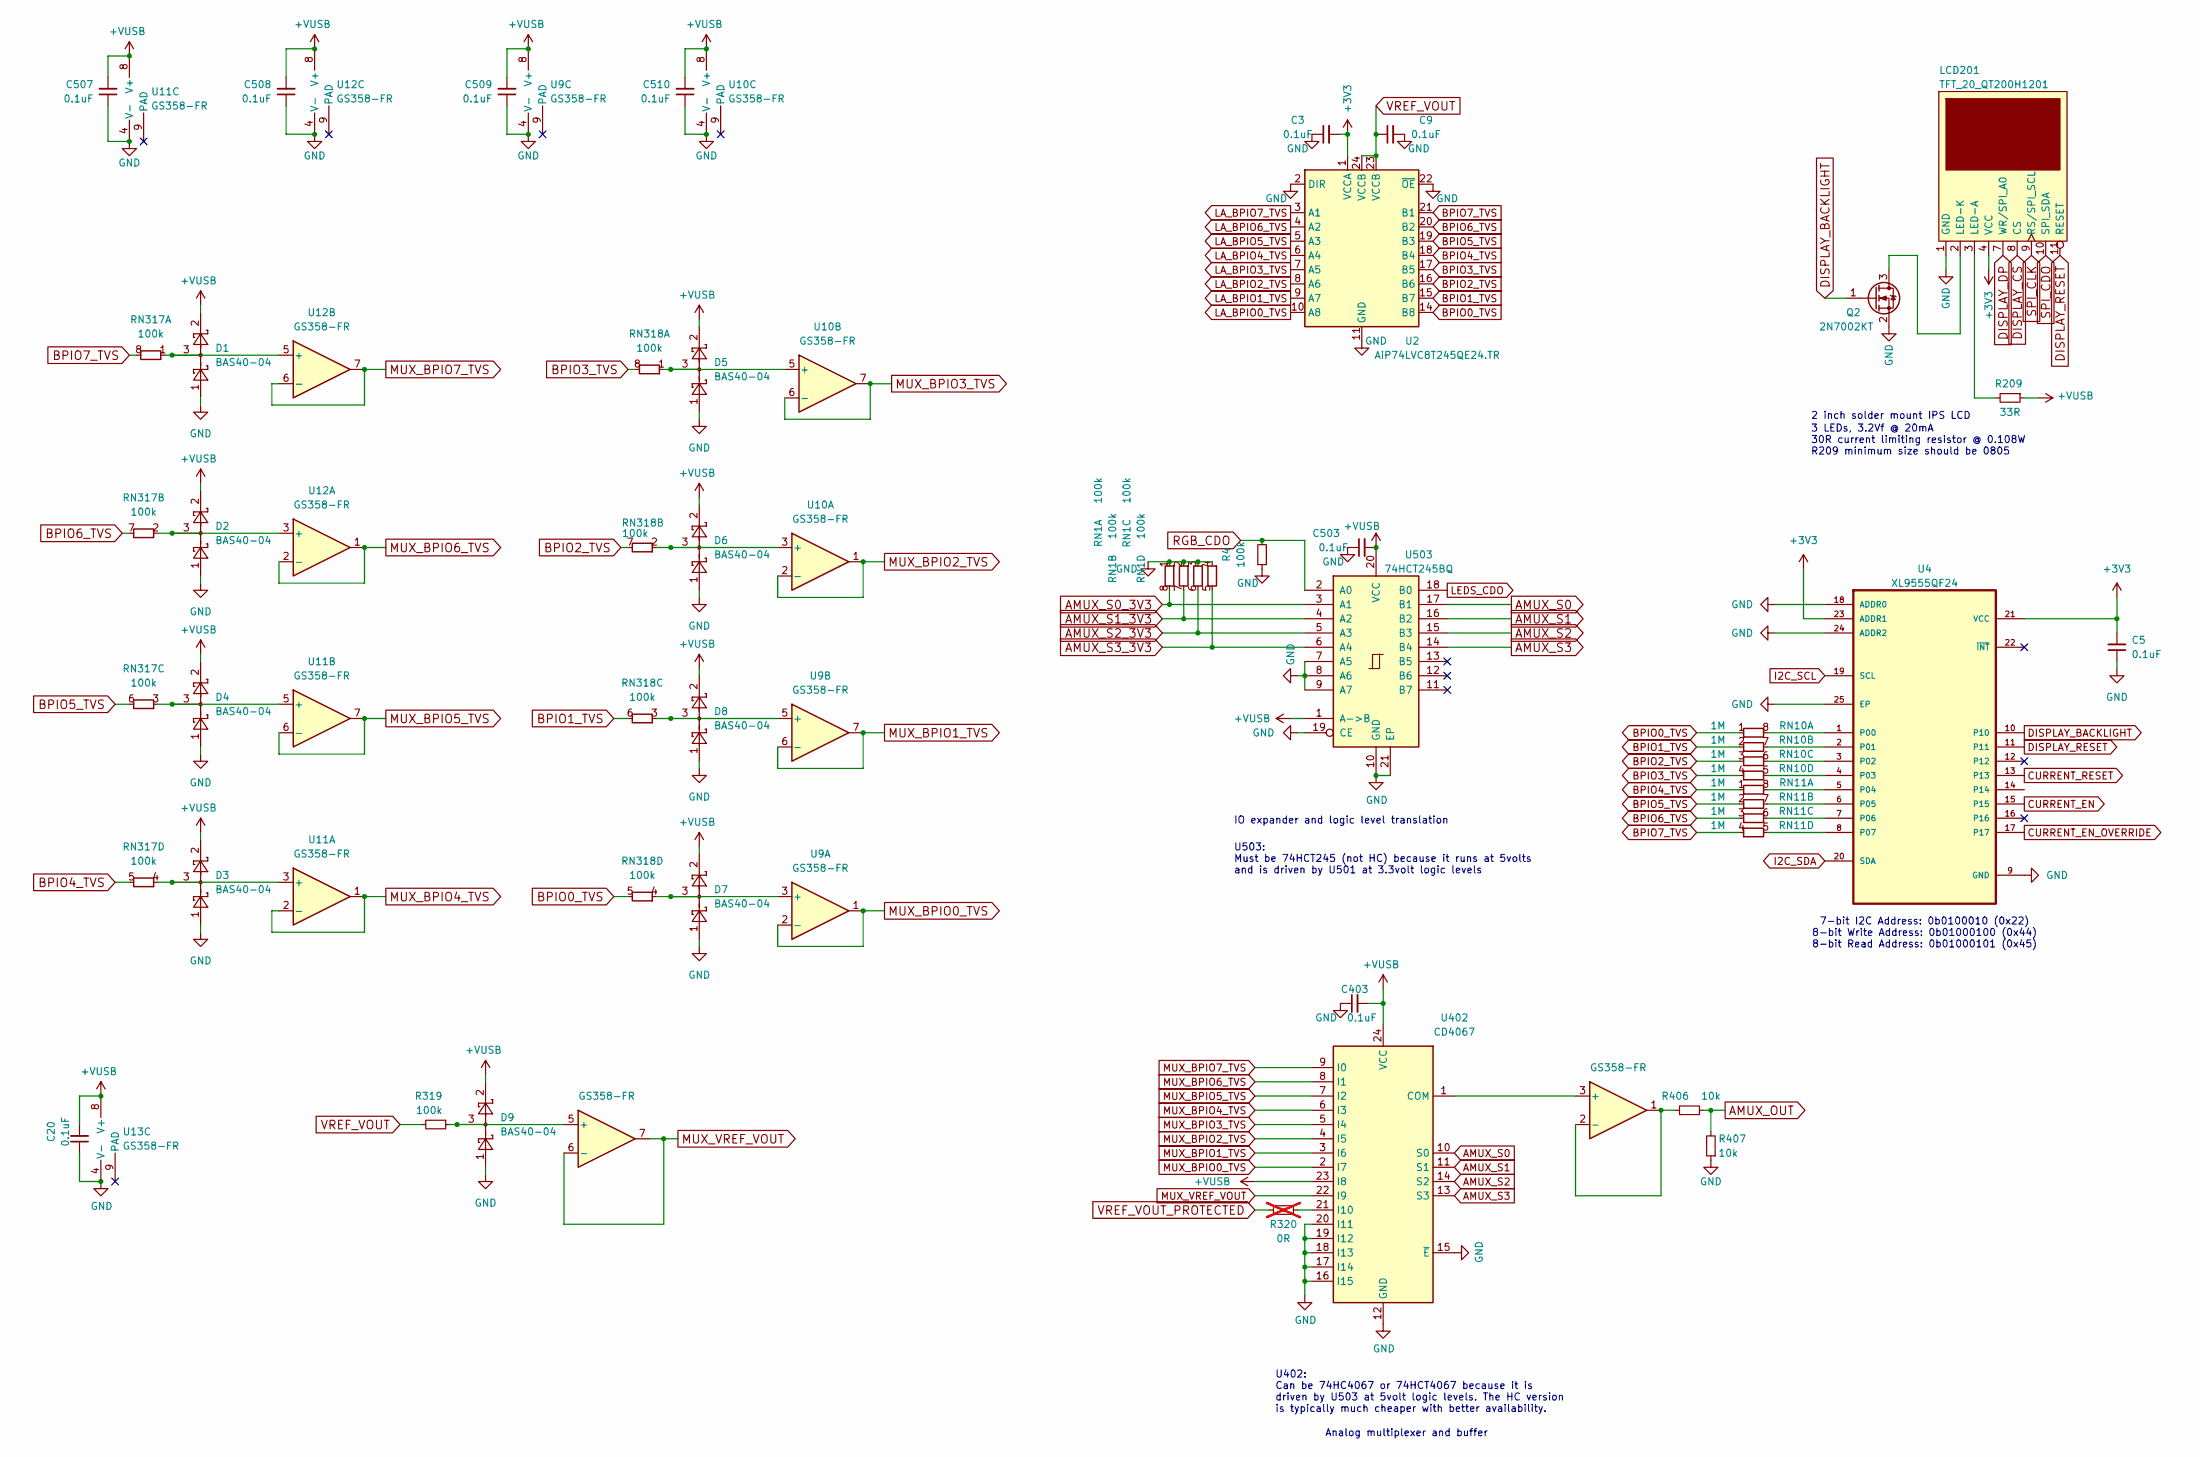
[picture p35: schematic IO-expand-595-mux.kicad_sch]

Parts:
C3, C5, C9, C20, C403, C503, C507, C508, C509, C510: 0.1uF; C_0402_1005Metric
D1, D2, D3, D4, D5, D6, D7, D8, D9: BAS40-04; SOT-523
LCD201: TFT_20_QT200H1201
Q2: 2N7002KT; SOT-523
R4, R319: 100k; R_0402_1005Metric
R209: 33R; R_0805_2012Metric
R320: 0R; R_0402_1005Metric; not fitted
R406, R407: 10k; R_0402_1005Metric
RN1, RN317, RN318: 100k; R_Array_Convex_4x0402
RN10, RN11: 1M; R_Array_Convex_4x0402
U2: AiP74LVC8T245QE24.TR; NXP-DHVQFN24
U4: XL9555QF24; QFN-24-1EP_4x4mm_P0.5mm_EP2.7x2.7mm
U9, U10, U11, U12, U13: GS358-FR; DFN-8-1EP_2x2mm_P0.5mm_EP1.05x1.75mm
U402: CD4067; TSSOP-24_4.4x7.8mm_P0.65mm
U503: 74HCT245BQ; DHVQFN-20-1EP_2.5x4.5mm_P0.5mm_EP1x3mm

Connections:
+3V3: C3.2, C5.2, LCD201.4 (VCC), U2.1 (VCCA), U4.21 (VCC), U4.23 (ADDR1); also elsewhere on the board
+VUSB: C20.2, C403.2, C503.2, C507.2, C508.2, C509.2, C510.2, D1.2, D2.2, D3.2, D4.2, D5.2, D6.2, D7.2, D8.2, D9.2, R209.1, U9.8 (V+), U10.8 (V+), U11.8 (V+), U12.8 (V+), U13.8 (V+), U402.23 (I8), U402.24 (VCC), U503.1 (A->B), U503.20 (VCC); also elsewhere on the board
AMUX_OUT: R406.2, R407.2; also elsewhere on the board
AMUX_S0: U402.10 (S0), U503.17 (B1)
AMUX_S0_3V3: RN1.8 (R1.8), U503.3 (A1); also elsewhere on the board
AMUX_S1: U402.11 (S1), U503.16 (B2)
AMUX_S1_3V3: RN1.7 (R1.8), U503.4 (A2); also elsewhere on the board
AMUX_S2: U402.14 (S2), U503.15 (B3)
AMUX_S2_3V3: RN1.6 (R1.8), U503.5 (A3); also elsewhere on the board
AMUX_S3: U402.13 (S3), U503.14 (B4)
AMUX_S3_3V3: RN1.5 (R1.8), U503.6 (A4); also elsewhere on the board
BPIO0_TVS: RN10.1 (R1.1), RN318.5 (R1.8), U2.14 (B8); also elsewhere on the board
BPIO1_TVS: RN10.2 (R1.1), RN318.6 (R1.8), U2.15 (B7); also elsewhere on the board
BPIO2_TVS: RN10.3 (R1.1), RN318.7 (R1.8), U2.16 (B6); also elsewhere on the board
BPIO3_TVS: RN10.4 (R1.1), RN318.8 (R1.8), U2.17 (B5); also elsewhere on the board
BPIO4_TVS: RN11.1 (R1.1), RN317.5 (R1.8), U2.18 (B4); also elsewhere on the board
BPIO5_TVS: RN11.2 (R1.1), RN317.6 (R1.8), U2.19 (B3); also elsewhere on the board
BPIO6_TVS: RN11.3 (R1.1), RN317.7 (R1.8), U2.20 (B2); also elsewhere on the board
BPIO7_TVS: RN11.4 (R1.1), RN317.8 (R1.8), U2.21 (B1); also elsewhere on the board
CURRENT_EN: U4.15; also elsewhere on the board
CURRENT_EN_OVERRIDE: U4.17; also elsewhere on the board
CURRENT_RESET: U4.13; also elsewhere on the board
DISPLAY_BACKLIGHT: Q2.1 (G), U4.10
DISPLAY_CS: LCD201.8 (CS); also elsewhere on the board
DISPLAY_DP: LCD201.7 (WR/SPI_A0); also elsewhere on the board
DISPLAY_RESET: LCD201.11 (RESET), U4.11
GND: C3.1, C5.1, C9.2, C20.1, C403.1, C503.1, C507.1, C508.1, C509.1, C510.1, D1.1, D2.1, D3.1, D4.1, D5.1, D6.1, D7.1, D8.1, D9.1, LCD201.1 (GND), LCD201.5 (GND), LCD201.6 (GND), LCD201.12 (GND), Q2.2 (S), R4.1, R407.1, RN1.1 (R1.1), RN1.2 (R1.1), RN1.3 (R1.1), RN1.4 (R1.1), U2.2 (DIR), U2.11 (GND), U2.12 (GND), U2.13 (GND), U2.22 (~OE), U4.9 (GND), U4.18 (ADDR0), U4.24 (ADDR2), U4.25 (EP), U9.4 (V-), U10.4 (V-), U11.4 (V-), U12.4 (V-), U13.4 (V-), U402.12 (GND), U402.15 (~E), U402.16 (I15), U402.17 (I14), U402.18 (I13), U402.19 (I12), U402.20 (I11), U503.7 (A5), U503.8 (A6), U503.9 (A7), U503.10 (GND), U503.19 (CE), U503.21 (EP); also elsewhere on the board
I2C_SCL: U4.19 (SCL); also elsewhere on the board
I2C_SDA: U4.20 (SDA); also elsewhere on the board
LA_BPIO0_TVS: U2.10 (A8); also elsewhere on the board
LA_BPIO1_TVS: U2.9 (A7); also elsewhere on the board
LA_BPIO2_TVS: U2.8 (A6); also elsewhere on the board
LA_BPIO3_TVS: U2.7 (A5); also elsewhere on the board
LA_BPIO4_TVS: U2.6 (A4); also elsewhere on the board
LA_BPIO5_TVS: U2.5 (A3); also elsewhere on the board
LA_BPIO6_TVS: U2.4 (A2); also elsewhere on the board
LA_BPIO7_TVS: U2.3 (A1); also elsewhere on the board
LEDS_CDO: U503.18 (B0); also elsewhere on the board
MUX_BPIO0_TVS: U9.1, U9.2 (-), U402.2 (I7)
MUX_BPIO1_TVS: U9.6 (-), U9.7, U402.3 (I6)
MUX_BPIO2_TVS: U10.1, U10.2 (-), U402.4 (I5)
MUX_BPIO3_TVS: U10.6 (-), U10.7, U402.5 (I4)
MUX_BPIO4_TVS: U11.1, U11.2 (-), U402.6 (I3)
MUX_BPIO5_TVS: U11.6 (-), U11.7, U402.7 (I2)
MUX_BPIO6_TVS: U12.1, U12.2 (-), U402.8 (I1)
MUX_BPIO7_TVS: U12.6 (-), U12.7, U402.9 (I0)
MUX_VREF_VOUT: U13.6 (-), U13.7, U402.22 (I9)
unnamed: LCD201.3 (LED-A), R209.2
unnamed: LCD201.2 (LED-K), Q2.3 (D)
unnamed: RN10.8 (R1.8), U4.1 (P00)
unnamed: RN10.7 (R1.8), U4.2 (P01)
unnamed: RN10.6 (R1.8), U4.3 (P02)
unnamed: RN10.5 (R1.8), U4.4 (P03)
unnamed: RN11.8 (R1.8), U4.5 (P04)
unnamed: RN11.7 (R1.8), U4.6 (P05)
unnamed: RN11.6 (R1.8), U4.7 (P06)
unnamed: RN11.5 (R1.8), U4.8 (P07)
unnamed: D1.3, RN317.1 (R1.1), U12.5 (+)
unnamed: D2.3, RN317.2 (R1.1), U12.3 (+)
unnamed: D4.3, RN317.3 (R1.1), U11.5 (+)
unnamed: D3.3, RN317.4 (R1.1), U11.3 (+)
unnamed: D5.3, RN318.1 (R1.1), U10.5 (+)
unnamed: D6.3, RN318.2 (R1.1), U10.3 (+)
unnamed: D8.3, RN318.3 (R1.1), U9.5 (+)
unnamed: D7.3, RN318.4 (R1.1), U9.3 (+)
unnamed: U13.3 (+), U402.1 (COM)
unnamed: R406.1, U13.1, U13.2 (-)
unnamed: D9.3, R319.1, U13.5 (+)
unnamed: R320.1, U402.21 (I10)
RGB_CDO: R4.2, U503.2 (A0); also elsewhere on the board
SPI_CDO: LCD201.10 (SPI_SDA); also elsewhere on the board
SPI_CLK: LCD201.9 (RS/SPI_SCL); also elsewhere on the board
VREF_VOUT: C9.1, R319.2, U2.23 (VCCB), U2.24 (VCCB); also elsewhere on the board
VREF_VOUT_PROTECTED: R320.2; also elsewhere on the board

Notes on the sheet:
7-bit I2C Address: 0b0100010 (0x22) 8-bit Write Address: 0b01000100 (0x44) 8-bit Read Address: 0b01000101 (0x45)
IO expander and logic level translation
Analog multiplexer and buffer
U402: Can be 74HC4067 or 74HCT4067 because it is driven by U503 at 5volt logic levels. The HC version is typically much cheaper with better availability.
3 LEDs, 3.2Vf @ 20mA 30R current limiting resistor @ 0.108W R209 minimum size should be 0805
2 inch solder mount IPS LCD
U503: Must be 74HCT245 (not HC) because it runs at 5volts and is driven by U501 at 3.3volt logic levels

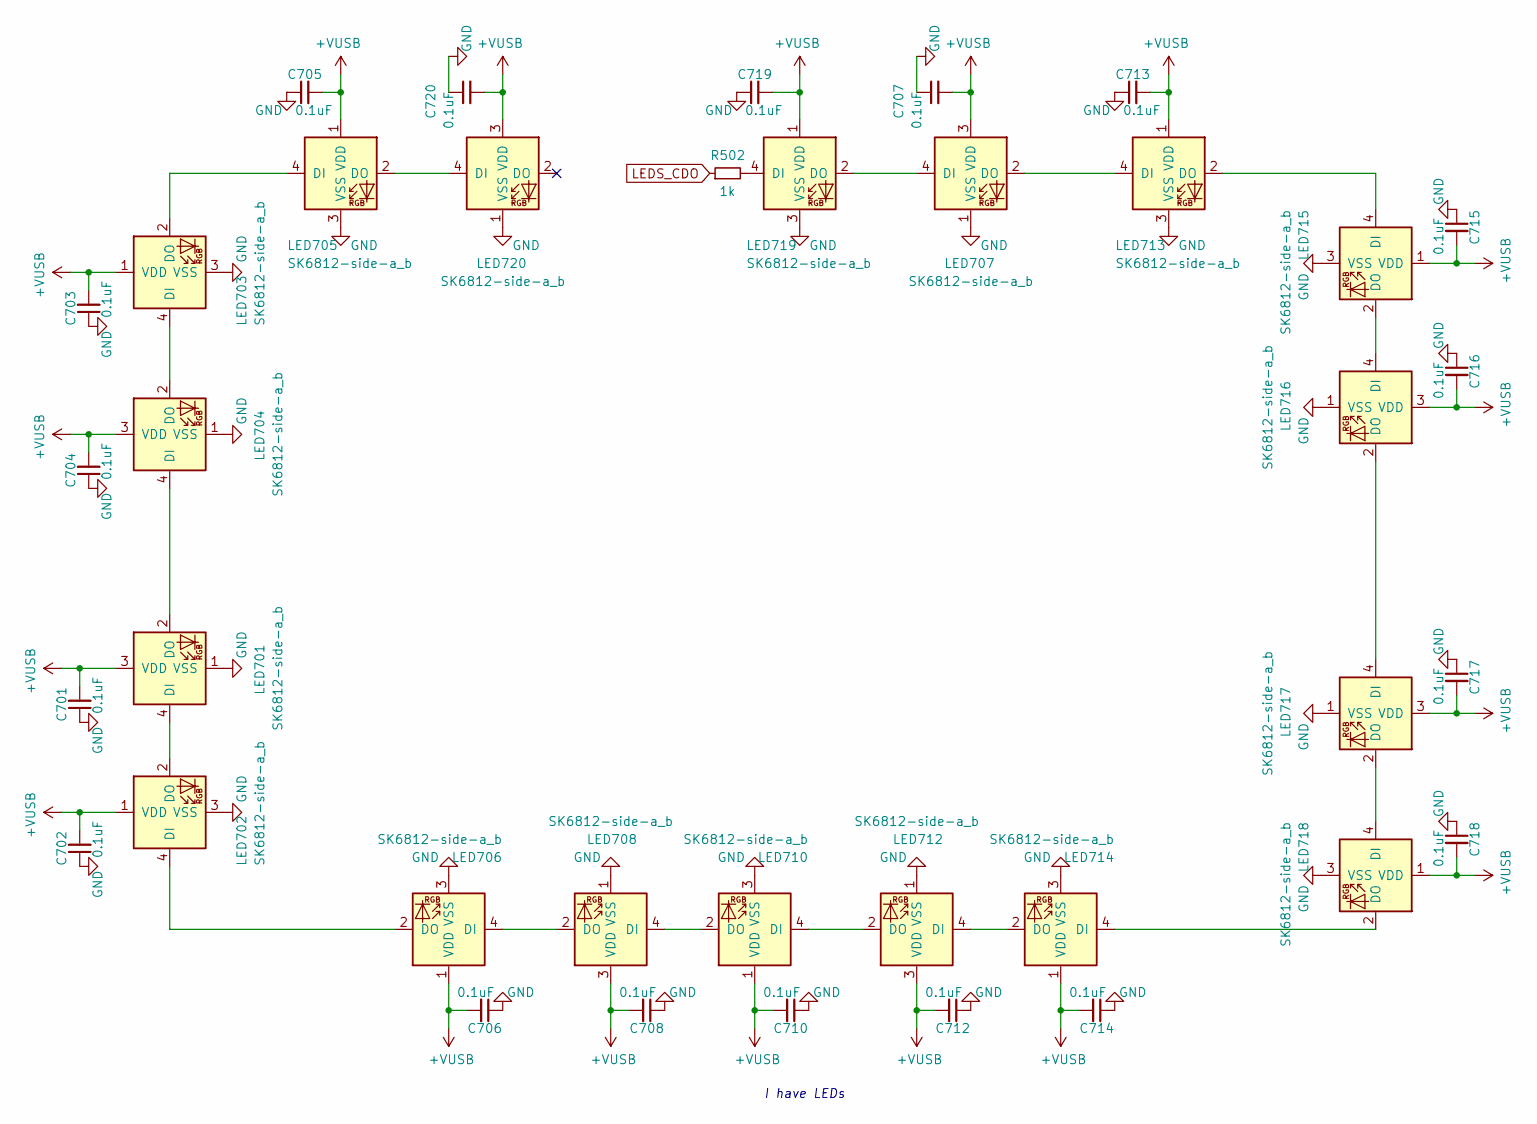
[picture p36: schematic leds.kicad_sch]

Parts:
C701, C702, C703, C704, C705, C706, C707, C708, C710, C712, C713, C714, C715, C716, C717, C718, C719, C720: 0.1uF; C_0402_1005Metric
LED701, LED702, LED703, LED704, LED705, LED706, LED707, LED708, LED710, LED712, LED713, LED714, LED715, LED716, LED717, LED718, LED719, LED720: SK6812-side-a_b
R502: 1k; R_0402_1005Metric

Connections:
+VUSB: C701.2, C702.2, C703.2, C704.2, C705.2, C706.2, C707.2, C708.2, C710.2, C712.2, C713.2, C714.2, C715.2, C716.2, C717.2, C718.2, C719.2, C720.2, LED701.3 (VDD), LED702.1 (VDD), LED703.1 (VDD), LED704.3 (VDD), LED705.1 (VDD), LED706.1 (VDD), LED707.3 (VDD), LED708.3 (VDD), LED710.1 (VDD), LED712.3 (VDD), LED713.1 (VDD), LED714.1 (VDD), LED715.1 (VDD), LED716.3 (VDD), LED717.3 (VDD), LED718.1 (VDD), LED719.1 (VDD), LED720.3 (VDD); also elsewhere on the board
GND: C701.1, C702.1, C703.1, C704.1, C705.1, C706.1, C707.1, C708.1, C710.1, C712.1, C713.1, C714.1, C715.1, C716.1, C717.1, C718.1, C719.1, C720.1, LED701.1 (VSS), LED702.3 (VSS), LED703.3 (VSS), LED704.1 (VSS), LED705.3 (VSS), LED706.3 (VSS), LED707.1 (VSS), LED708.1 (VSS), LED710.3 (VSS), LED712.1 (VSS), LED713.3 (VSS), LED714.3 (VSS), LED715.3 (VSS), LED716.1 (VSS), LED717.1 (VSS), LED718.3 (VSS), LED719.3 (VSS), LED720.1 (VSS); also elsewhere on the board
LEDS_CDO: R502.1; also elsewhere on the board
unnamed: LED701.4 (DI), LED702.2 (DO)
unnamed: LED701.2 (DO), LED704.4 (DI)
unnamed: LED702.4 (DI), LED706.2 (DO)
unnamed: LED703.4 (DI), LED704.2 (DO)
unnamed: LED703.2 (DO), LED705.4 (DI)
unnamed: LED705.2 (DO), LED720.4 (DI)
unnamed: LED706.4 (DI), LED708.2 (DO)
unnamed: LED707.4 (DI), LED719.2 (DO)
unnamed: LED707.2 (DO), LED713.4 (DI)
unnamed: LED708.4 (DI), LED710.2 (DO)
unnamed: LED710.4 (DI), LED712.2 (DO)
unnamed: LED712.4 (DI), LED714.2 (DO)
unnamed: LED713.2 (DO), LED715.4 (DI)
unnamed: LED714.4 (DI), LED718.2 (DO)
unnamed: LED715.2 (DO), LED716.4 (DI)
unnamed: LED716.2 (DO), LED717.4 (DI)
unnamed: LED717.2 (DO), LED718.4 (DI)
unnamed: LED719.4 (DI), R502.2

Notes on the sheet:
I have LEDs

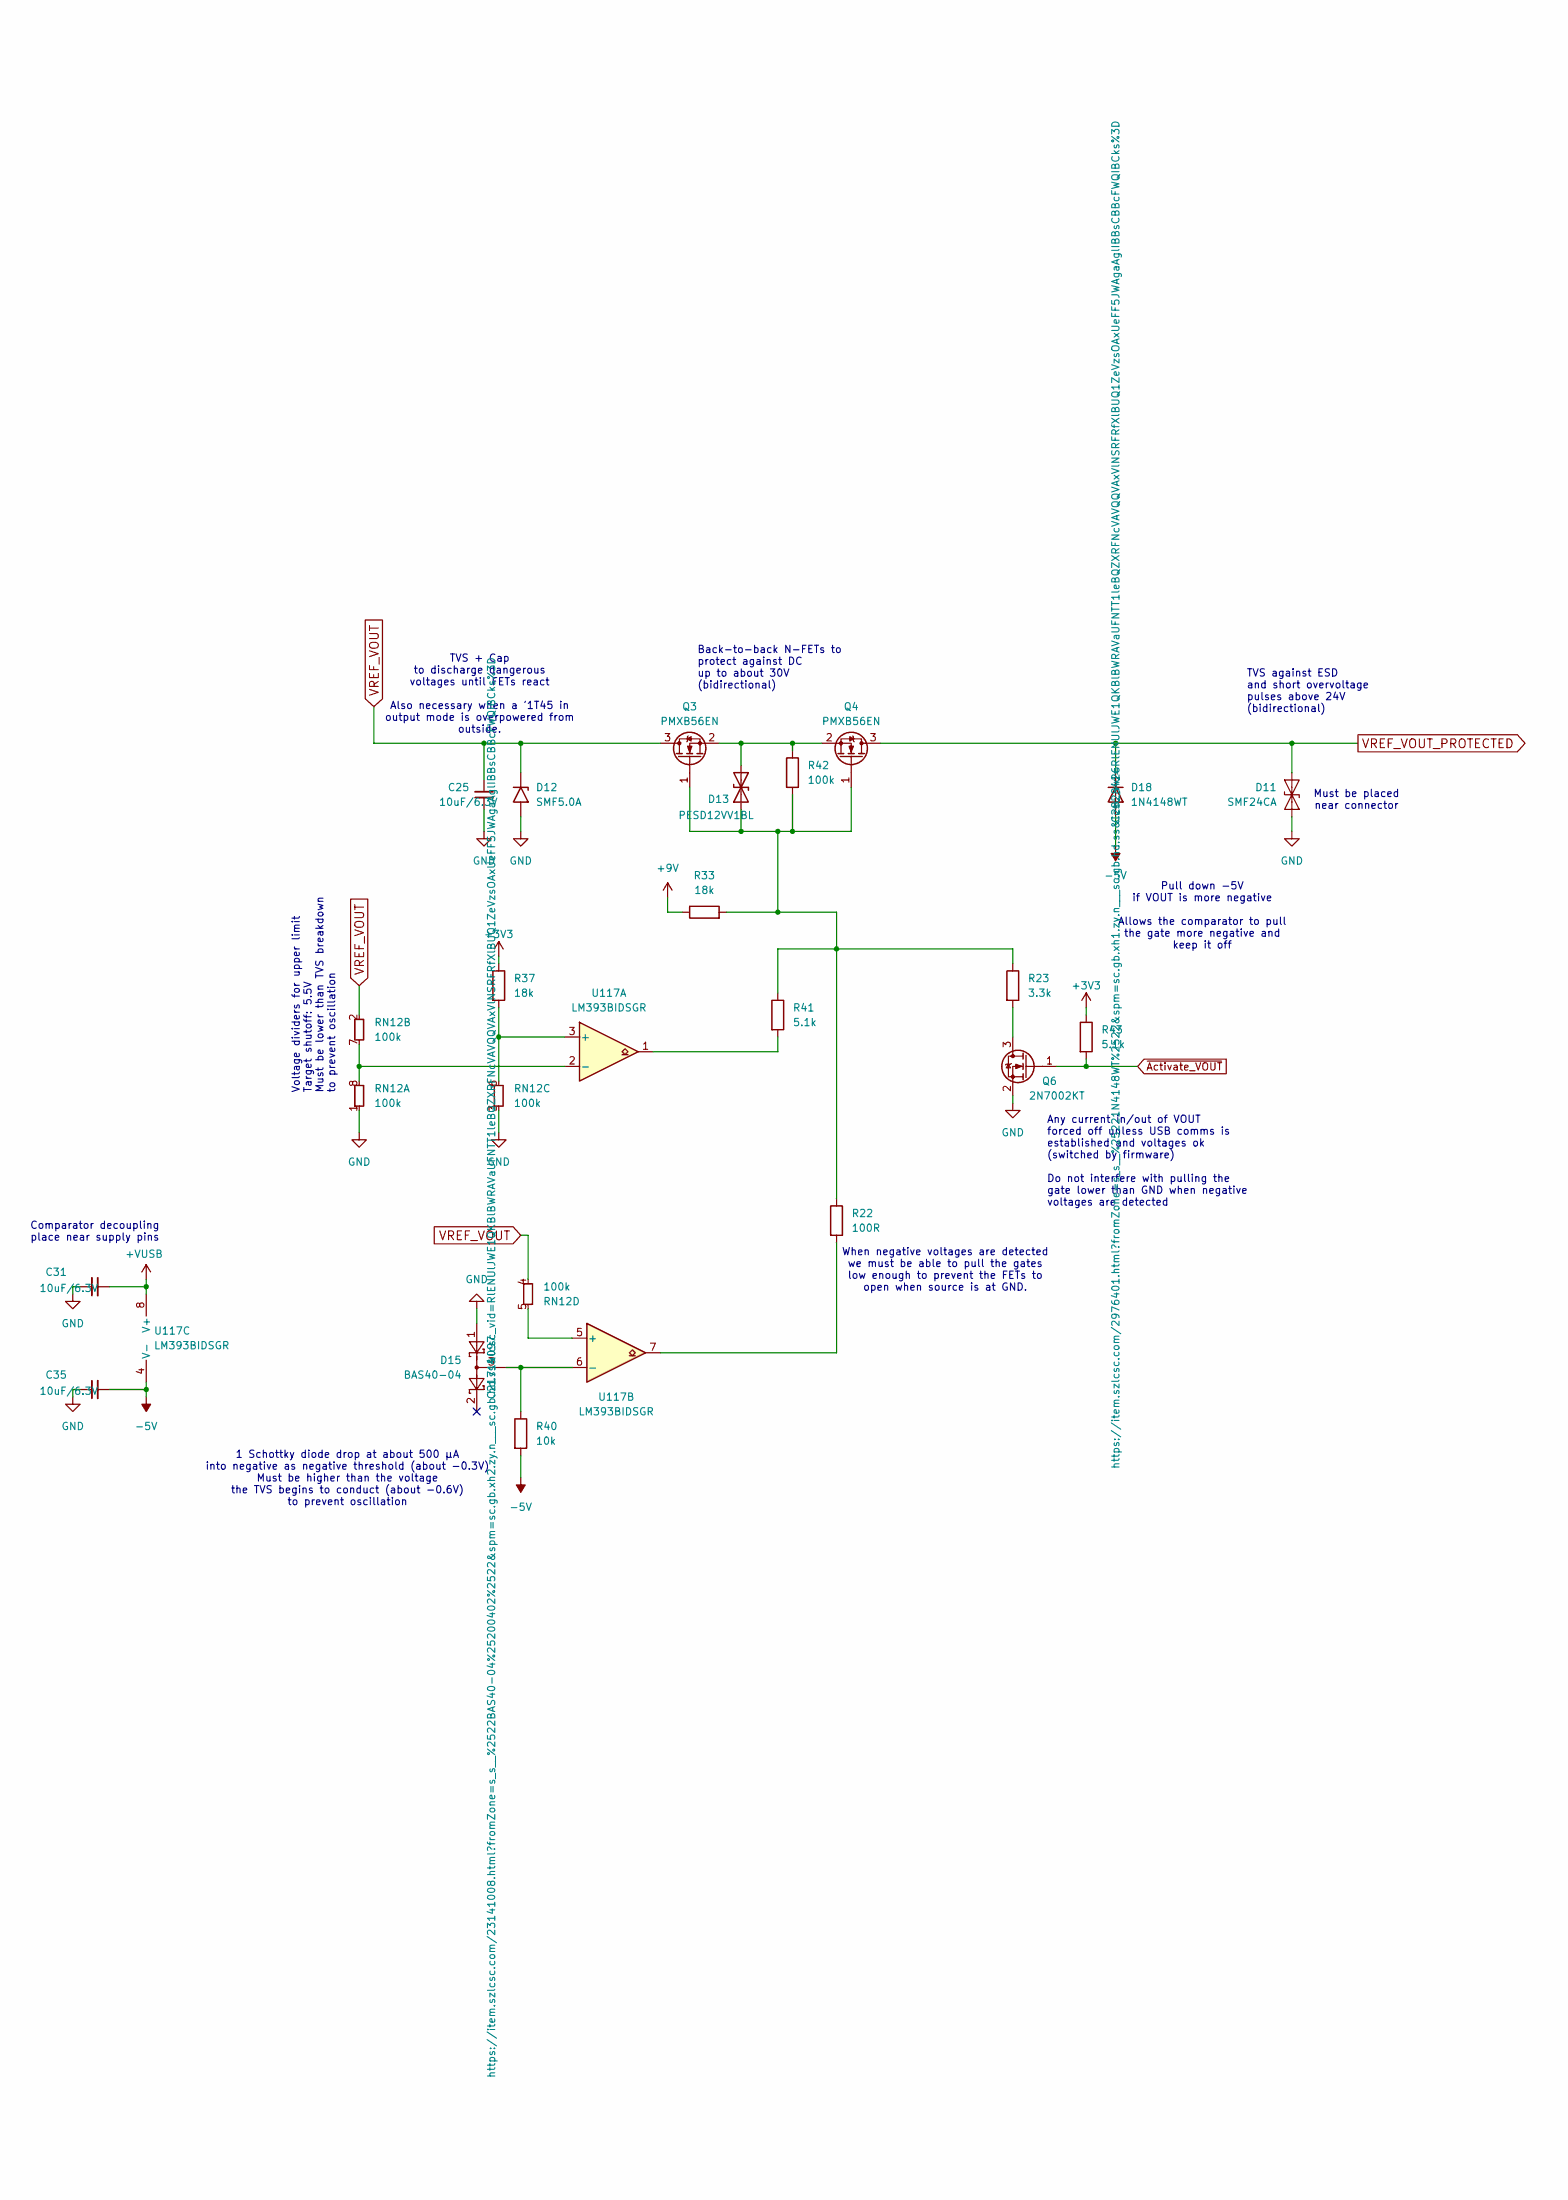
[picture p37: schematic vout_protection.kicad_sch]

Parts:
C25, C31, C35: 10uF/6.3V; C_0402_1005Metric
D11: SMF24CA; D_SMF
D12: SMF5.0A; D_SMF
D13: PESD12VV1BL; D_SOD-882D
D15: BAS40-04; SOT-523
D18: 1N4148WT; D_SOD-523
Q3, Q4: PMXB56EN; DFN1010D-3_SOT1215_NEX
Q6: 2N7002KT; SOT-523
R22: 100R; R_0402_1005Metric
R23: 3.3k; R_0402_1005Metric
R33, R37: 18k; R_0402_1005Metric
R40: 10k; R_0402_1005Metric
R41, R43: 5.1k; R_0402_1005Metric
R42: 100k; R_0402_1005Metric
RN12: 100k; R_Array_Convex_4x0402
U117: LM393BIDSGR; WSON-8-1EP_2x2mm_P0.5mm_EP0.9x1.6mm

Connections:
+3V3: R37.1, R43.1; also elsewhere on the board
+9V: R33.1; also elsewhere on the board
+VUSB: C31.2, U117.8 (V+); also elsewhere on the board
-5V: C35.2, D18.2 (A), R40.2, U117.4 (V-); also elsewhere on the board
GND: C25.1, C31.1, C35.1, D11.1 (A1), D12.2 (A2), D15.1, Q6.2 (S), RN12.1 (R1.1), RN12.3 (R1.1); also elsewhere on the board
unnamed: D13.1 (A1), Q3.1 (G), Q4.1 (G), R22.1, R23.1, R33.2, R41.1, R42.2
unnamed: D13.2 (A2), Q3.2 (S), Q4.2 (S), R42.1
unnamed: Q6.3 (D), R23.2
unnamed: R22.2, U117.7
unnamed: R41.2, U117.1
unnamed: RN12.7 (R1.8), RN12.8 (R1.8), U117.2 (-)
unnamed: R37.2, RN12.6 (R1.8), U117.3 (+)
unnamed: RN12.5 (R1.8), U117.5 (+)
unnamed: D15.3, R40.1, U117.6 (-)
VREF_VOUT: C25.2, D12.1 (A1), Q3.3 (D), RN12.2 (R1.1), RN12.4 (R1.1); also elsewhere on the board
VREF_VOUT_PROTECTED: D11.2 (A2), D18.1 (K), Q4.3 (D); also elsewhere on the board
~Activate_VOUT: Q6.1 (G), R43.2; also elsewhere on the board

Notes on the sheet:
When negative voltages are detected we must be able to pull the gates low enough to prevent the FETs to open when source is at GND.
TVS against ESD and short overvoltage pulses above 24V (bidirectional)
TVS + Cap to discharge dangerous voltages until FETs react Also necessary when a '1T45 in output mode is overpowered from outside.
Back-to-back N-FETs to protect against DC up to about 30V (bidirectional)
Pull down -5V if VOUT is more negative Allows the comparator to pull the gate more negative and keep it off
1 Schottky diode drop at about 500 µA into negative as negative threshold (about -0.3V) Must be higher than the voltage the TVS begins to conduct (about -0.6V) to prevent oscillation
Comparator decoupling place near supply pins
Voltage dividers for upper limit Target shutoff: 5.5V Must be lower than TVS breakdown to prevent oscillation
Any current in/out of VOUT forced off unless USB comms is established and voltages ok (switched by firmware) Do not interfere with pulling the gate lower than GND when negative voltages are detected
Must be placed near connector

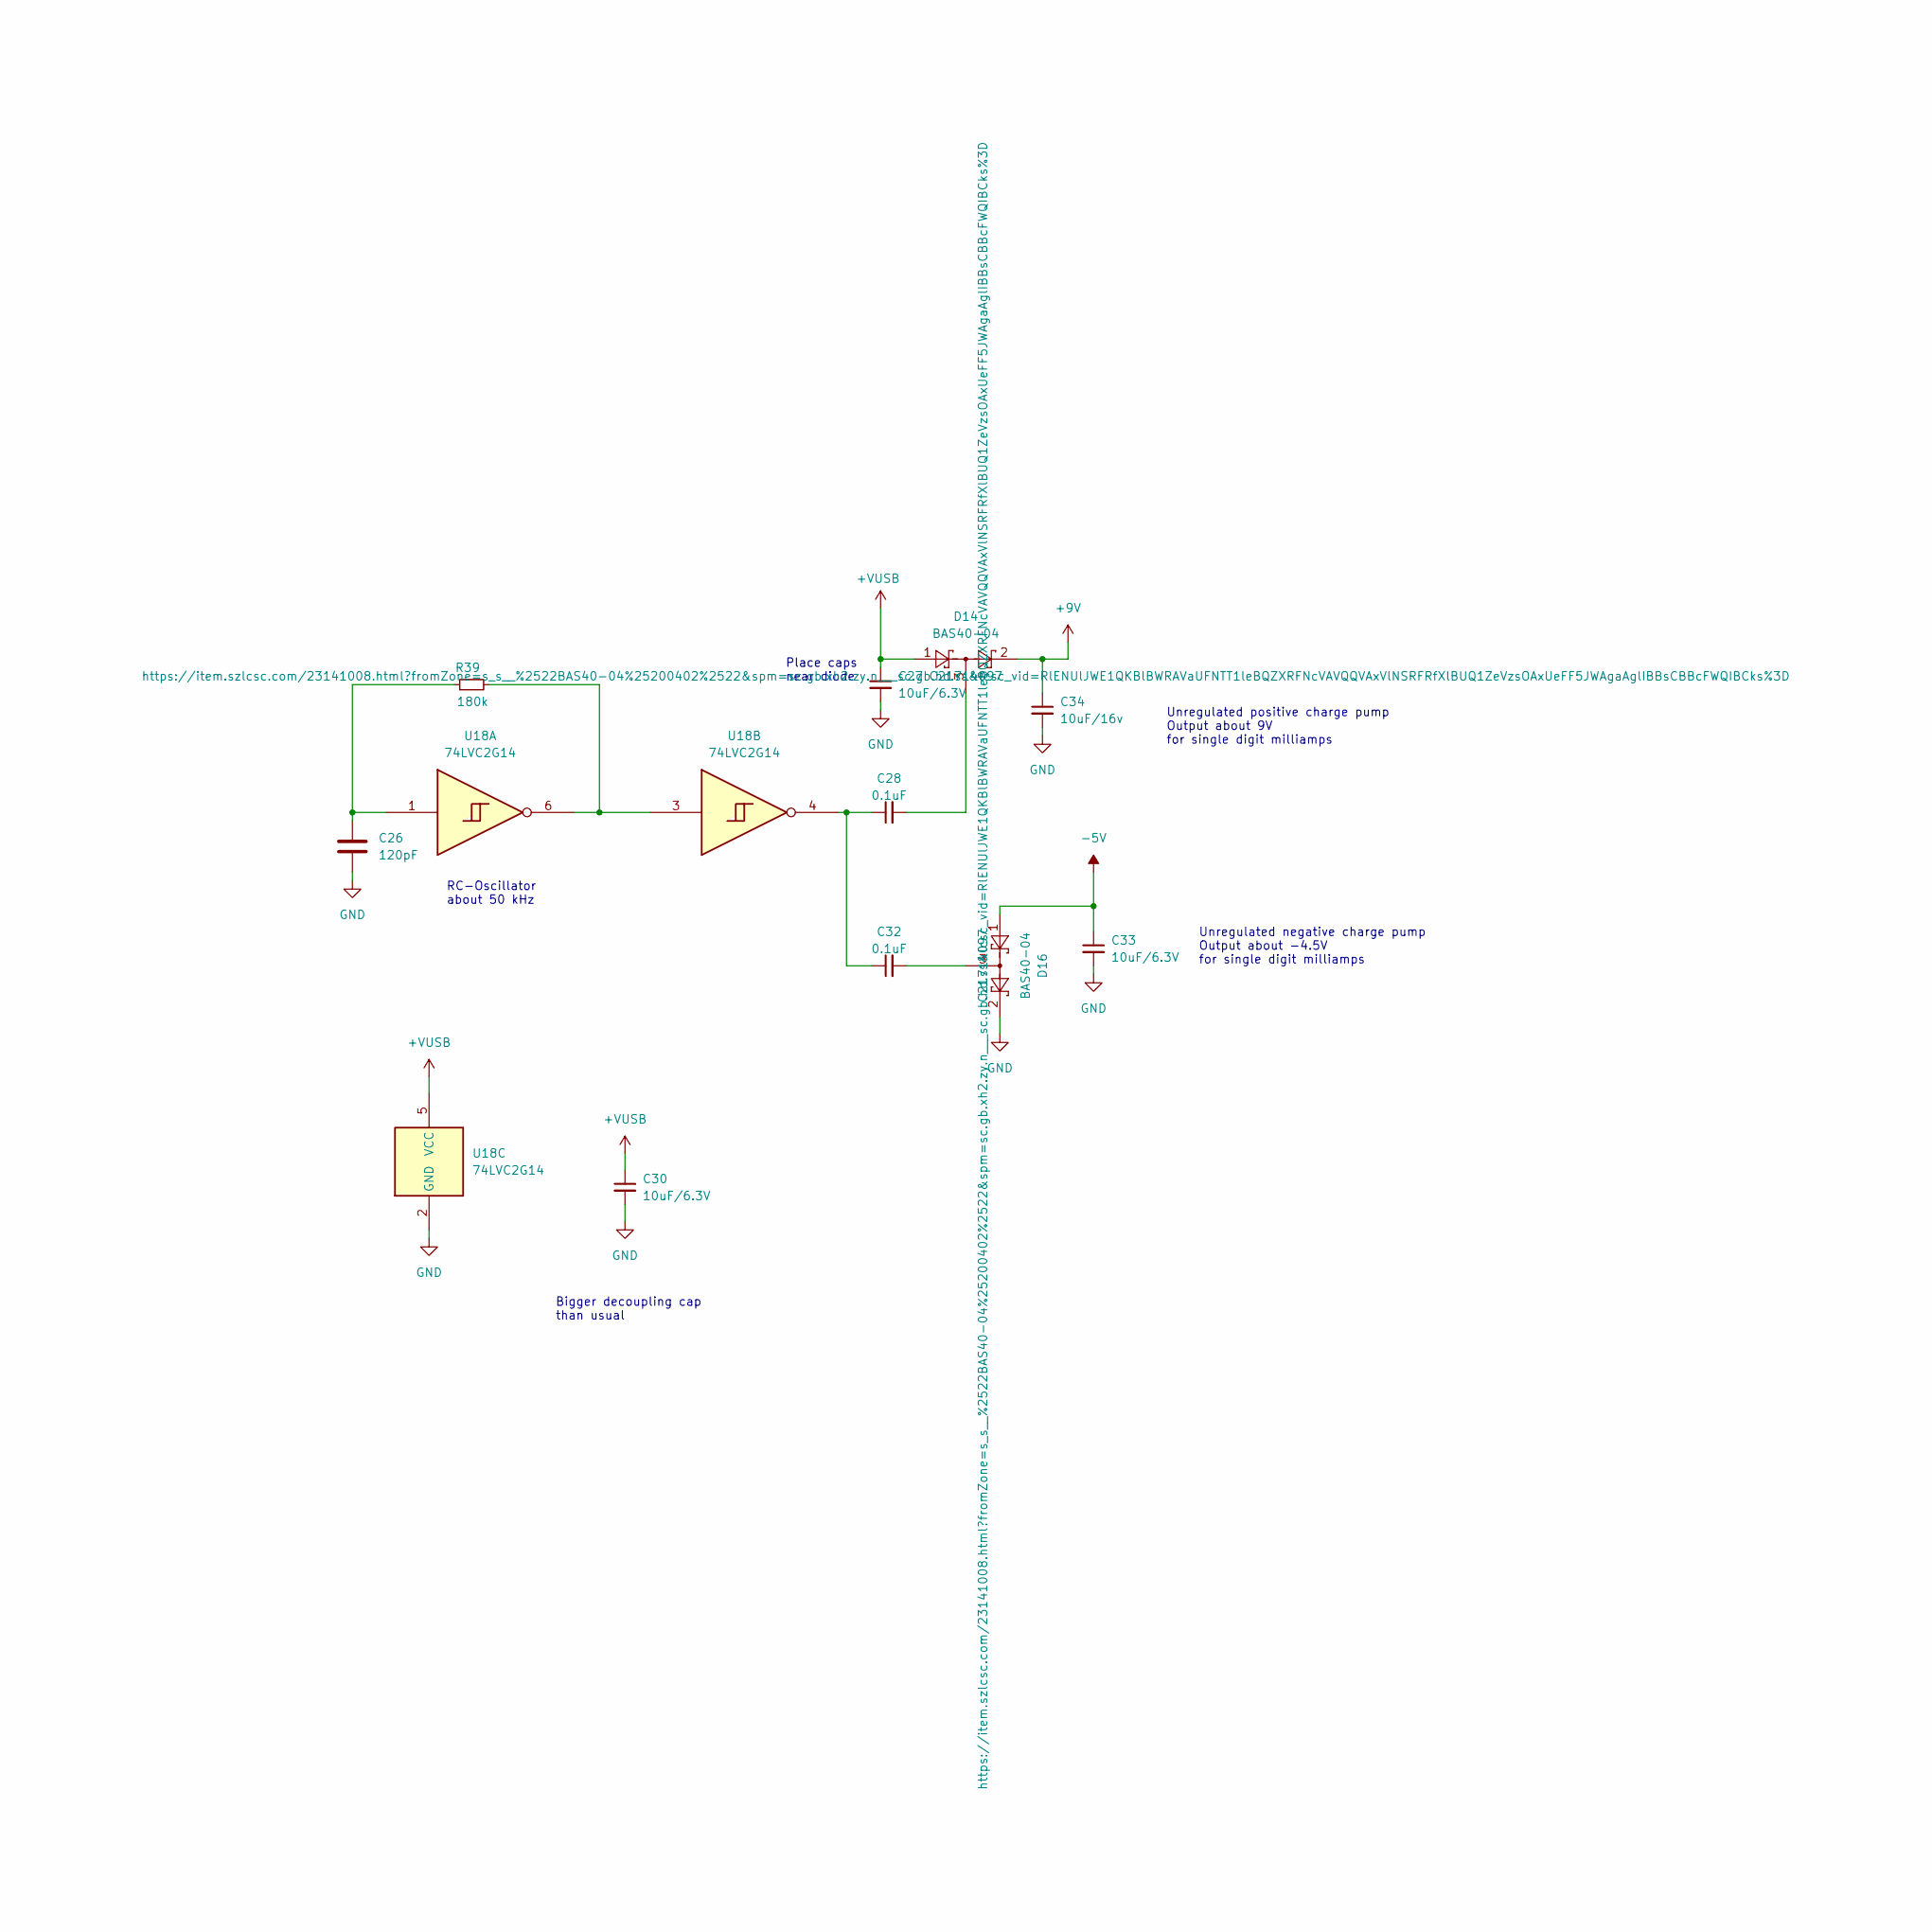
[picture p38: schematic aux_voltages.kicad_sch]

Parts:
C26: 120pF; C_0402_1005Metric
C27, C30, C33: 10uF/6.3V; C_0402_1005Metric
C28, C32: 0.1uF; C_0402_1005Metric
C34: 10uF/16v; C_0805_2012Metric
D14, D16: BAS40-04; SOT-523
R39: 180k; R_0402_1005Metric
U18: 74LVC2G14; SOT-363_SC-70-6

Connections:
+9V: C34.1, D14.2; also elsewhere on the board
+VUSB: C27.1, C30.1, D14.1, U18.5 (VCC); also elsewhere on the board
-5V: C33.1, D16.1; also elsewhere on the board
GND: C26.2, C27.2, C30.2, C33.2, C34.2, D16.2, U18.2 (GND); also elsewhere on the board
unnamed: C26.1, R39.1, U18.1
unnamed: C28.1, C32.1, U18.4
unnamed: C28.2, D14.3
unnamed: C32.2, D16.3
unnamed: R39.2, U18.3, U18.6

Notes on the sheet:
Bigger decoupling cap than usual
Place caps near diode
Unregulated positive charge pump Output about 9V for single digit milliamps
Unregulated negative charge pump Output about -4.5V for single digit milliamps
RC-Oscillator about 50 kHz

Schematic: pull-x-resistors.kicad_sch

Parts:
C14, C15, C16, C17: 0.1uF; C_0402_1005Metric
RN2, RN8: 100k; R_Array_Convex_4x0402
RN3, RN9: 10k; R_Array_Convex_4x0402
RN4, RN7: 4.7k; R_Array_Convex_4x0402
RN5, RN6: 2.2k; R_Array_Convex_4x0402
U6, U7: TCA6416ARTWR; QFN-24-1EP_4x4mm_P0.5mm_EP2.75x2.75mm

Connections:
+3V3: C15.2, C17.2, U6.23 (VCCI), U7.18 (ADDR), U7.23 (VCCI); also elsewhere on the board
BPIO0_TVS: RN6.4 (R1.1), RN7.4 (R1.1), RN8.8 (R1.8), RN9.8 (R1.8); also elsewhere on the board
BPIO1_TVS: RN6.3 (R1.1), RN7.3 (R1.1), RN8.7 (R1.8), RN9.7 (R1.8); also elsewhere on the board
BPIO2_TVS: RN6.2 (R1.1), RN7.2 (R1.1), RN8.6 (R1.8), RN9.6 (R1.8); also elsewhere on the board
BPIO3_TVS: RN6.1 (R1.1), RN7.1 (R1.1), RN8.5 (R1.8), RN9.5 (R1.8); also elsewhere on the board
BPIO4_TVS: RN2.8 (R1.8), RN3.8 (R1.8), RN4.4 (R1.1), RN5.4 (R1.1); also elsewhere on the board
BPIO5_TVS: RN2.7 (R1.8), RN3.7 (R1.8), RN4.3 (R1.1), RN5.3 (R1.1); also elsewhere on the board
BPIO6_TVS: RN2.6 (R1.8), RN3.6 (R1.8), RN4.2 (R1.1), RN5.2 (R1.1); also elsewhere on the board
BPIO7_TVS: RN2.5 (R1.8), RN3.5 (R1.8), RN4.1 (R1.1), RN5.1 (R1.1); also elsewhere on the board
GND: C14.1, C15.1, C16.1, C17.1, U6.9 (GND), U6.18 (ADDR), U6.25 (EP), U7.9 (GND), U7.25 (EP); also elsewhere on the board
I2C_RESET: U6.24 (~RESET), U7.24 (~RESET); also elsewhere on the board
I2C_SCL: U6.19 (SCL), U7.19 (SCL); also elsewhere on the board
I2C_SDA: U6.20 (SDA), U7.20 (SDA); also elsewhere on the board
unnamed: RN2.1 (R1.1), U6.13
unnamed: RN2.2 (R1.1), U6.12
unnamed: RN2.3 (R1.1), U6.11
unnamed: RN2.4 (R1.1), U6.10
unnamed: RN3.1 (R1.1), U6.17
unnamed: RN3.2 (R1.1), U6.16
unnamed: RN3.3 (R1.1), U6.15
unnamed: RN3.4 (R1.1), U6.14
unnamed: RN4.8 (R1.8), U6.5 (P04)
unnamed: RN4.7 (R1.8), U6.6 (P05)
unnamed: RN4.6 (R1.8), U6.7 (P06)
unnamed: RN4.5 (R1.8), U6.8 (P07)
unnamed: RN5.8 (R1.8), U6.1 (P00)
unnamed: RN5.7 (R1.8), U6.2 (P01)
unnamed: RN5.6 (R1.8), U6.3 (P02)
unnamed: RN5.5 (R1.8), U6.4 (P03)
unnamed: RN6.8 (R1.8), U7.1 (P00)
unnamed: RN6.7 (R1.8), U7.2 (P01)
unnamed: RN6.6 (R1.8), U7.3 (P02)
unnamed: RN6.5 (R1.8), U7.4 (P03)
unnamed: RN7.8 (R1.8), U7.5 (P04)
unnamed: RN7.7 (R1.8), U7.6 (P05)
unnamed: RN7.6 (R1.8), U7.7 (P06)
unnamed: RN7.5 (R1.8), U7.8 (P07)
unnamed: RN8.1 (R1.1), U7.13
unnamed: RN8.2 (R1.1), U7.12
unnamed: RN8.3 (R1.1), U7.11
unnamed: RN8.4 (R1.1), U7.10
unnamed: RN9.1 (R1.1), U7.17
unnamed: RN9.2 (R1.1), U7.16
unnamed: RN9.3 (R1.1), U7.15
unnamed: RN9.4 (R1.1), U7.14
VREF_VOUT: C14.2, C16.2, U6.21 (VCCP), U7.21 (VCCP); also elsewhere on the board

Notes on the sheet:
7-bit I2C Address: 0b0100000 (0x20) 8-bit Write Address: 0b01000000 (0x40) 8-bit Read Address: 0b01000001 (0x41)
7-bit I2C Address: 0b0100001 (0x21) 8-bit Write Address: 0b01000010 (0x42) 8-bit Read Address: 0b01000011 (0x43)

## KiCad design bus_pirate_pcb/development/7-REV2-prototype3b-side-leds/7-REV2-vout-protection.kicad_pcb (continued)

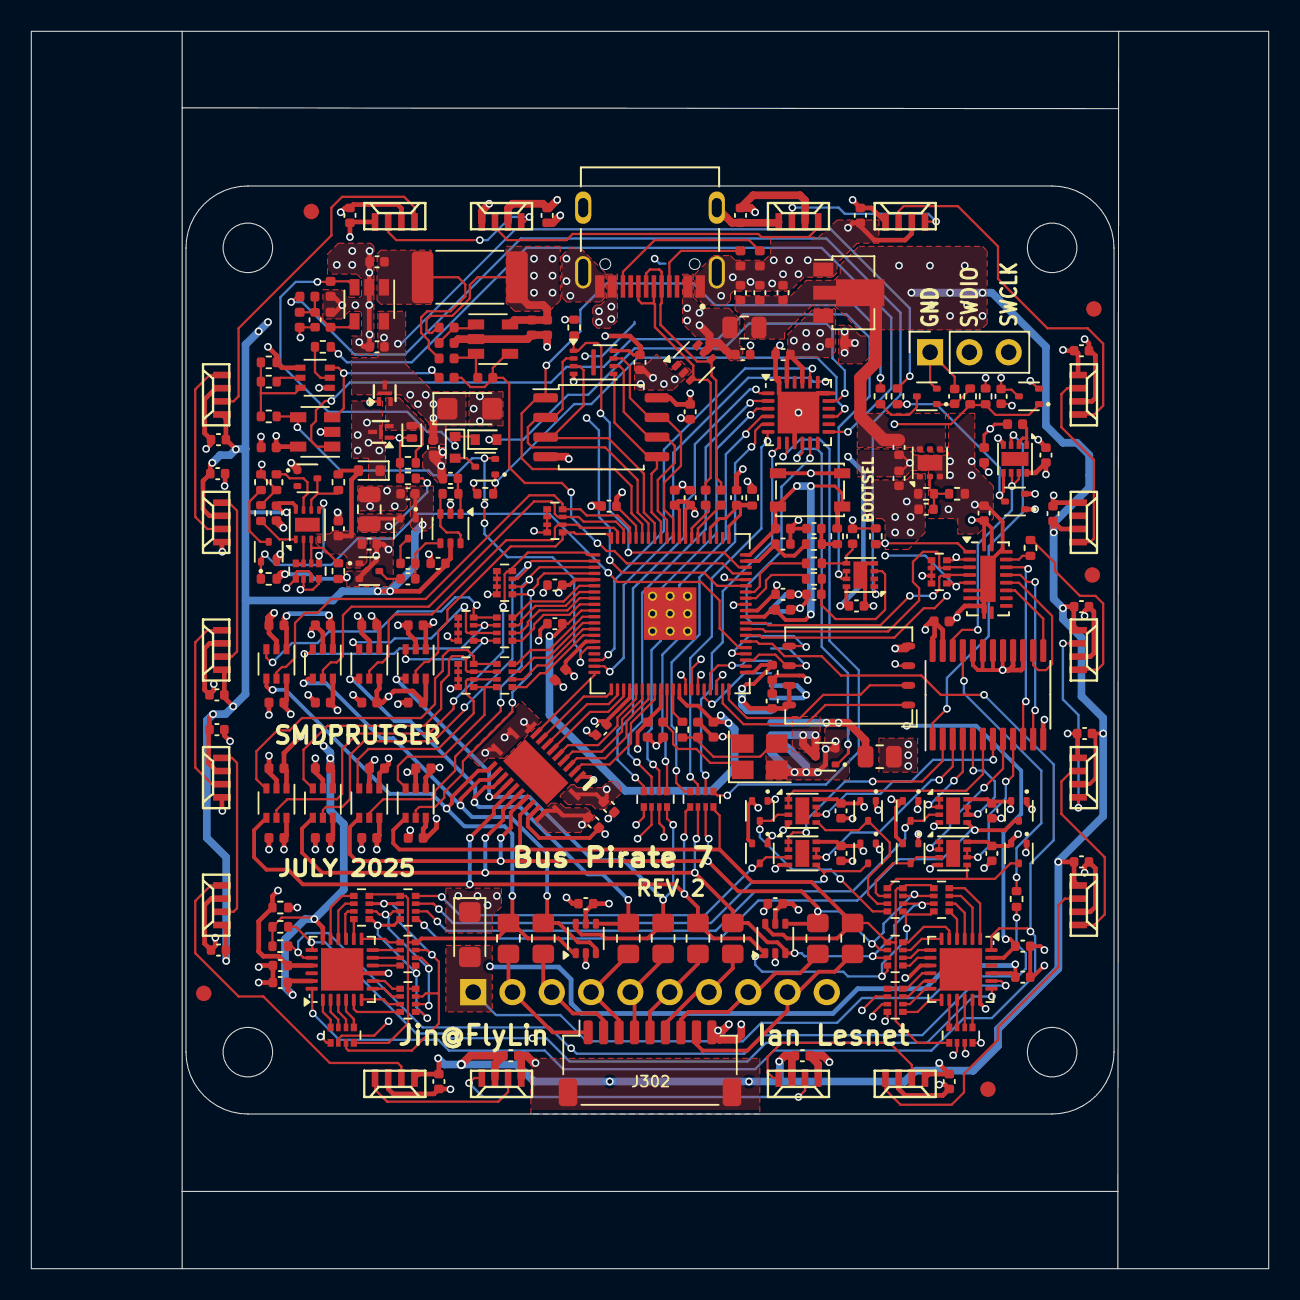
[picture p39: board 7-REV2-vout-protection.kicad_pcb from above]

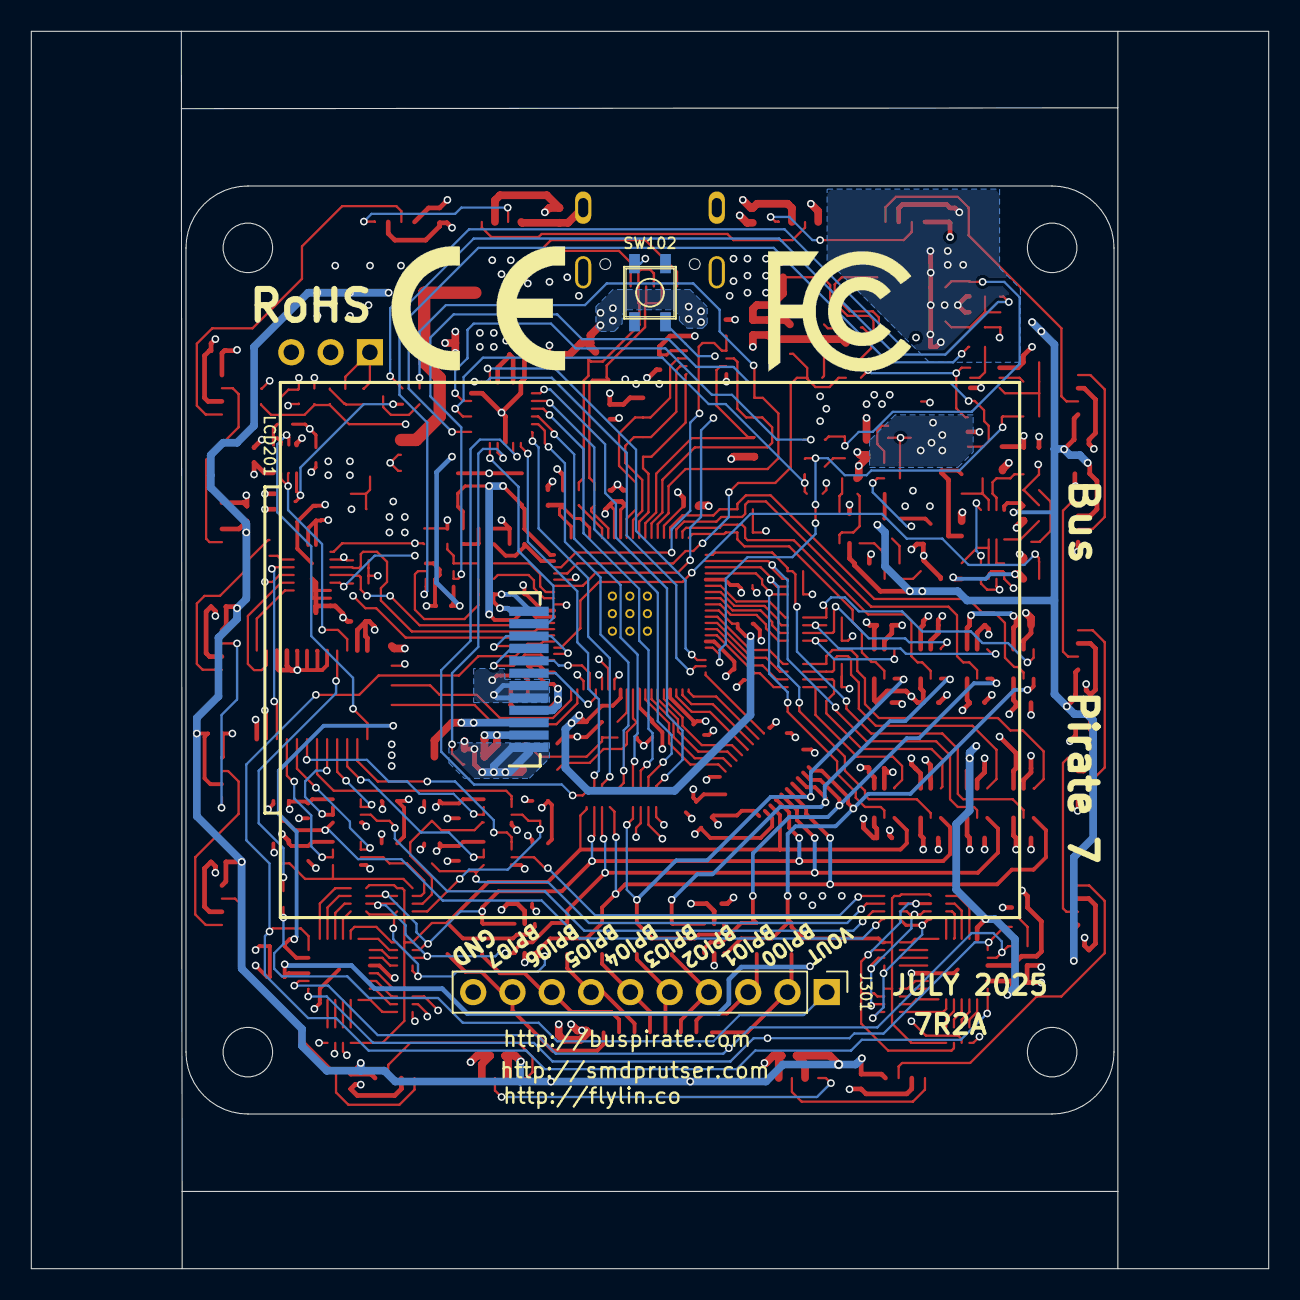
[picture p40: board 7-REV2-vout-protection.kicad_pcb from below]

Board: 4 copper layers, 80.0 x 80.0 mm, 276 parts (5 on the bottom side), 223 nets.

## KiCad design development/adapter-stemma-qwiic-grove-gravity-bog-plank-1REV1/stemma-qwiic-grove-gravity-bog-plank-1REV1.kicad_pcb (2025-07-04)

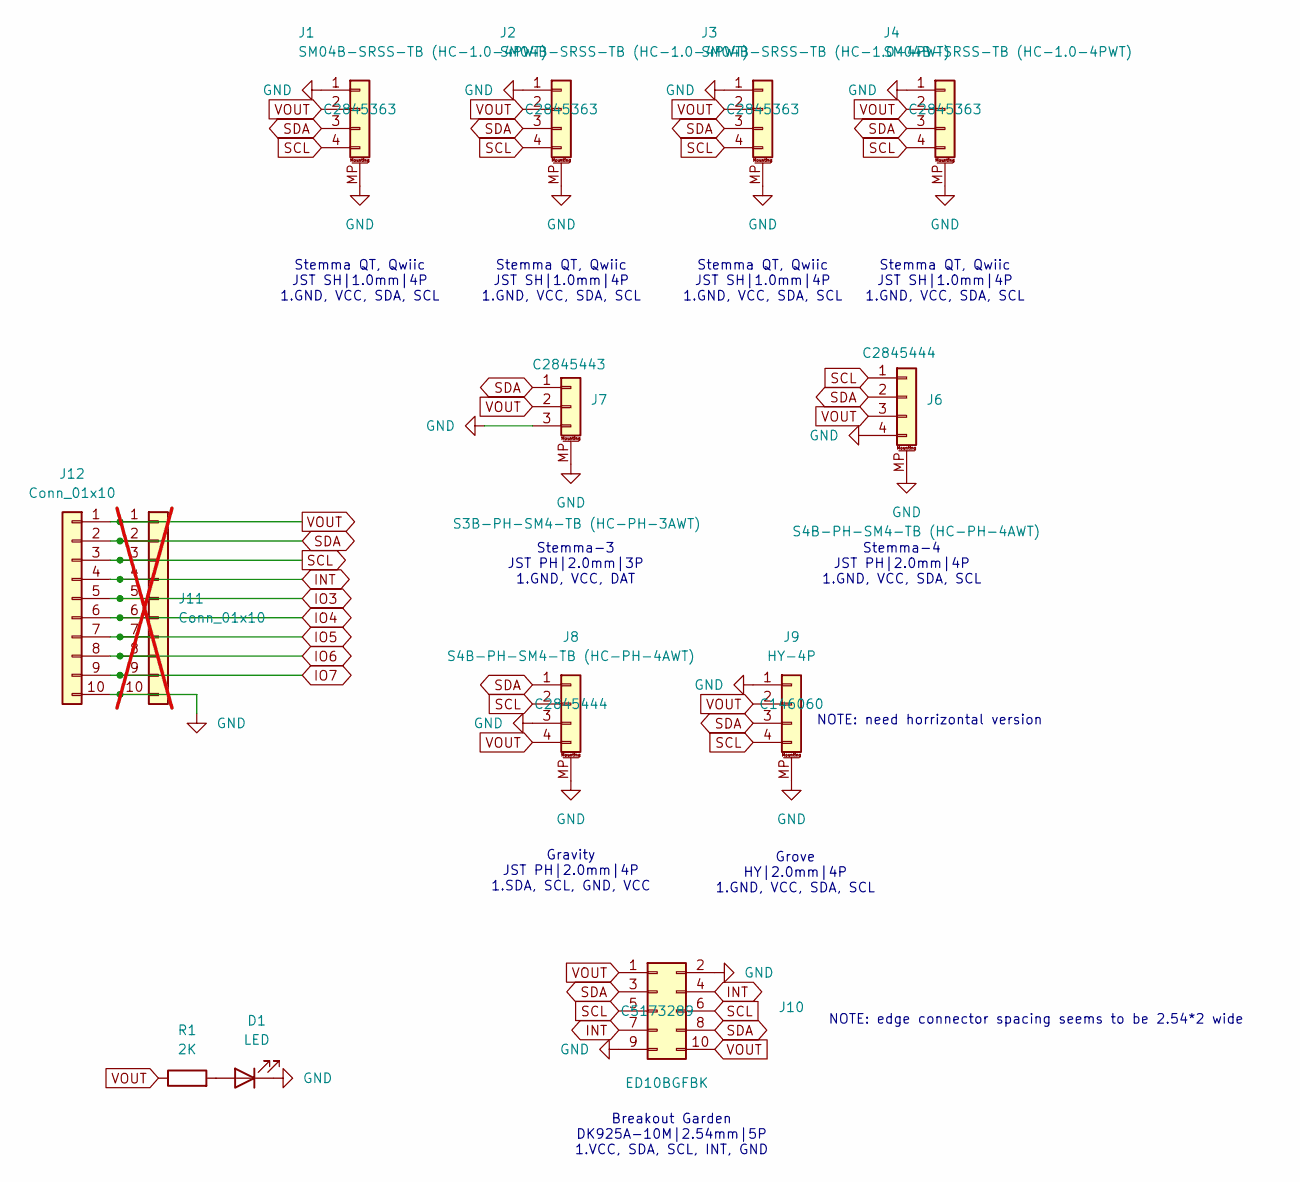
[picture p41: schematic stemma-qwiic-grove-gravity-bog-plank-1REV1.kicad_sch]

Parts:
D1: LED; LED_0805_2012Metric
J1, J2, J3, J4: SM04B-SRSS-TB (HC-1.0-4PWT); JST_SH_SM04B-SRSS-TB_1x04-1MP_P1.00mm_Horizontal
J6, J8: S4B-PH-SM4-TB (HC-PH-4AWT); JST_PH_S4B-PH-SM4-TB_1x04-1MP_P2.00mm_Horizontal
J7: S3B-PH-SM4-TB (HC-PH-3AWT); JST_PH_S3B-PH-SM4-TB_1x03-1MP_P2.00mm_Horizontal
J9: HY-4P; CONN-SMD_HY2.0-4P
J10: ED10BGFBK; CONN-TH_SA10BL01D
J11: Conn_01x10; PinHeader_1x10_P2.54mm_Vertical; not fitted
J12: Conn_01x10; PinSocket_1x10_P2.54mm_Horizontal
R1: 2K; R_0805_2012Metric

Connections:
GND: D1.1 (K), J1.1, J1.MP (MountPin), J2.1, J2.MP (MountPin), J3.1, J3.MP (MountPin), J4.1, J4.MP (MountPin), J6.4, J6.MP (MountPin), J7.3, J7.MP (MountPin), J8.3, J8.MP (MountPin), J9.1, J9.MP (MountPin), J10.2, J10.9, J11.10, J12.10
INT: J10.4, J10.7, J11.4, J12.4
IO3: J11.5, J12.5
IO4: J11.6, J12.6
IO5: J11.7, J12.7
IO6: J11.8, J12.8
IO7: J11.9, J12.9
unnamed: D1.2 (A), R1.2
SCL: J1.4, J2.4, J3.4, J4.4, J6.1, J8.2, J9.4, J10.5, J10.6, J11.3, J12.3
SDA: J1.3, J2.3, J3.3, J4.3, J6.2, J7.1, J8.1, J9.3, J10.3, J10.8, J11.2, J12.2
VOUT: J1.2, J2.2, J3.2, J4.2, J6.3, J7.2, J8.4, J9.2, J10.1, J10.10, J11.1, J12.1, R1.1

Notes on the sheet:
Gravity JST PH|2.0mm|4P 1.SDA, SCL, GND, VCC
Stemma QT, Qwiic JST SH|1.0mm|4P 1.GND, VCC, SDA, SCL
Stemma-4 JST PH|2.0mm|4P 1.GND, VCC, SDA, SCL
Stemma-3 JST PH|2.0mm|3P 1.GND, VCC, DAT
NOTE: edge connector spacing seems to be 2.54*2 wide
NOTE: need horrizontal version
Grove HY|2.0mm|4P 1.GND, VCC, SDA, SCL
Breakout Garden DK925A-10M|2.54mm|5P 1.VCC, SDA, SCL, INT, GND

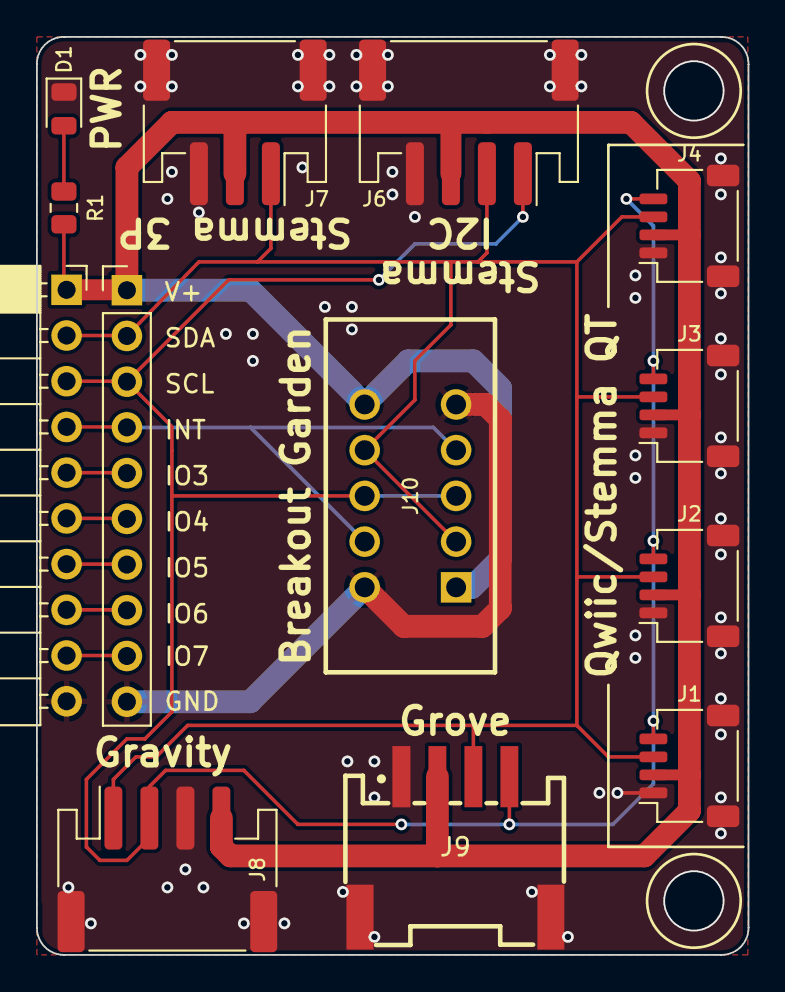
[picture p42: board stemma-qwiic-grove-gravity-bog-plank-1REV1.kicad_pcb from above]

Board: 2 copper layers, 39.5 x 51.0 mm, 13 parts (0 on the bottom side), 11 nets.

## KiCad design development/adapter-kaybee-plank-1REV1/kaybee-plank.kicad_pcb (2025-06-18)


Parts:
C1, C2, C3: 47uF/CL21A226MAYNNNE; C_0805_2012Metric
D2: LED; LED_0805_2012Metric
D401: 1N4148WT; D_SOD-523
J1, J4: Mini-DIN-6; Connector_Mini-DIN_Female_6Pin_2rows
J2: Conn_01x10; PinSocket_1x10_P2.54mm_Horizontal
J3: Conn_01x10; PinHeader_1x10_P2.54mm_Vertical; not fitted
J5: USB_A; USB_A_CONNFLY_DS1095-WNR0
J7: TYPE-C-31-M-12; HRO_TYPE-C-31-M-12
J8, J9: Conn_01x02_Pin; PinHeader_1x02_P2.54mm_Vertical
L1, L2, L4, L5: CBW201209U300T; L_0805_2012Metric
Q401: BCM857BS-7-F; SOT-363_SC-70-6
Q402: BC2301T 2.8A; SOT-523
R1, R5: 5.1K; R_0805_2012Metric
R2, R3: 2K; R_0805_2012Metric
R408: 68K; R_0805_2012Metric
R410: 10K; R_0805_2012Metric
R412: 100K; R_0805_2012Metric
SW1: SW_SPDT; SW_SPDT_PCM12

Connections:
CLK: J1.5, J2.7, J3.7, J4.5
DAT: J1.1, J2.6, J3.6, J4.1
GND: C1.2, C2.2, C3.2, D2.1 (K), J1.3, J2.10, J3.10, J4.3, J5.4 (GND), J5.5 (Shield), J7.A1B12 (GND), J7.B1A12 (GND), J7.S1 (SHIELD), J7.S2 (SHIELD), J7.S3 (SHIELD), J7.S4 (SHIELD), J8.2, J9.2, R1.1, R5.1, R408.2, R412.2
IO3: J2.5, J3.5
IO6: J2.8, J3.8
IO7: J2.9, J3.9
unnamed: D2.2 (A), R2.2
unnamed: D401.2 (A), Q401.3 (C2), Q401.5 (B2), R408.1, R410.2
unnamed: J1.4, L4.1
unnamed: J4.4, L5.1
unnamed: J5.1 (VBUS), L2.2
unnamed: J7.A5 (CC1), R1.2
unnamed: J7.B5 (CC2), R5.2
unnamed: J7.A4B9 (VBUS), J7.B4A9 (VBUS), L1.2
unnamed: Q401.2 (B1), R410.1
unnamed: Q401.6 (C1), Q402.1 (G), R412.1
TRIG: J2.2, J3.2, J8.1, R3.1
USB_D+: J2.3, J3.3, J5.3 (D+), J7.A6 (DP1), J7.B6 (DP2)
USB_D-: J2.4, J3.4, J5.2 (D-), J7.A7 (DN1), J7.B7 (DN2)
VDD: C1.1, C2.1, C3.1, J9.1, L1.1, L2.1, L4.2, L5.2, R2.1, SW1.2 (B)
VOUT: Q401.1 (E1), Q402.2 (S), SW1.1 (A)
VOUT_BP_SIDE: D401.1 (K), J2.1, J3.1, Q401.4 (E2), Q402.3 (D), R3.2

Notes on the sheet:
Q401 is a matched PNP pair with EBCEBC pinout. BCM857, BCM856, NST45010MW6T1G can be substituted. The BCM part numbers are made by several manufacturers. This part may be substituted in Q601, but it costs significantly more. DMMT3906, PMP5201, PMP5501 are similar but have a BBCEEC pinout. These can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
Backflow prevention


Board: 2 copper layers, 39.5 x 51.0 mm, 27 parts (0 on the bottom side), 22 nets.

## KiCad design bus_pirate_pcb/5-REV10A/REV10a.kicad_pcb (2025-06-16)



Board: 4 copper layers, 80.0 x 80.0 mm, 220 parts (4 on the bottom side), 183 nets.

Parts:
C103, C110, C111, C112, C113, C114, C115, C116, C117, C118, C121, C301, C302, C303, C304, C305, C306, C307, C308, C309, C310, C311, C312, C313, C314, C315, C316, C403, C406, C414, C415, C416, C501, C502, C503, C506, C508, C510, C602, C605, C701, C702, C703, C704, C705, C706, C707, C708, C710, C712, C713, C714, C715, C716, C717, C718, C719, C720: 0.1uF; C_0402_1005Metric
C104, C107, C108, C109, C405, C413, C504, C507, C509, C601: 2.2uF; C_0402_1005Metric
C105, C106: 15pF; C_0402_1005Metric
C201, C202, C401, C402, C404, C407: 4.7uF; C_0402_1005Metric
C408: 120pF; C_0402_1005Metric
C603: DNF; C_0402_1005Metric
D401, D601, D602, D603: 1N4148WT; D_SOD-523
D500, D501, D502, D503, D504: BAS40T-05; SOT-523
FID1, FID2, FID3, FID4, FID5: Fiducial; Fiducial_1mm_Mask2mm
H1, H2, H3, H4: MountingHole; MountingHole_3.2mm_M3
J201: Conn_01x03; PinSocket_1x03_P2.54mm_Vertical
J202: TYPE-C-31-M-12; HRO_TYPE-C-31-M-12
J301: Conn_01x10; PinHeader_1x10_P2.54mm_Vertical
J302: Conn_01x09; JST_SH_SM09B-SRSS-TB_1x09-1MP_P1.00mm_Horizontal
L201: 1.5A; L_0805_2012Metric
LCD201: TFT_20_QT200H1201
LED701, LED704, LED707, LED708, LED712, LED716, LED717, LED720: SK6812-side-a_b
LED702, LED703, LED705, LED706, LED710, LED713, LED714, LED715, LED718, LED719: SK6812-mini-e
Q202: MMBT7002K; SOT-23
Q300, Q301, Q302, Q303, Q304, Q305, Q306, Q307, Q402, Q602: SI2301; SOT-523
Q401: BCM857; SOT-363_SC-70-6
Q601: MMDT3906; SOT-363_SC-70-6
R101, R502, R602, R603: 1K; R_0402_1005Metric
R102: DNF; R_0402_1005Metric
R103, R208, R608, R612: 200R; R_0402_1005Metric
R201, R204: 5.1K; R_0402_1005Metric
R202, R203: 22R; R_0402_1005Metric
R209: 33R; R_0805_2012Metric
R301, R313, R402, R406, R407, R410, R414, R415, R501, R606, R609, R610, R611, R613: 10K; R_0402_1005Metric
R316, R320: 510R; R_0402_1005Metric
R319, R401, R412: 100K; R_0402_1005Metric
R403: 102K; R_0402_1005Metric
R404: 133K; R_0402_1005Metric
R405, R408, R409, R604, R605: 33K; R_0402_1005Metric
R601: 0R2; R_2512_6332Metric_Pad1.40x3.35mm_HandSolder
RN301, RN305, RN306, RN309: 330R; R_Array_Convex_4x0402
RN302, RN304, RN307, RN310: 1M; R_Array_Convex_4x0402
RN303, RN308, RN317, RN318: 100K; R_Array_Convex_4x0402
RN311, RN312: 10K; R_Array_Convex_4x0402
RN315, RN400, RN401, RN402: 510R; R_Array_Convex_4x0402
SW101: SW_SPST; SW_SPST_PTS810
SW102: 4P_button_sw; GT-TC026X-HXXX-LX
U102: W25Q128JVSIQ; SOP-8_5.28x5.23mm_P1.27mm
U103: RP2040; RP2040-QFN-56
U105: MT29F1G01ABAFDWB; U-PDFN-8
U301, U302, U303, U304, U305, U306, U307, U308: AiP74LVC1T45GC363.TR; SOT-363_SC-70-6
U401: ME6211A33PG-N; SOT-89-3
U402: CD4067; TSSOP-24_4.4x7.8mm_P0.65mm
U403: AP2127; SOT-23-5
U404, U506, U603: LMV321; SOT-23-5
U501, U502: AIP74HC595TA; TSSOP-16_4.4x5mm_P0.65mm
U503: AIP74HCT245TA; TSSOP-20_4.4x6.5mm_P0.65mm
U504, U505: LMV324; TSSOP-14_4.4x5mm_P0.65mm
U601: LMV321A; SOT-23-5
U602: LMV331; SOT-23-5
Y101: 12Mhz; Crystal_SMD_3225-4Pin_3.2x2.5mm
logo1: fcc_logo; logo_fcc

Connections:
+1V1: C107.1, C117.1, C118.1, U103.23 (DVDD), U103.45 (VREG_VOUT), U103.50 (DVDD)
+3V3: C103.1, C104.1, C108.2, C110.1, C111.1, C112.1, C113.1, C114.1, C115.1, C116.1, C121.1, C301.2, C302.2, C303.2, C307.2, C308.2, C309.2, C313.2, C314.2, C402.1, C413.1, C414.2, C501.2, C502.2, C605.1, D601.1 (K), LCD201.4 (VCC), Q601.1 (E1), Q601.4 (E2), R102.1, R103.1, R501.1, R609.1, R613.1, SW102.4, U102.8 (VCC), U103.1 (IOVDD), U103.10 (IOVDD), U103.22 (IOVDD), U103.26 (RUN), U103.33 (IOVDD), U103.42 (IOVDD), U103.44 (VREG_IN), U103.48 (USB_VDD), U103.49 (IOVDD), U105.3 (WP/IO2), U105.7 (HOLD/IO3), U105.8 (VCC), U301.1 (VCCA), U302.1 (VCCA), U303.1 (VCCA), U304.1 (VCCA), U305.1 (VCCA), U306.1 (VCCA), U307.1 (VCCA), U308.1 (VCCA), U401.3 (VOUT), U501.10 (~SRCLR), U501.16 (VCC), U502.10 (~SRCLR), U502.16 (VCC), U602.5 (V+), U603.5 (V+)
+VUSB: C201.2, C202.2, C401.1, C403.2, C405.2, C406.1, C503.2, C504.2, C506.1, C507.2, C508.2, C509.2, C510.2, C601.1, C602.2, C701.2, C702.2, C703.2, C704.2, C705.2, C706.2, C707.2, C708.2, C710.2, C712.2, C713.2, C714.2, C715.2, C716.2, C717.2, C718.2, C719.2, C720.2, D500.3, D501.3, D502.3, D503.3, D504.3, L201.1, LCD201.3 (LED-A), LED701.3 (VDD), LED702.1 (VDD), LED703.1 (VDD), LED704.3 (VDD), LED705.1 (VDD), LED706.1 (VDD), LED707.3 (VDD), LED708.3 (VDD), LED710.1 (VDD), LED712.3 (VDD), LED713.1 (VDD), LED714.1 (VDD), LED715.1 (VDD), LED716.3 (VDD), LED717.3 (VDD), LED718.1 (VDD), LED719.1 (VDD), LED720.3 (VDD), R313.2, R320.2, R402.1, R601.1, R602.2, U401.2 (VIN), U402.24 (VCC), U404.5 (V+), U503.1 (A->B), U503.20 (VCC), U504.4 (V+), U505.4 (V+), U506.5 (V+), U601.5 (V+)
AMUX_EN: R402.2, RN315.1 (R1.1), U402.15 (~E)
AMUX_OUT: R406.2, R407.2, U103.40 (GPIO28_ADC2)
AMUX_S0: R316.1, U402.10 (S0)
AMUX_S1: RN315.4 (R1.1), U402.11 (S1)
AMUX_S2: RN315.3 (R1.1), U402.14 (S2)
AMUX_S3: RN315.2 (R1.1), U402.13 (S3)
BPIO0: J301.2, J302.1, RN305.1 (R1.1), RN312.1 (R1.1), RN318.8 (R1.8)
BPIO1: J301.3, J302.2, RN305.2 (R1.1), RN312.2 (R1.1), RN318.7 (R1.8)
BPIO2: J301.4, J302.3, RN305.3 (R1.1), RN312.3 (R1.1), RN318.6 (R1.8)
BPIO3: J301.5, J302.4, RN305.4 (R1.1), RN312.4 (R1.1), RN318.5 (R1.8)
BPIO4: J301.6, J302.5, RN309.1 (R1.1), RN311.1 (R1.1), RN317.8 (R1.8)
BPIO5: J301.7, J302.6, RN309.2 (R1.1), RN311.2 (R1.1), RN317.7 (R1.8)
BPIO6: J301.8, J302.7, RN309.3 (R1.1), RN311.3 (R1.1), RN317.6 (R1.8)
BPIO7: J301.9, J302.8, RN309.4 (R1.1), RN311.4 (R1.1), RN317.5 (R1.8)
BUFDIR0: RN303.8 (R1.8), U103.2 (GPIO0), U301.5 (DIR)
BUFDIR1: RN303.7 (R1.8), U103.3 (GPIO1), U302.5 (DIR)
BUFDIR2: RN303.6 (R1.8), U103.4 (GPIO2), U303.5 (DIR)
BUFDIR3: RN303.5 (R1.8), U103.5 (GPIO3), U304.5 (DIR)
BUFDIR4: RN308.8 (R1.8), U103.6 (GPIO4), U305.5 (DIR)
BUFDIR5: RN308.7 (R1.8), U103.7 (GPIO5), U306.5 (DIR)
BUFDIR6: RN308.6 (R1.8), U103.8 (GPIO6), U307.5 (DIR)
BUFDIR7: RN308.5 (R1.8), U103.9 (GPIO7), U308.5 (DIR)
BUFIO0: RN301.8 (R1.8), U103.11 (GPIO8)
BUFIO1: RN301.7 (R1.8), U103.12 (GPIO9)
BUFIO2: RN301.6 (R1.8), U103.13 (GPIO10)
BUFIO3: RN301.5 (R1.8), U103.14 (GPIO11)
BUFIO4: RN306.8 (R1.8), U103.15 (GPIO12)
BUFIO5: RN306.7 (R1.8), U103.16 (GPIO13)
BUFIO6: RN306.6 (R1.8), U103.17 (GPIO14)
BUFIO7: RN306.5 (R1.8), U103.18 (GPIO15)
BUTTONS: SW102.1, U103.39 (GPIO27_ADC1)
CURRENT_ADJ_MCU: R415.2, U103.34 (GPIO22)
CURRENT_DETECT: Q602.2 (S), R610.2, RN402.5 (R1.8), U602.4
CURRENT_EN: R612.2, R613.2, U502.1 (QB)
CURRENT_EN_OVERRIDE: D603.2 (A), U502.5 (QF)
CURRENT_RESET: R611.1, U502.3 (QD)
CURRENT_SENSE: R605.1, R606.2, U103.41 (GPIO29_ADC3), U601.4
DISPLAY_BACKLIGHT: R208.1, U501.5 (QF)
DISPLAY_CS: LCD201.8 (CS), U103.37 (GPIO25)
DISPLAY_DP: LCD201.7 (WR/SPI_A0), U103.36 (GPIO24)
DISPLAY_LED-K: LCD201.2 (LED-K), R209.2
DISPLAY_RESET: LCD201.11 (RESET), U501.6 (QG)
GND: C103.2, C104.2, C105.2, C106.2, C107.2, C108.1, C109.2, C110.2, C111.2, C112.2, C113.2, C114.2, C115.2, C116.2, C117.2, C118.2, C121.2, C201.1, C202.1, C301.1, C302.1, C303.1, C304.2, C305.2, C306.2, C307.1, C308.1, C309.1, C310.2, C311.2, C312.2, C313.1, C314.1, C315.2, C316.2, C401.2, C402.2, C403.1, C404.2, C405.1, C406.2, C407.2, C413.2, C414.1, C415.1, C416.1, C501.1, C502.1, C503.1, C504.1, C506.2, C507.1, C508.1, C509.1, C510.1, C601.2, C602.1, C603.1, C605.2, C701.1, C702.1, C703.1, C704.1, C705.1, C706.1, C707.1, C708.1, C710.1, C712.1, C713.1, C714.1, C715.1, C716.1, C717.1, C718.1, C719.1, C720.1, J201.1, J202.A1B12 (GND), J202.B1A12 (GND), J202.S1 (SHIELD), J202.S2 (SHIELD), J202.S3 (SHIELD), J202.S4 (SHIELD), J301.10, J302.9, LCD201.1 (GND), LCD201.5 (GND), LCD201.6 (GND), LCD201.12 (GND), LED701.1 (VSS), LED702.3 (VSS), LED703.3 (VSS), LED704.1 (VSS), LED705.3 (VSS), LED706.3 (VSS), LED707.1 (VSS), LED708.1 (VSS), LED710.3 (VSS), LED712.1 (VSS), LED713.3 (VSS), LED714.3 (VSS), LED715.3 (VSS), LED716.1 (VSS), LED717.1 (VSS), LED718.3 (VSS), LED719.3 (VSS), LED720.1 (VSS), Q202.2 (S), R201.1, R204.1, R301.2, R401.2, R405.2, R407.1, R409.2, R412.2, R604.1, RN302.1 (R1.1), RN302.2 (R1.1), RN302.3 (R1.1), RN302.4 (R1.1), RN303.1 (R1.1), RN303.2 (R1.1), RN303.3 (R1.1), RN303.4 (R1.1), RN304.5 (R1.8), RN304.6 (R1.8), RN304.7 (R1.8), RN304.8 (R1.8), RN307.1 (R1.1), RN307.2 (R1.1), RN307.3 (R1.1), RN307.4 (R1.1), RN308.1 (R1.1), RN308.2 (R1.1), RN308.3 (R1.1), RN308.4 (R1.1), RN310.5 (R1.8), RN310.6 (R1.8), RN310.7 (R1.8), RN310.8 (R1.8), SW101.2 (B), U102.4 (VSS), U103.19 (TESTEN), U103.57 (GND), U105.4 (VSS), U301.2 (GND), U302.2 (GND), U303.2 (GND), U304.2 (GND), U305.2 (GND), U306.2 (GND), U307.2 (GND), U308.2 (GND), U401.1 (GND), U402.12 (GND), U402.16 (I15), U402.17 (I14), U402.18 (I13), U402.19 (I12), U403.2 (GND), U404.2 (V-), U501.8 (GND), U502.8 (GND), U503.8 (A6), U503.10 (GND), U504.11 (V-), U505.11 (V-), U506.2 (V-), U601.2 (V-), U602.2 (V-), U603.2 (V-), Y101.2, Y101.4
LEDS_CDO: R502.1, U503.13 (B5)
MUX_BPIO0: RN401.5 (R1.8), U505.1, U505.2 (-)
MUX_BPIO1: RN401.6 (R1.8), U505.6 (-), U505.7
MUX_BPIO2: RN401.7 (R1.8), U505.8, U505.9 (-)
MUX_BPIO3: RN401.8 (R1.8), U505.13 (-), U505.14
MUX_BPIO4: RN400.5 (R1.8), U504.13 (-), U504.14
MUX_BPIO5: RN400.6 (R1.8), U504.8, U504.9 (-)
MUX_BPIO6: RN400.7 (R1.8), U504.1, U504.2 (-)
MUX_BPIO7: RN400.8 (R1.8), U504.6 (-), U504.7
MUX_VREF_VOUT: RN402.8 (R1.8), U506.3 (-), U506.4
unnamed: D401.2 (A), Q401.3 (C2), Q401.5 (B2), R408.2, R410.2
unnamed: C603.2, D601.2 (A), Q601.3 (C2), R606.1, U602.3 (-)
unnamed: D602.2 (A), Q602.3 (D)
unnamed: J202.A5 (CC1), R201.2
unnamed: J202.B5 (CC2), R204.2
unnamed: J202.A4B9 (VBUS), J202.B4A9 (VBUS), L201.2
unnamed: LED701.4 (DI), LED702.2 (DO)
unnamed: LED701.2 (DO), LED704.4 (DI)
unnamed: LED702.4 (DI), LED706.2 (DO)
unnamed: LED703.4 (DI), LED704.2 (DO)
unnamed: LED703.2 (DO), LED705.4 (DI)
unnamed: LED705.2 (DO), LED720.4 (DI)
unnamed: LED706.4 (DI), LED708.2 (DO)
unnamed: LED707.4 (DI), LED719.2 (DO)
unnamed: LED707.2 (DO), LED713.4 (DI)
unnamed: LED708.4 (DI), LED710.2 (DO)
unnamed: LED710.4 (DI), LED712.2 (DO)
unnamed: LED712.4 (DI), LED714.2 (DO)
unnamed: LED713.2 (DO), LED715.4 (DI)
unnamed: LED714.4 (DI), LED718.2 (DO)
unnamed: LED715.2 (DO), LED716.4 (DI)
unnamed: LED716.2 (DO), LED717.4 (DI)
unnamed: LED717.2 (DO), LED718.4 (DI)
unnamed: LED719.4 (DI), R502.2
unnamed: Q202.3 (D), R209.1
unnamed: Q202.1 (G), R208.2
unnamed: Q300.3 (D), RN311.6 (R1.8)
unnamed: Q301.3 (D), RN311.8 (R1.8)
unnamed: Q302.3 (D), RN311.7 (R1.8)
unnamed: Q303.3 (D), RN311.5 (R1.8)
unnamed: Q304.3 (D), RN312.6 (R1.8)
unnamed: Q305.3 (D), RN312.8 (R1.8)
unnamed: Q306.3 (D), RN312.7 (R1.8)
unnamed: Q307.3 (D), RN312.5 (R1.8)
unnamed: Q401.2 (B1), R410.1
unnamed: Q401.6 (C1), Q402.1 (G), R412.1
unnamed: Q601.2 (B1), R611.2
unnamed: Q601.6 (C1), R608.2, R609.2, R610.1
unnamed: Q601.5 (B2), R608.1
unnamed: Q602.1 (G), R612.1
unnamed: R408.1, R409.1
unnamed: RN301.1 (R1.1), RN302.8 (R1.8), U301.3 (A)
unnamed: RN301.2 (R1.1), RN302.7 (R1.8), U302.3 (A)
unnamed: RN301.3 (R1.1), RN302.6 (R1.8), U303.3 (A)
unnamed: RN301.4 (R1.1), RN302.5 (R1.8), U304.3 (A)
unnamed: RN304.1 (R1.1), RN305.8 (R1.8), U301.4 (B)
unnamed: RN304.2 (R1.1), RN305.7 (R1.8), U302.4 (B)
unnamed: RN304.3 (R1.1), RN305.6 (R1.8), U303.4 (B)
unnamed: RN304.4 (R1.1), RN305.5 (R1.8), U304.4 (B)
unnamed: RN306.1 (R1.1), RN307.8 (R1.8), U305.3 (A)
unnamed: RN306.2 (R1.1), RN307.7 (R1.8), U306.3 (A)
unnamed: RN306.3 (R1.1), RN307.6 (R1.8), U307.3 (A)
unnamed: RN306.4 (R1.1), RN307.5 (R1.8), U308.3 (A)
unnamed: RN309.8 (R1.8), RN310.1 (R1.1), U305.4 (B)
unnamed: RN309.7 (R1.8), RN310.2 (R1.1), U306.4 (B)
unnamed: RN309.6 (R1.8), RN310.3 (R1.1), U307.4 (B)
unnamed: RN309.5 (R1.8), RN310.4 (R1.1), U308.4 (B)
unnamed: RN315.8 (R1.8), U503.18 (B0)
unnamed: RN315.7 (R1.8), U503.17 (B1)
unnamed: RN315.6 (R1.8), U503.16 (B2)
unnamed: RN315.5 (R1.8), U503.15 (B3)
unnamed: D502.2, RN317.1 (R1.1), U504.12 (+)
unnamed: D502.1, RN317.2 (R1.1), U504.10 (+)
unnamed: D501.2, RN317.3 (R1.1), U504.3 (+)
unnamed: D501.1, RN317.4 (R1.1), U504.5 (+)
unnamed: D504.2, RN318.1 (R1.1), U505.3 (+)
unnamed: D504.1, RN318.2 (R1.1), U505.5 (+)
unnamed: D503.2, RN318.3 (R1.1), U505.10 (+)
unnamed: D503.1, RN318.4 (R1.1), U505.12 (+)
unnamed: RN400.1 (R1.1), U402.9 (I0)
unnamed: RN400.2 (R1.1), U402.8 (I1)
unnamed: RN400.3 (R1.1), U402.7 (I2)
unnamed: RN400.4 (R1.1), U402.6 (I3)
unnamed: RN401.1 (R1.1), U402.5 (I4)
unnamed: RN401.2 (R1.1), U402.4 (I5)
unnamed: RN401.3 (R1.1), U402.3 (I6)
unnamed: RN401.4 (R1.1), U402.2 (I7)
unnamed: RN402.1 (R1.1), U402.20 (I11)
unnamed: RN402.2 (R1.1), U402.21 (I10)
unnamed: RN402.4 (R1.1), U402.22 (I9)
unnamed: R101.2, SW101.1 (A)
unnamed: C109.1, R103.2, U103.43 (ADC_AVDD)
unnamed: C105.1, U103.20 (XIN), Y101.1
unnamed: C106.1, U103.21 (XOUT), Y101.3
unnamed: U402.1 (COM), U404.1 (+)
unnamed: R320.1, U402.23 (I8)
unnamed: C408.2, R403.2, R404.2, R405.1, U403.4 (ADJ)
unnamed: R406.1, U404.3 (-), U404.4
unnamed: U501.15 (QA), U503.2 (A0)
unnamed: U501.1 (QB), U503.6 (A4)
unnamed: U501.2 (QC), U503.5 (A3)
unnamed: U501.3 (QD), U503.4 (A2)
unnamed: U501.4 (QE), U503.3 (A1)
unnamed: U501.9 (QH'), U502.14 (SER)
unnamed: U501.7 (QH), U503.9 (A7)
unnamed: R316.2, U503.14 (B4)
unnamed: D500.1, R319.1, U506.1 (+)
unnamed: R602.1, R604.2, U601.1 (+)
unnamed: R603.1, R605.2, U601.3 (-)
unnamed: C416.2, R415.1, U602.1 (+)
unnamed: C415.2, R414.1, U603.1 (+)
PULLUP_EN: Q300.1 (G), Q301.1 (G), Q302.1 (G), Q303.1 (G), Q304.1 (G), Q305.1 (G), Q306.1 (G), Q307.1 (G), R313.1, U503.11 (B7)
QSPI_SCLK: U102.6 (CLK), U103.52 (QSPI_SCLK)
QSPI_SD0: U102.5 (DI), U103.53 (QSPI_SD0)
QSPI_SD1: U102.2 (DO), U103.55 (QSPI_SD1)
QSPI_SD2: U102.3 (WP), U103.54 (QSPI_SD2)
QSPI_SD3: U102.7 (HOLD), U103.51 (QSPI_SD3)
QSPI_SS: R101.1, R102.2, U102.1 (CS), U103.56 (QSPI_SS)
RGB_CDO: U103.28 (GPIO17), U503.7 (A5)
SD_CS: U103.38 (GPIO26_ADC0), U105.1 (CS)
SHIFT_EN: R501.2, U103.32 (GPIO21), U501.13 (~OE), U502.13 (~OE), U503.19 (CE)
SHIFT_LATCH: U103.31 (GPIO20), U501.12 (RCLK), U502.12 (RCLK)
SPI_CDI: U103.27 (GPIO16), U105.2 (SO/IO1)
SPI_CDO: LCD201.10 (SPI_SDA), U103.30 (GPIO19), U105.5 (SI/IO0), U501.14 (SER)
SPI_CLK: LCD201.9 (RS/SPI_SCL), U103.29 (GPIO18), U105.6 (SCK), U501.11 (SRCLK), U502.11 (SRCLK)
SWCLK: J201.3, U103.24 (SWCLK)
SWDIO: J201.2, U103.25 (SWD)
USB_D+: R203.1, U103.47 (USB_DP)
USB_D-: R202.1, U103.46 (USB_DM)
USB_N: J202.A7 (DN1), J202.B7 (DN2), R202.2
USB_P: J202.A6 (DP1), J202.B6 (DP2), R203.2
VREF_VOUT: C304.1, C305.1, C306.1, C310.1, C311.1, C312.1, C315.1, C316.1, J301.1, Q300.2 (S), Q301.2 (S), Q302.2 (S), Q303.2 (S), Q304.2 (S), Q305.2 (S), Q306.2 (S), Q307.2 (S), Q401.1 (E1), Q402.2 (S), R301.1, R319.2, U301.6 (VCCB), U302.6 (VCCB), U303.6 (VCCB), U304.6 (VCCB), U305.6 (VCCB), U306.6 (VCCB), U307.6 (VCCB), U308.6 (VCCB)
VREG_ADJ: R403.1, U603.3 (-), U603.4
VREG_ADJ_MCU: R414.2, U103.35 (GPIO23)
VREG_EN: D602.1 (K), D603.1 (K), R401.1, U403.3 (SHUTDOWN)
VREG_OUT: C407.1, C408.1, D401.1 (K), Q401.4 (E2), Q402.3 (D), R404.1, RN402.7 (R1.8), U403.5 (OUT)
VREG_VIN: C404.1, R601.2, R603.2, U403.1 (VIN)

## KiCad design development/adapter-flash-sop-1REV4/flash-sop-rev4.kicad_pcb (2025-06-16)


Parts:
C1, C2: 0.1uF; C_0805_2012Metric; not fitted
D1: LED; LED_0805_2012Metric
J1: Conn_01x10; PinSocket_1x10_P2.54mm_Horizontal
J2: Conn_01x10; PinHeader_1x10_P2.54mm_Vertical; not fitted
J3: 16PIN; 16PIN_SCOKET
J5: 20PIN; 20PIN_SCOKET
R1: 2K; R_0805_2012Metric
SW1, SW2: SW_SPDT; SW_SPDT_PCM12

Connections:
CDI: J1.6, J2.6, J3.2, J3.6, J5.2, J5.8
CDO: J1.9, J2.9, J3.9, J3.13, J5.11, J5.17
CS: J1.7, J2.7, J3.1, J3.5, J5.1, J5.7
GND: D1.1 (K), J1.10, J2.10, SW2.1 (A)
GND_CHIP: C1.2, C2.2, J3.4, J3.8, J5.4, J5.10, SW2.2 (B)
GND_PIN: J1.3, J2.3, SW2.3 (C)
HOLD: J1.4, J2.4, J3.11, J3.15, J5.13, J5.19
unnamed: D1.2 (A), R1.2
SCLK: J1.8, J2.8, J3.10, J3.14, J5.12, J5.18
VCC_CHIP: C1.1, C2.1, J3.12, J3.16, J5.14, J5.20, SW1.2 (B)
VCC_PIN: J1.2, J2.2, SW1.1 (A)
VOUT: J1.1, J2.1, R1.1, SW1.3 (C)
WP: J1.5, J2.5, J3.3, J3.7, J5.3, J5.9


Board: 2 copper layers, 42.8 x 42.0 mm, 10 parts (0 on the bottom side), 13 nets.

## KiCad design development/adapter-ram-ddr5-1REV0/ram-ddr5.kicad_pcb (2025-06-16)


Board: 2 copper layers, 26.0 x 154.5 mm, 23 parts (0 on the bottom side), 19 nets.

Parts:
C4, C5: 10uF/6.3V; C_0805_2012Metric
D2, D3: LED; LED_0805_2012Metric
J1: DDR504111002KQ; DDR5 UDIMM GENERIC
J2: Conn_01x10; PinSocket_1x10_P2.54mm_Horizontal
J3: Conn_01x10; PinHeader_1x10_P2.54mm_Vertical
J4: 10160554-001SHLF; AMPHENOL_10160554-001SHLF
Q1, Q2: 2N7002; SOT-23
Q5: BC807; SOT-23
Q6: BC817; SOT-23
R2, R12, R13: 6.8K; R_0805_2012Metric
R3, R4, R6, R7: 2K; R_0805_2012Metric
R8: 1K; R_0805_2012Metric
R10: 680R; R_0805_2012Metric
R11: 330R; R_0805_2012Metric
U2: MCP1700x-330xxTT; SOT-23

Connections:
+3.3V: C5.1, J1.151, J4.8, Q1.1 (G), Q2.1 (G), R2.1, R6.2, R7.2, R10.2, R12.1, U2.2 (VO)
BULK_VIN: C4.1, J1.01, J1.145, J1.146, J2.1, J3.1, J4.1, J4.3, R3.2, R4.2, R13.2, U2.3 (VI)
GND: C4.2, C5.2, D2.1 (K), J1.148, J1.150, J2.10, J3.10, J4.2, J4.9, J4.10, J4.SH, Q6.2 (E), R11.1, U2.1 (GND)
HSCL: J1.04, J4.4, Q2.2 (S), R7.1
HSDA: J1.05, J4.6, Q1.2 (S), R6.1
unnamed: D2.2 (A), R2.2
unnamed: D3.2 (A), R12.2
unnamed: J2.5, J3.5
unnamed: J2.6, J3.6
unnamed: J2.7, J3.7
unnamed: J2.8, J3.8
unnamed: J2.9, J3.9
unnamed: Q5.1 (B), R8.2
unnamed: Q5.3 (C), Q6.1 (B)
unnamed: Q5.2 (E), R10.1, R11.2
PWR_GOOD: J1.147, J4.7, R8.1
PWR_GOOD_OUT: D3.1 (K), J2.4, J3.4, Q6.3 (C), R13.1
SCL: J2.3, J3.3, Q2.3 (D), R4.1
SDA: J2.2, J3.2, Q1.3 (D), R3.1

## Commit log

2023-09-21 Bus Pirate 5 hardware initial check in
    [BusPirate-5-rev8-B_Cu.gbl, BusPirate-5-rev8-B_Mask.gbs, BusPirate-5-rev8-B_Paste.gbp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]
2023-11-26 Bus Pirate REV10. KF141r/v boards.
    [705550044.stp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]
2023-11-28 KF141 adapters REV2 - tighter spacing.
    [wago kf141r adapter-B_Cu.gbl, wago kf141r adapter-B_Mask.gbs, wago kf141r adapter-B_Paste.gbp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]
2023-11-30 Add pulldown on VREF. Change VUSB MUX series resistor to 510R. May be other value updates that didn't get checked in previously.
    [BusPirate-5-rev10.kicad_pcb, BusPirate-5-rev10.kicad_sch, IO-expand-595-mux.kicad_sch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]
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2023-12-02 REV10: add missing LED, fix LED placement.
    [BusPirate-5-rev10-B_Cu.gbl, BusPirate-5-rev10-B_Mask.gbs, BusPirate-5-rev10-B_Paste.gbp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]
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2024-02-22 REV10 correct PCB. Renamed 10a for clarity.
    [IO-expand-595-mux.kicad_sch, IO-expand-595-mux.sch, REV10a.csv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]
2024-02-22 mvoe kf011c up one folder
    [5145300-3.step, kf011c.kicad_pcb, kf011c.kicad_sch]
2024-02-22 wago quick connect cleanup
    [wago kf141r adapter-B_Cu.gbl, wago kf141r adapter-B_Mask.gbs, wago kf141r adapter-B_Paste.gbp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]
2024-02-22 kf141 update files and ignore
    [wago kf141r adapter.csv, wago kf141v adapter.csv]
2024-02-22 kf011c move to correct folder
    [5145300-3.step, kf011c.kicad_pcb, kf011c.kicad_sch]
2024-04-25 remove beta smartcard board
    [5145300-3.step, kf011c.kicad_pcb, kf011c.kicad_sch]
2024-04-25 add DIP, SOP, WSON SPI flash adapter boards
    [flash-sop-rev3.csv, flash-sop-rev3.kicad_pcb, flash-sop-rev3.kicad_sch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]
2024-07-11 SOP8 SPI Flash socket LOTES version
    [flash-sop-lotes-rev3.csv, flash-sop-lotes-rev3.kicad_pcb, flash-sop-lotes-rev3.kicad_sch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]
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2024-10-16 remove old pullups, remove 1M pull-down. Add footprints and updated PCB.
    [7-REV0.kicad_pcb, IO-expand-595-mux.kicad_sch, bpu-iobufffer.kicad_sch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]
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2024-10-20 Update enclosure kicad files - remove "mask" from diff to work with recent OpenSCAD and BOSLII
    [BusPirate5REV10-v0.scad, BusPirate5REV8-v10.scad]
2024-10-20 minor updates to collaborative board redesign
    [IO-expand-595-mux.kicad_sch, micro-rp2040.kicad_sch, pull-x-resistors.kicad_sch]
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2024-11-05 BP7 REV1 missing files
    [7-REV1.csv, 7-REV1.kicad_pcb, 7-REV1.kicad_sch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]
2024-11-12 Add VOUT protection from electronic_eel: https://forum.buspirate.com/t/port-protection-for-rev7/712/37 . Minor cleanup of top page.
    [7-REV1.kicad_sch, aux_voltages.kicad_sch, vout_protection.kicad_sch]
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2024-11-20 Blank Plank prototyping board with proto pattern from http://git.io/vNUDX CC-BY-4.0
    [5145300-3.step, DGLZ-SIM-0004.step, blank-plank-rev0b.kicad_pcb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]
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2025-02-18 change to 27R usb termination resistors as recommended by RasPi (7-REV1)
    [7-REV1.kicad_sch, IO-expand-595-mux.kicad_sch, aux_voltages.kicad_sch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]
2025-02-18 change to 27R usb termination resistors as recommended by RasPi (7-rev0a)
    [7-REV0.kicad_sch, IO-expand-595-mux.kicad_sch, bpu-current_limiter.kicad_sch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]
2025-02-18 update aux voltage creation
    - 100pF/200k RC oscillator for reduced current consumption
    - set footprints to 0402, use default symbols that are used in other parts of the schematics
    - use 4.7µF / 0402 cap for -5V:
    I guess we can get by with this as we don't have that much bias, so the cap loss should be ok
    - use 10µF / 0805 for 9V:
    Too high voltage for a smaller part, voltage biassing would kill nearly all capacitance
    [aux_voltages.kicad_sch]
2025-02-18 adapt protection for the AP2127 voltage regulator
    - add a PMEG2020EJ for backflow-handling
    - remove the previous backflow protection circuit
    - remove the AP2127+circuit from the "VOUT protection" sheet, it was redundant
    [bpu-current_limiter.kicad_sch, vout_protection.kicad_sch]
2025-02-18 reduce BOM lines by changing the Vaux oscillator to 120pF || 180k
    [aux_voltages.kicad_sch]
2025-02-18 adapt the IO-port protection
    - move to the bpu-iobuffer sheet, remove duplicate on VOUT-protection
    - use SP3002-04JTG in SOT363 instead of the larger IP4220CZ6F
    - add datasheet, resistor wattage to part fields
    [bpu-iobufffer.kicad_sch, vout_protection.kicad_sch]
2025-02-18 add ESD protection for the USB port too
    [micro-rp2040.kicad_sch]
2025-02-18 change the decoupling caps for the SP3002-04JTG TVS diodes to 4.7µF
    Lower impedanced decoupling, can absorb more energy fast
    [bpu-iobufffer.kicad_sch, micro-rp2040.kicad_sch]
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2025-02-18 replace MMBT7002K in SOT-23 with 2N7002T in SOT-523
    [micro-rp2040.kicad_sch, vout_protection.kicad_sch]
2025-02-18 replace one more MMBT7002K in SOT-23 with 2N7002T in SOT-523 (display led backlight)
    [IO-expand-595-mux.kicad_sch]
2025-02-18 replace 10µF / 0402 cap with 4.7µF / 0402 to save one BOM line
    - new reset / bootloader circuit
    - adjust resistor to 560k
    - exact values have to be tested (cap varies by mfg due to voltage derating)
    [micro-rp2040.kicad_sch]
2025-02-18 add DFN1010D-3 / SOT1215 footprint for PMXB56EN mosfets
    [vout_protection.kicad_sch]
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2025-02-19 BP7 REV 0a: 2.2uF, 4.7uF -> 10uF/6.3V CL05A106MQ5NUN
    [bpu-current_limiter.kicad_sch, micro-rp2040.kicad_sch]
2025-02-19 BP7REV1 2.2uF, 4.7uF-> 10uF/6.3V CL05A106MQ5NUN. 520K->470K on reset/bootloader switch.
    [aux_voltages.kicad_sch, bpu-current_limiter.kicad_sch, bpu-iobufffer.kicad_sch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]
2025-02-19 remove gate series resistor for the display backlight - it is unnecessary
    [IO-expand-595-mux.kicad_sch]
2025-02-19 specify part numbers and manufacturers in more detail - 10µF / 0805 caps - 2N7002KT fets
    [7-REV1.kicad_sch, IO-expand-595-mux.kicad_sch, aux_voltages.kicad_sch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]
2025-02-19 use a 1N4148WT instead of BAS40-04 in the VOUT protection
    - used to pull low the aux voltage when the external voltage is lower than -5V
    - SOD-523 is smaller than SOT-523
    - The BAS40-04 was easier blown in ESD/surge tests.
    Placement solved this, but the 1N4148WT will be more resilient
    - The increased forward voltage shouldn't matter, we must just go low enough to not turn on the FETs
    [vout_protection.kicad_sch]
2025-02-19 improve TCA6416ARTWR schematics - connect exposed pad to GND - mark unused INT pin as such
    [pull-x-resistors.kicad_sch]
2025-02-19 improve decoupling for the memory ICs (NOR, NAND, PSRAM) - do not use 100nF 0402 || 10µF 0402 - just use 10µF 0402 - the lowest impedance and resonance freq is mostly determined by size - so the 100n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
    [micro-rp2040.kicad_sch]
2025-02-19 move LCD background LED current limiting resistor from cathode to anode
    - there were several soldering defects on the LCD connector observed during manufacturing
    - often the LEDs were shorted to ground
    - this modification will protect the LEDs and the traces in this case, making rework easier
    [IO-expand-595-mux.kicad_sch]
2025-02-19 change resistor naming from k to K to unify BOM lines
    change the gate pullup resistor from 20k to 18k to remove one BOM line
    [micro-rp2040.kicad_sch, vout_protection.kicad_sch]
2025-02-19 mark some more unconnected pins as such
    LM358 DFN from ST: "the exposed pad can be left floating or connected to GND" -> leave it floating as it is now
    [IO-expand-595-mux.kicad_sch, leds.kicad_sch, micro-rp2040.kicad_sch]
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2025-02-24 Remove DNF footprints, locate PWM pins for power supply adjustment. Change PWM op-amp to DFN and buffer also the CURRENT_ADJ. Remove a FET gate resistor from current limiter.
    [7-REVA-PC1.kicad_sch, IO-expand-595-mux.kicad_sch, bpu-current_limiter.kicad_sch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]
2025-02-24 Remove VREG bypass diode. Fix XL9555 I2C address
    [IO-expand-595-mux.kicad_sch, bpu-current_limiter.kicad_sch]
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2025-02-25 Change XL9555 I2C address to advance from TCA6416ARTWR. Change adjustable voltage regulator to correct part number.
    [IO-expand-595-mux.kicad_sch, bpu-current_limiter.kicad_sch]
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2025-06-16 reorg, but forgot to check changes first :(
    [3D_PCB1_2025-05-14(1).STEP, 3D_PCB1_2025-05-14(2).STEP, 3D_PCB1_2025-05-14.STEP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]
2025-06-16 Reorganization of hardware repo. In development and unreleased boards moved to "development" folder. Cleanup and rename Bus Pirate PCB versions.
    [3D_PCB1_2025-05-14(1).STEP, 3D_PCB1_2025-05-14(2).STEP, 3D_PCB1_2025-05-14.STEP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]
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2025-06-18 kaybee plank - change pull-up resistor supply source
    [kaybee-plank.kicad_pcb, kaybee-plank.kicad_sch]
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
